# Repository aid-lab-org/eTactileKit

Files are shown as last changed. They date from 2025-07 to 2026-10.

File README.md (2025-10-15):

# eTactileKit: A Toolkit for Design Exploration and Rapid Prototyping of Electro-Tactile Interfaces

<p align="center">
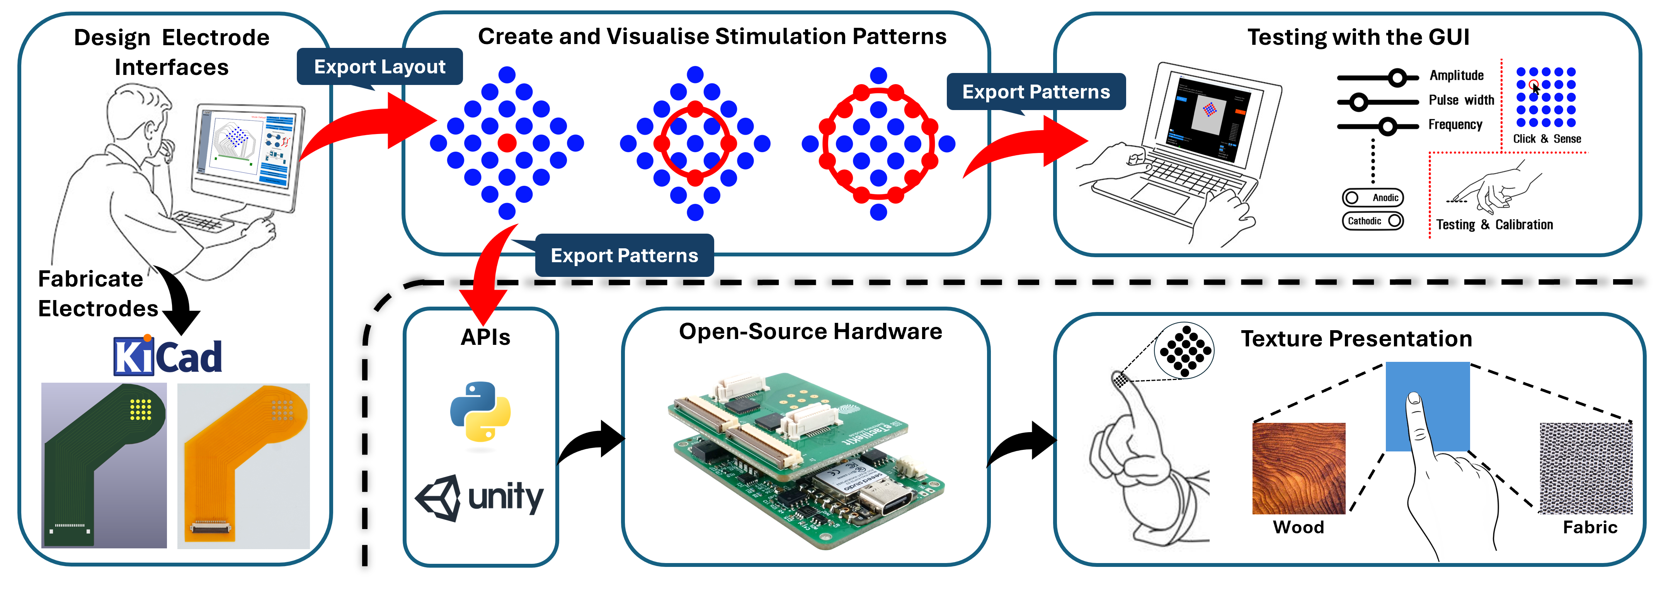
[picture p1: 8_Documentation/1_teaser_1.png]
Image Description
  
</p>

## Abstract

Electro-tactile interfaces are becoming increasingly popular due to their unique advantages, such as delivering fast and localised tactile response, thin and flexible form factors, and the potential to create novel tactile experiences. However, insights from a formative study with typical designers highlighted the lack of resources, limited access to information and complexity of software and hardware tools. This establishes a high barrier to entry and limits the ability to rapidly prototype and experiment with electro-tactile interfaces. To address these challenges, we propose eTactileKit, a scalable and accessible toolkit providing end-to-end support for designing and prototyping electro-tactile interfaces. eTactileKit comprises a hardware platform and a software framework for designing, simulating and exploring electro-tactile stimuli. We evaluated the impact and usability of eTactileKit through a three-week long take-home study, which demonstrated increased accessibility, ease of use, and the toolkit's positive impact on design workflow. Additionally, we implemented a set of use cases to demonstrate the toolkit's practicality and effectiveness across various applications.

More information about the toolkit can be found in our [paper](https://doi.org/10.1145/3746059.3747796). If you use this work, please cite our paper:

```
Praneeth Bimsara Perera, Ravindu Madhushan Pushpakumara, Hiroyuki Kajimoto, Arata Jingu, Jürgen Steimle,
and Anusha Withana. 2025. eTactileKit: A Toolkit for Design Exploration and Rapid Prototyping of
Electro-Tactile Interfaces. In The 38th Annual ACM Symposium on User Interface Software and Technology (UIST ’25),
September 28–October 01, 2025, Busan, Republic of Korea. ACM, New York, NY, USA, 17 pages.
https://doi.org/10.1145/3746059.3747796
```

## Contributors

**[Praneeth Perera](https://www.github.com/PraneethPerera99), [Ravindu Pushpakumara](https://www.github.com/RavinduMPK), [Hiroyuki Kajimoto](https://kaji-lab.jp/en/index.php?people/kaji), [Arata Jingu](https://hci.cs.uni-saarland.de/people/arata-jingu/), [Jürgen Steimle](https://hci.cs.uni-saarland.de/people/juergen-steimle/), [Anusha Withana](https://www.github.com/wdanusha)**

## Documentation

To use our toolkit, you can find the complete documentation [here](8_Documentation/DOCUMENTATION.md). This guide is here to help you navigate and make the most of eTactileKit.

## License

Shield: [][cc-by-sa]

This work is licensed under a
[Creative Commons Attribution-ShareAlike 4.0 International License][cc-by-sa].

[][cc-by-sa]

[cc-by-sa]: http://creativecommons.org/licenses/by-sa/4.0/
[cc-by-sa-image]: https://licensebuttons.net/l/by-sa/4.0/88x31.png
[cc-by-sa-shield]: https://img.shields.io/badge/License-CC%20BY--SA%204.0-lightgrey.svg

## Contact
If you have any issues with eTactileKit, please contact [Praneeth Perera](https://www.github.com/PraneethPerera99) or [Ravindu Pushpakumara](https://www.github.com/RavinduMPK)

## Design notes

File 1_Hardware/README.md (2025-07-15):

# Electro-tactile Toolkit Hardware Resources

This folder contains the:
1. PCB designs.
2. Fabrication outputs to manufacture PCBs.
3. Resource folder containing Schematics and images of the PCbs.

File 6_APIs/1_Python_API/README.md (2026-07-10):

# eTactileKit Python API

Reference Python client for the **eTactileKit** electro-tactile hardware (Seeed XIAO
ESP32-S3). It speaks a compact binary protocol over **Serial** or **WiFi (TCP)** and is
the source of truth the Unity API mirrors.

- `api/etactilekit.py` – high-level device driver (electrode mapping, stim parameters,
  patterns, voltage read-back).
- `api/communication.py` – transports: `CommunicationSerial` and `CommunicationWiFi`.
- `api/discovery.py` – UDP broadcast discovery to find kits by unique ID (WiFi/STA).
- `test_serial.py`, `test_wifi.py` – runnable examples (arrow keys change amplitude, `q` quits).

## Requirements

```bash
pip install pyserial          # required for serial
# pip install zeroconf        # optional: only for the mDNS browsing snippet below
```

Python 3.8+. WiFi discovery uses only the standard library (`socket`).

---

## Connection modes at a glance

| Mode | How you address the board | Use when | Needs |
|---|---|---|---|
| **Serial (USB)** | `COMx` + baud `921600` | one board, wired, lowest latency | USB cable |
| **WiFi · discovery (STA)** | unique 6-hex **ID** (auto) | **workshops / many kits on one router** | shared router |
| **WiFi · mDNS (STA)** | `etactilekit-<ID>.local` | single board, Python/macOS convenience | mDNS on the LAN |
| **WiFi · AP fallback** | fixed IP `192.168.4.1` | no router / 1 PC ↔ 1 kit | join the kit's SSID |
| **WiFi · DHCP reservation** | a fixed IP you reserve | permanent lab setup | router admin access |

Every board derives a **unique ID** from its MAC at boot (e.g. `A1B2C3`). Once the kits are
on the network, list them all — IDs and current IPs — with the discovery script:

```bash
python -m api.discovery
# Found 2 board(s):
#   id=A1B2C3  ip=192.168.1.42:8080  mode=STA  name=etactilekit-A1B2C3
#   id=7F0C11  ip=192.168.1.57:8080  mode=STA  name=etactilekit-7F0C11
```

Write each board's ID on its label so you can pick it later. **With a single kit you don't even
need the ID** — `connect_by_discovery()` (the default `device_id=None`) just connects to the only
board found.

---

## 1. Serial (USB)

```python
from api.etactilekit import ETactileKit

etk = ETactileKit()
etk.connect_etactilekit_to_serial("COM12", 921600, timeout=0.005)  # Linux/macOS: "/dev/ttyACM0"
```

Run the example:

```bash
python test_serial.py        # edit PORT_1_NAME / BAUDRATE at the top first
```

> The ESP32-S3 USB-Serial-JTAG RX FIFO drops bytes if flooded; `CommunicationSerial`
> already paces writes in small chunks, so any payload size is safe.

## 2. WiFi — discovery (recommended for STA / multiple kits)

All kits join **one router** you control, then you find them by ID over UDP broadcast —
no need to know the DHCP-assigned IP, and it works even where mDNS does not.

```python
from api.etactilekit import ETactileKit

etk = ETactileKit()
etk.connect_by_discovery(device_id="A1B2C3")   # None = the only board found
```

List every kit in the room first (also runnable as `python -m api.discovery`):

```python
from api.discovery import discover_devices

for d in discover_devices(timeout=1.0):
    print(d)   # {'id': 'A1B2C3', 'name': 'etactilekit-A1B2C3', 'ip': '192.168.1.42', 'port': 8080, 'mode': 'STA'}
```

`test_wifi.py` uses this path by default — set `TARGET_DEVICE_ID` to pick a specific kit.

> Requirements: the PC and the kits must be on the **same subnet**, and the router must
> allow UDP broadcast between clients (disable "client isolation"/"AP isolation").

## 3. WiFi — mDNS (secondary, Python only)

Each board also advertises `etactilekit-<ID>.local` and the `_etactilekit._tcp` service
(TXT `id=<ID>`). On Windows/macOS you can connect straight to the hostname:

```python
etk.connect_etactilekit_to_wifi("etactilekit-A1B2C3.local", 8080, timeout=0.10)
```

Or browse all of them with `zeroconf` (`pip install zeroconf`):

```python
from zeroconf import Zeroconf, ServiceBrowser

class Listener:
    def add_service(self, zc, type_, name):
        info = zc.get_service_info(type_, name)
        if info:
            ip = ".".join(map(str, info.addresses[0]))
            print(name, ip, info.properties.get(b"id"))

ServiceBrowser(Zeroconf(), "_etactilekit._tcp.local.", Listener())
```

> Note: **Unity/.NET cannot resolve `.local`** — that is why the UDP discovery above is
> the primary, cross-platform mechanism. Prefer it unless you are Python-only.

## 4. WiFi — AP fallback (no router)

If a board can't join the configured network it starts its own hotspot with a **unique
SSID** `eTactileKit_<ID>` (password `etactile@al`). Join that Wi-Fi, then:

```python
etk.connect_etactilekit_to_wifi("192.168.4.1", 8080, timeout=0.10)
```

One PC pairs with one kit this way (a PC can only join one AP at a time).

## 5. WiFi — DHCP reservation (deterministic, no discovery)

For a permanent setup, reserve a fixed IP per board on your router keyed by its MAC
(shown in the router's client list, or alongside the ID via `python -m api.discovery`). Then
just connect to that IP:

```python
etk.connect_etactilekit_to_wifi("192.168.1.50", 8080, timeout=0.10)
```

---

## After connecting (same for every mode)

```python
etk.set_electrode_mapping(list(range(32)))
etk.send_electrode_number(32)
etk.send_stimulation_mode(0)          # 0 monophasic, 1 biphasic
etk.send_stimulation_pulse_width(100) # µs
etk.send_stimulation_frequency(50)    # Hz
etk.send_channel_discharge_time(50)   # µs
print("sync:", etk.sync_check())      # echoes the configured electrode count
etk.send_stim_pattern([300] * 32)     # one 12-bit intensity (0–4095) per electrode
```

## Troubleshooting

| Symptom | Check |
|---|---|
| `discover_devices()` returns `[]` | PC and kits on the same router/subnet? Router blocking broadcast (client isolation)? Firewall blocking inbound UDP:8888? Did the board fall back to AP mode? (its `eTactileKit_<ID>` SSID would show in your Wi-Fi list). |
| "Multiple boards found" | Pass `device_id=` (or set `TARGET_DEVICE_ID`) with the kit's 6-hex code. |
| `.local` connects in Python but not Unity | Expected — use UDP discovery for Unity. |
| Can't connect in AP mode | Join the board's `eTactileKit_<ID>` Wi-Fi first; it's always `192.168.4.1`. |
| Serial: no device / garbled | Correct `COMx` and `921600` baud; not held by another app. |

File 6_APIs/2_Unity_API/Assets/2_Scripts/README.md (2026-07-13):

# eTactileKit Unity API

This package integrates the **eTactileKit** electro-tactile hardware into Unity. It speaks the same
byte protocol as the reference Python API and gives you a small, clean set of components to:

- connect to the device (Serial or WiFi),
- load a per-electrode **calibration profile** (intensity + hardware mapping),
- define **tactile patterns** in code, and
- trigger those patterns from **collider penetration** in your scene.

There is intentionally **no UI** and **no hand rig** - just the API plus an example controller you can
drop onto any colliders (a tracked finger, a tool tip, etc.).

> Deploying to a **Quest 3 standalone build** (running on the headset, WiFi-only)? See
> [APP_TRANSITION.md](APP_TRANSITION.md) for the full Android/IL2CPP transition guide. This README
> covers the PC / Quest Link setup that both targets share.

---

## 1. Project setup (do this first)

1. **Api Compatibility Level** → `.NET Framework`
   `Project Settings ▸ Player ▸ Other Settings ▸ Configuration ▸ Api Compatibility Level`.
   Required for `System.IO.Ports` (serial) and `System.Net.Sockets` (WiFi).
2. **Active Input Handling** → `Both`
   `Project Settings ▸ Player ▸ Other Settings ▸ Active Input Handling`.
3. **Install the Meta XR All-in-One SDK** (`com.meta.xr.sdk.all`) via the Package Manager (Unity
   Registry / Git URL), plus any other plugins your headset needs. This provides the VR hands /
   controllers you will attach the probe colliders to.

> Serial note: on Windows the device typically enumerates as `COMx` (e.g. `COM12`) at `921600` baud.
>
> WiFi note: Unity connects by **IP address** or by **UDP discovery** (see §5). Unity/.NET has
> **no mDNS resolver**, so the board's `etactilekit-<ID>.local` hostname will **not** resolve here -
> use discovery (recommended) or a raw IP. Each board self-labels with a unique 6-hex `ID` (from its
> MAC); list every kit's ID and IP with the Python discovery script (`python -m api.discovery`), or
> read them from the Unity Console when the manager connects. With a single kit you need no ID at all.

---

## 2. How it fits together

```text
HapticController            (your scene)
  ├─ reads probe colliders, finds the deepest penetration each frame
  ├─ resolves the touched object's HapticProfile via HapticProfileProvider
  └─ plays the profile's pattern (frame timing + Once/Loop/Bounce)
        │
        ▼
ETactileKitManager         (connection + calibration + global params)
  └─ SendFrame(states): on-electrodes → calibrated intensity, off → 0
        │
        ▼
ETactileKit                (0_eTactileKitAPI: byte protocol port)
  └─ remaps to hardware channels, packs uint16 LE, writes one packet
        │
        ▼
Serial / WiFi handler  →  ESP32 hardware
```

| Concept | Script | Role |
|---|---|---|
| Device driver | `0_eTactileKitAPI/ETactileKit.cs` | Low-level protocol (no Unity types). |
| Transport | `SerialHandler.cs` / `WiFiHandler.cs` | Serial (chunked) / TCP I/O. |
| Discovery | `0_eTactileKitAPI/ETactileKitDiscovery.cs` | Find kits on the LAN by unique ID (UDP broadcast). |
| Manager | `1_Haptics/ETactileKitManager.cs` | Connection, global params, calibration, `SendFrame`. |
| Calibration | `CalibrationProfile.cs` | Per-electrode intensity + hardware mapping. |
| Patterns | `PatternDB.cs` | Code-defined `HapticPattern`s (frames + playback mode). |
| Profile asset | `HapticProfile.cs` | Which pattern + trigger depth for an object. |
| Provider | `HapticProfileProvider.cs` | Attaches a profile to an object. |
| Controller | `HapticController.cs` | Penetration → pattern playback. |

---

## 3. Calibration

Calibration stores **only** two things per electrode: the hardware **mapping** and the **intensity**
applied when that electrode is on. Everything else (pulse width, frequency, stim mode, …) is a global
parameter on the manager.

- **Generate a profile** with the **eTactileKitExplorer** desktop application, which exports the
  calibration JSON used here (per-electrode `mapping` + `intensity`).
- **Where it lives:** put the profile in `Assets/StreamingAssets/`. A sample is provided at
  `Assets/StreamingAssets/template_32_electrode_calibration.json` so it travels with the cloned repo.
- On the `ETactileKitManager`, set **Default Calibration File Name** to the file name inside
  `StreamingAssets` (default: `template_32_electrode_calibration.json`). It loads automatically on
  `Start` when no profile has been set in the inspector.
- In the manager inspector, **Calibration Profile** lets you **Import JSON** / **Export JSON** (the
  same format eTactileKitExplorer produces) and tune each electrode's **Intensity** directly.

### Global amplitude (gain)

The manager's **Amplitude Gain** slider scales **every** electrode's calibrated intensity as it is
sent, so you can adjust overall strength in one place while keeping the per-electrode balance from
calibration:

- Range **0 – 1.5**, default **1** (1 = use the calibration values exactly as they are).
- The scaled value is **rounded to the nearest integer** (the hardware only takes integers) and
  **clamped to the 12-bit DAC range** (0 – 4095), so a high calibration value with a gain above 1 can
  never overflow.
- It applies **live** - drag the slider while playing and the next frame uses it; no reconnect or
  re-calibration needed. It does not modify the calibration profile itself.
- From code: `manager.AmplitudeGain = 0.8f;` (clamped to the same range).

The manager runs this one-time setup on connect (mirrors the Python reference order):

```text
set mapping → electrode number → stim mode → polarity → pulse width →
sense pulse height → sense pulse width → channel discharge time → frequency →
read HV513 count → sync check
```

---

## 4. Creating a tactile pattern

Patterns are defined in code in `1_Haptics/PatternDB.cs`. A pattern is a list of **frames**; each
frame **lists the electrode ids that are ON** (value 1) plus an **on-time** and **off-time**
(milliseconds). When a frame is sent, each listed electrode is driven at its calibrated intensity and
all others are off. Listing active ids keeps patterns **independent of the electrode count** - that
count comes from the loaded calibration profile and is never hard-coded.

A pattern also has a **playback mode**:

- `Once` – play the frames one time, then stay silent until the probe re-enters.
- `Loop` – repeat frames `0..N-1` continuously while penetrated.
- `Bounce` – play frames forward then backward (ping-pong) while penetrated.

The two example patterns (`HorizontalScan`, `VerticalScan`) are authored by hand for the default
"Fingerpad TactDeform 32" layout - a 6×6 grid with the four corners removed:

```text
        col0  col1  col2  col3  col4  col5
 row0:    ·     0     1     2     3     ·
 row1:    4     5     6     7     8     9
 row2:   10    11    12    13    14    15
 row3:   16    17    18    19    20    21
 row4:   22    23    24    25    26    27
 row5:    ·    28    29    30    31     ·
```

`HorizontalScan` lights one **column** per frame (a vertical bar moving left→right); `VerticalScan`
lights one **row** per frame.

Patterns can be authored two ways:

- **Manual** – list the active ids per frame (`HorizontalScan`, `VerticalScan`). Best for spatial
  shapes tied to your electrode layout.
- **Programmatic** – build frames with a loop from the electrode count (`Blink`, `Buzz`). These take
  the active count so they work for any layout, and the result is cached:
  - `Blink` – all electrodes on for 200 ms, off for 200 ms, looping.
  - `Buzz` – one electrode per frame, 40 ms on / 0 ms off, scanning through all of them.

To add your own pattern:

1. Add a value to the `PatternId` enum.
2. Build a `HapticPattern` – either list the active ids per frame, or generate them in a loop (see
   `Blink` / `Buzz`).
3. Return it from `PatternDB.Get(id, electrodeCount)`.

If your hardware numbers electrodes differently, adjust the ids per frame to match. Ids outside the
active electrode range are ignored with a warning.

---

## 5. Example scene, step by step

1. **Manager** – create an empty GameObject, add `ETactileKitManager`.
   - **Serial:** choose `Serial` and set `Port Name` / `Baud Rate`.
   - **WiFi (recommended, STA):** choose `WiFi` and leave `Use Discovery` on. For a **single kit**,
     leave `Target Device Id` blank - it connects to the only board found. For **several kits**, set
     `Target Device Id` to the intended board's 6-hex code (from its label, the Unity Console log, or
     `python -m api.discovery`). The manager broadcasts on connect and resolves the kit's current IP
     automatically, so many kits can share one router. `Discovery Timeout Ms` sets how long it waits.
   - **WiFi (manual / AP fallback):** turn `Use Discovery` off (or when discovery finds nothing it
     falls back automatically) and set `IP Address` - a fixed/reserved IP, or `192.168.4.1` after
     joining a board's own `eTactileKit_<ID>` hotspot. `Wifi Port` is `8080`.
   - Set **Default Calibration File Name** to your profile in `StreamingAssets` (the sample
     `template_32_electrode_calibration.json` works out of the box), or **Import JSON** your own.
   - Leave the global stim params at their defaults (Biphasic, 100 µs, 50 Hz) unless you have reason
     to change them.
2. **Profile asset** – `Assets ▸ Create ▸ eTactileKit ▸ Haptic Profile`.
   - Pick a `Pattern Id` (e.g. `HorizontalScan`) and a `Min Penetration Depth Meters` (e.g. `0.002`).
3. **Touchable object** – on the object you want to feel:
   - add a `Collider`,
   - add `HapticProfileProvider` and assign the profile,
   - put the object on a dedicated layer (e.g. create an `Interactable` layer).
4. **Probe(s)** – add a `SphereCollider` to each finger tip / tool tip that should trigger haptics,
   and put them on a dedicated **probe layer** (e.g. create a `Probe` layer). No Rigidbody is
   required - penetration is computed directly, and probes are found automatically by layer.
5. **Controller** – add `HapticController` (anywhere):
   - assign `Manager`,
   - set `Probe Layer` to your probe layer,
   - set `Interactable Layer` to the touchable object's layer.
6. **Kill switch** – add a `HapticKillSwitch` component (e.g. on the manager's GameObject); assign
   `Manager` and your left/right `OVRHand`s. Emergency-stop gesture: middle + ring + pinky pinch held
   ~1 s (see §6).
7. **Play** – push a probe into the object past the threshold depth; the pattern plays at the
   calibrated intensity and stops when the probe withdraws.

> **Layers are the #1 cause of "nothing is detected".** The probe collider (finger/tool tip) and the
> touchable object must be on **two different layers**, and each must be selected on the controller:
> the finger's layer → `Probe Layer`, the object's layer → `Interactable Layer`. A finger left on the
> `Default` layer while `Probe Layer` points at a `Haptic Probe` layer will never be found - the
> controller logs a warning when it finds no probes. Use a dedicated probe layer (not `Default`) so
> unrelated colliders are not scanned. No Rigidbody is needed and the probe may be `Is Trigger`.
>
> Playback is **tied to the contacted collider**. While the same collider stays penetrated past the
> threshold the pattern keeps advancing - it is *not* replayed from the start each frame. A different
> object (or leaving and re-entering) starts the pattern over. A momentary loss of contact (physics
> jitter, depth chatter at the threshold) within `Reacquire Grace Seconds` (default 0.2 s) **resumes**
> at the current frame instead of restarting; set it to 0 to restart on any loss. Enable
> `Log State Changes` on the controller to watch start/resume/suspend transitions in the Console.
>
> Tip: enable **Run Connection Test** on the manager to pulse all electrodes on/off after connecting,
> as a quick hardware check (it ignores controller input while running).

---

## 6. Safety

- **Emergency stop = hand gesture.** Add a `HapticKillSwitch` component and assign the manager plus
  your `OVRHand`s. Holding an uncommon pose - **middle + ring + pinky pinched to the thumb** (index
  left free) for ~1 s on either hand - immediately sends OFF and disconnects. The same gesture works
  on PC / Quest Link and on the standalone headset (no keyboard needed).
- OFF is also sent automatically on disconnect, on `OnDisable`, and on application quit.
- **Amplitude Gain** above `1` drives every electrode *harder than calibrated* — raise it slowly and
  only if the calibrated level is too weak. `0` silences the output without disconnecting.

---

## 7. Building for the Quest 3 headset (standalone)

The same project also runs **directly on the Quest 3** (no PC). The code already builds for both
targets — serial is auto-excluded on Android, the calibration loads from inside the APK, and the
`HapticKillSwitch` gesture is identical — so this is mostly build settings. Full detail, deployment
and troubleshooting are in [APP_TRANSITION.md](APP_TRANSITION.md); the essentials:

1. **Install Android Build Support** (Unity Hub), then `File ▸ Build Settings ▸ Android ▸ Switch
   Platform`.
2. **Run the Meta XR Project Setup Tool** (`Meta ▸ Tools ▸ Project Setup Tool`, Android tab → *Apply
   All*) — it sets IL2CPP, ARM64, Vulkan, API levels, etc.
3. **XR Plug-in Management ▸ Android** → enable **Oculus**; enable **Hand Tracking Support** on
   `OVRManager` (needed for the probes and the kill switch).
4. **Player ▸ Android:** Scripting Backend **IL2CPP**, Target Architecture **ARM64**, Api Compatibility
   **.NET Framework**, **Internet Access = Require** (adds the `INTERNET` permission), unique Package Name.
5. **Manager:** Connection Type **WiFi**, **Use Discovery off**, **IP Address** = the kit's IP (STA: a
   reserved/static IP; AP: `192.168.4.1`), port `8080`.
6. **Deploy:** enable Developer Mode on the Quest, connect USB-C, allow USB debugging, then **Build &
   Run** (`Ctrl+B`). View logs with `adb logcat -s Unity`.

On the headset the kit is reached over **WiFi only** (serial is desktop-only); everything else —
patterns, calibration, penetration → haptics — behaves exactly as over Quest Link.

To switch a headset-configured project **back to PC / Quest Link**, see
[APP_TRANSITION.md §11 (Android → Windows)](APP_TRANSITION.md) — it's a platform toggle with **no code
changes** (serial, file-based calibration and discovery re-enable themselves automatically).

---

## 8. Troubleshooting

| Symptom | Check |
|---|---|
| No collisions detected at all | Finger/tool collider's Layer must match the controller's `Probe Layer` (a `Default`-layer finger with a different `Probe Layer` is never found - watch for the "found no probe colliders" warning). Object's Layer must be in `Interactable Layer`, and the two must differ. |
| Detected but no stimulation | Penetration ≥ profile `Min Penetration Depth Meters`? Profile `Enable Haptics` on? Probe actually overlapping (not just touching) the object? Device connected and not in Run Connection Test? **Amplitude Gain** not 0? |
| Stimulation too weak / too strong | Adjust the manager's **Amplitude Gain** (0–1.5, default 1) — it scales all calibrated intensities live. If only *some* electrodes feel wrong, the per-electrode balance is off: re-calibrate in eTactileKitExplorer, or tune individual **Intensity** values in the manager's calibration list. |
| "Cannot connect without a valid calibration profile" | Assign / import a valid profile (mapping must be a permutation of `0..count-1`). |
| WiFi: "No kits discovered" | PC and kits on the same router/subnet? Router allowing UDP broadcast (disable client/AP isolation)? Windows Firewall allowing Unity inbound UDP:8888? Did the board fall back to AP mode? (its `eTactileKit_<ID>` SSID would show in your Wi-Fi list). Manager falls back to `IP Address` when nothing answers. |
| WiFi: connected to the wrong kit | Set `Target Device Id` to the intended board's 6-hex code (blank = first found). |
| WiFi: `*.local` never connects | Expected - Unity/.NET can't resolve mDNS; use `Use Discovery` or a raw IP. |
| Wrong / missing port | Correct `COMx` and `921600` baud; device plugged in; not held by another app. |
| "Electrode id N is out of range" warning | A pattern frame lists an id ≥ the calibration's electrode count; fix the ids in `PatternDB.cs`. |
| Garbled serial data | Confirm Api Compatibility Level is `.NET Framework`. |

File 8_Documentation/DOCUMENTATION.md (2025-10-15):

# <span style="color: red;">eTactileKit - An Electro-tactile Toolkit for Design Exploration and Rapid Prototyping - Documentation</span>

Welcome to the official documentation for the **Electro-Tactile Research Toolkit**. This toolkit provides comprehensive resources for hardware design, software development, and research in electro-tactile feedback.

---

## Table of Contents

- [1. Overview](#1-overview)
- [2. Features](#2-features)
- [3. Getting Started](#3-getting-started)
- [4. Hardware Design](#4-hardware-design)
  - [4.1. Ordering eTactileKit PCBs](#41-ordering-etactilekit-pcbs)
  - [4.2. Creating Your Own PCB](#42-creating-your-own-pcbs)
- [5. Firmware](#5-firmware)
  - [5.1. Overview of Pulse Parameters](#51-overview-of-pulse-parameters)
  - [5.2. Stimulation Configurations and Experiences](#52-stimulation-configurations-and-experiences)
- [6. Electrode Design Tool](#6-electrode-design-tool)
  - [6.1. Creating 2D Electrode Layouts for PDF Exports](#61-creating-2d-electrode-layouts-for-pdf-exports)
  - [6.2. Creating PCB Electrode Layouts](#62-creating-pcb-electrode-layouts)
  - [6.3. Creating Electrodes on 3D Surfaces](#63-creating-electrodes-on-3d-surfaces)
- [7. Tactile Pattern Creator](#7-tactile-pattern-creator)
  - [7.1. Setup the Pattern Creator](#71-setup-the-pattern-creator)
  - [7.2. Creating 2D Electrode Patterns Using Library](#72-creating-2d-electrode-patterns-using-library)
  - [7.3. Creating Customized 2D Electrode Patterns](#73-creating-customized-2d-electrode-patterns)
  - [7.4. Creating 3D Electrode Patterns Using Library](#74-creating-3d-electrode-patterns-using-library)
  - [7.5. Creating Customized 3D Electrode Patterns](#75-creating-customized-3d-electrode-patterns)

- [8. Real-Time Hardware Access GUI](#8-real-time-hardware-access-gui)
  - [8.1. 2D MODE (for 2D patterns)](#81-2d-mode-for-2d-patterns)
  - [8.2. 3D MODE (for 3D patterns)](#82-3d-mode-for-3d-patterns)
- [9. API Integration](#9-api-integration)
  - [9.1. Python API](#91-python-api)
  - [9.2. Unity API](#92-unity-api)
- [10. Examples & Demos](#10-examples--demos)
  - [10.1. Interactive Virtual Reality Button in Unity 3D](#101-interactive-virtual-reality-button-in-unity-3d)
- [11. FAQs](#11-faqs)
- [12. License](#12-license)

---

## 1. Overview

The **eTactileKit** is an end-to-end solution for researchers and developers working on electro-tactile applications. The toolkit aims to bridge the gap between hardware and software by offering tools to design, simulate, and implement electro-tactile patterns effectively.

<p align="center">
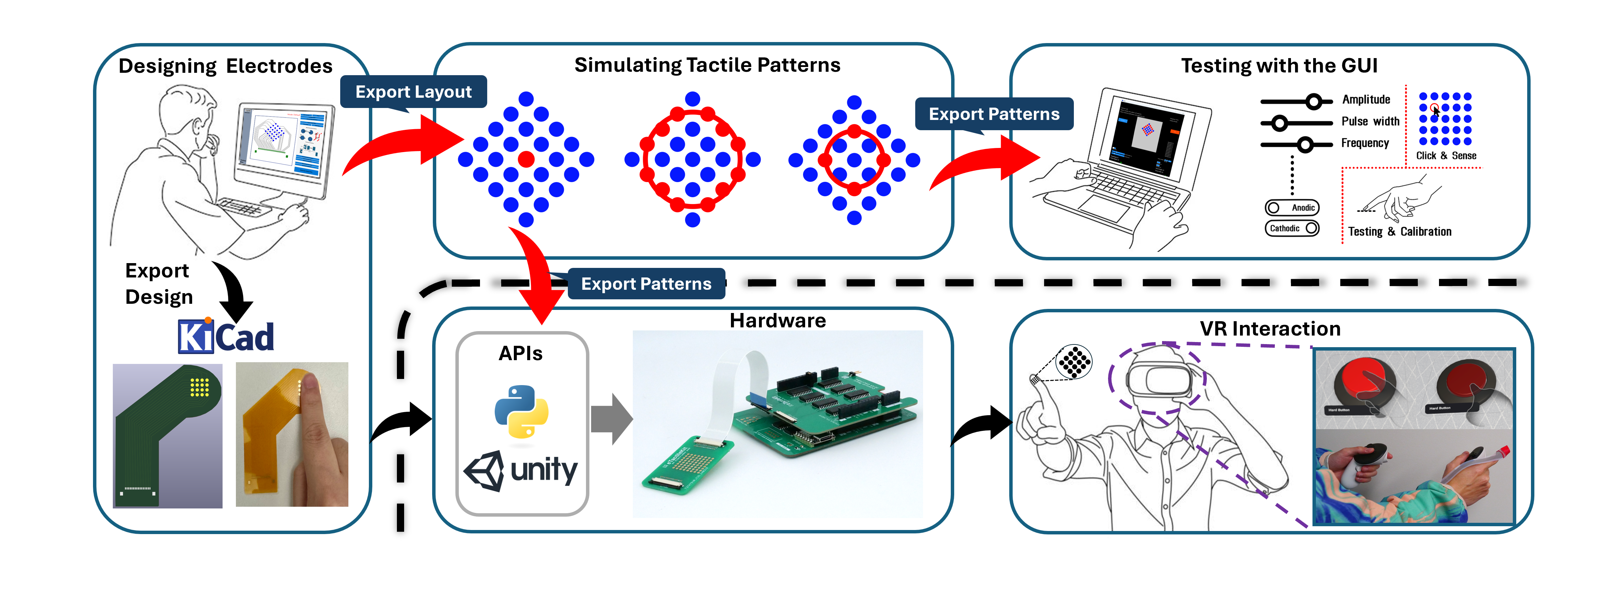
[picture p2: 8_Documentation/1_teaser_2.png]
  
  <p align="center"><i><b>Using eTactileKit to design electrode, simulate and visualize patterns. testing and calibrating stimuli and using the APIs to develop a VR application</b></i></p>
</p>

This documentation will guide you through the necessary steps and guidelines to follow to get started with eTactileKit.

---

## 2. Features

- Modular and extensible **hardware design** that can support customised electrode layouts.
- Easy-to-use **Software GUI** for electrode design for various 2D and 3D scenarios.
- **Pattern Creator** to create and visualise tactile patterns.
- **Real-time hardware access and control GUI** for debugging and testing outputs.
- **Comprehensive documentation** for quick onboarding and how-to-dos.
- **APIs** for Python and Unity for seamless integration with widely adopted platforms.

---

## 3. Getting Started

### Clone this GitHub repository or download and unzip the zip file.

### Need to try out a quick tactile pattern on your fingers? We got you covered!

Follow the steps below:

1. **Ensure that the Jumper `J3` as denoted [here](#4-hardware-design) is connected (Not needed for the compact hardware setup)**

2. **Connect the board to the computer via a UCB-C to USB-A cable**

3. **Let's follow all the steps as described in [Section 8](#81-2d-mode-for-2d-patterns)**
  
    Here when selecting the array select `electrodes_array_mainboard.json` from the `array` folder and the pattern `example_main_board_0.json`, from the `pattern` and follow the steps ahead.

4. **You can have the same array and try out the following different patterns returning from step 01 above.**
  `example_main_board_1.json`
  `example_main_board_2.json`
  `example_main_board_3.json`
  `example_main_board_4.json`

---

## 4. Hardware Design

The hardware comprises of 2 main components:

1. The main controller
2. The switching controller

The main controller is responsible for the high voltage generation, and a current controller, a microcontroller that handles commands and processes commands. The switching controllers can be stacked on the main controller. You can stack multiple switching controllers on top of each other for a higher number of electrode applications.

The main controller board itself can be used standalone with its onboard electrodes. This can be used for initial testing and validation of hardware.

## Compact Version

<p align="center">
  Image Description
  <p align="center"><i><b>PCB design of the main controller and the switching board and their stacked view</b></i></p>
</p>

In compact version, a single switching PCB supports upto 32 electrodes.

## Easily solderable (Large form factor) version

<p align="center">
  Image Description
  <p align="center"><i><b>PCB design of the main controller and the switching board and their stacked view</b></i></p>
</p>

**Important: Make sure that the jumper `J3` annotated above is in place when using the board standalone. If stacked this should be unplugged and `DIN` should be plugged.**

For stacking the boards, you can align the Male and Female headers on the two boards as shown below. The Headers are kept separately to easily identify the alignment. **!!Do not push the boards to hard since it might make it harder to remove!!**

<p align="center">
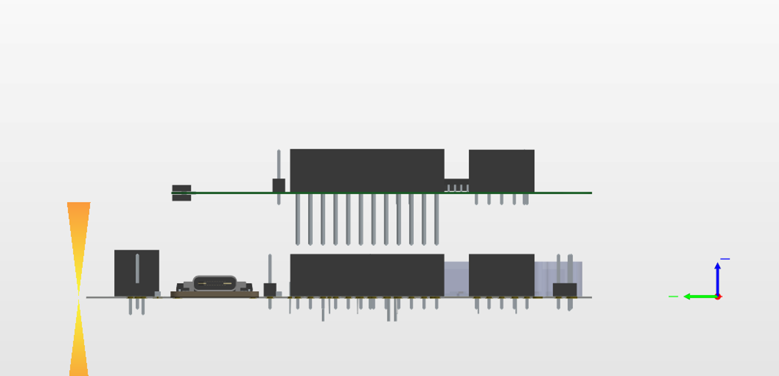
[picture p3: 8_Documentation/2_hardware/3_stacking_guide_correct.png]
  
  <p align="center"><i><b>PCB design of the main controller and the switching board and their stacked view</b></i></p>
</p>

For applications requiring more than 64 electrodes, multiple switching circuits can be stacked on top of each other. **!!Please follow the guidelines below!!**

1. Plug the jumper `DIN` as before on the first stack
2. Do not plug the jumper for stacks starting from the second stack
3. Connect the `DOUT` from the first stack to the `DIN` of the second stack using a female-to-female jumper wire.
4. Continue step 03 above for the other stacks.

**!!You should not plug the jumper starting from stack 2!!**

## Hardware architecture
The hardware architecture of how the hardware functions is shown below. A more detailed explanation can be found in our paper.

<p align="center">
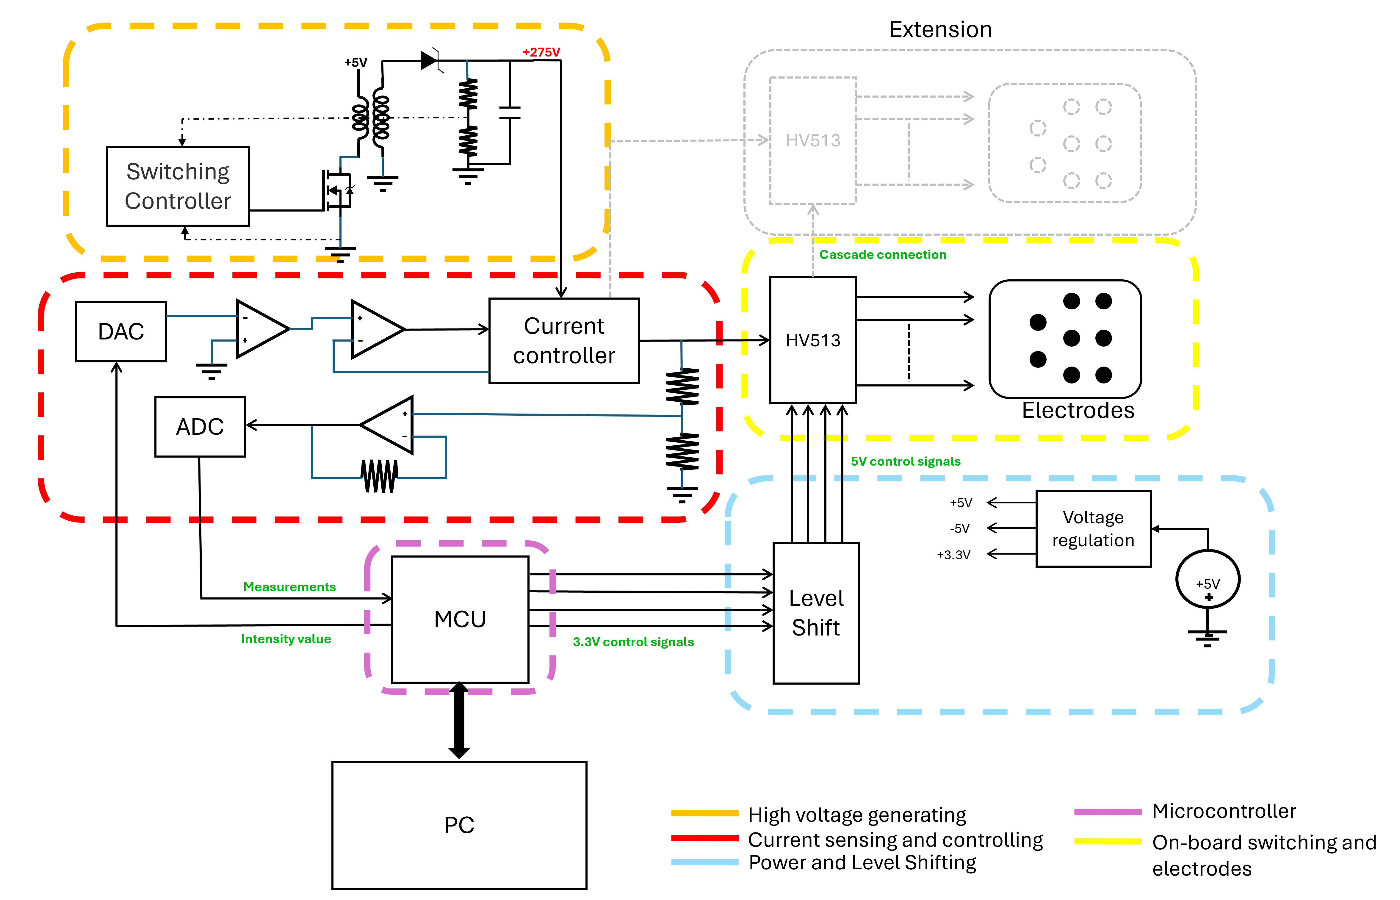
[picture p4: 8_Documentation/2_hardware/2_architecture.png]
  
  <p align="center"><i><b>Hardware architecture</b></i></p>
</p>

**Note: Current limiting**
The `J2` jumper is used to limit the current. So, if you need the maximum current output, you can short circuit the `J2` jumper. 
**If you need to limit the current, you can connect a current limiting diode to the `J2` jumper (`J2` is a female jumper.)**

<p align="center">
  Image Description
  <p align="center"><i><b> J2 jumper in compact Hardware setup </b></i></p>
</p>

### 4.1 Ordering eTactileKit PCBs

All the manufacturing files to order PCBs are set at the location below.

```bash
1_Hardware/03_Fabrication_Files
```

You can follow the resources mentioned in [Section 6.2](#62-creating-pcb-electrode-layouts) to send these files for manufacturing to get your own PCB designed. Both the `Controller Board` and the `Switching Board` are available. The `Bill of Material` sheet contains all the part details and the required components. You can use this to place the component orders.

### 4.2 Creating your own PCBs

The PCB design was done using [Altium](https://www.altium.com/). The complete PCB project can be found in the location below.

```bash
1_Hardware/02_PCB_Designs
```

You can edit this project or incorporate the above into your projects for further improvisation. You can find the Schematics and other resources at the location below.

```bash
1_Hardware/04_Resources
```

---

## 5. Firmware

eTactileKit hardware is controlled by a microcontroller [Seed Studio esp32s3](https://wiki.seeedstudio.com/xiao_esp32s3_getting_started/). It is responsible for sending commands to control hardware and handling communication between the PC and hardware.

Firmware can be uploaded using [Arduino IDE](https://www.arduino.cc/en/software) by adding the necessary ESP32 boards package as described [here](https://wiki.seeedstudio.com/xiao_esp32s3_getting_started/). Note that if you are using arduino the main.cpp file should be renamed as a `.ino`.

You can find the firmware at the following location and follow the steps to install it on the microcontroller.

```bash
2_Firmware\EtactileKit
```

The firmware supports similar hardware, and since our toolkit hardware is similar to Kajimoto Sensei's hardware, you can use the same firmware **by making sure you do the following change**

<p align="center">
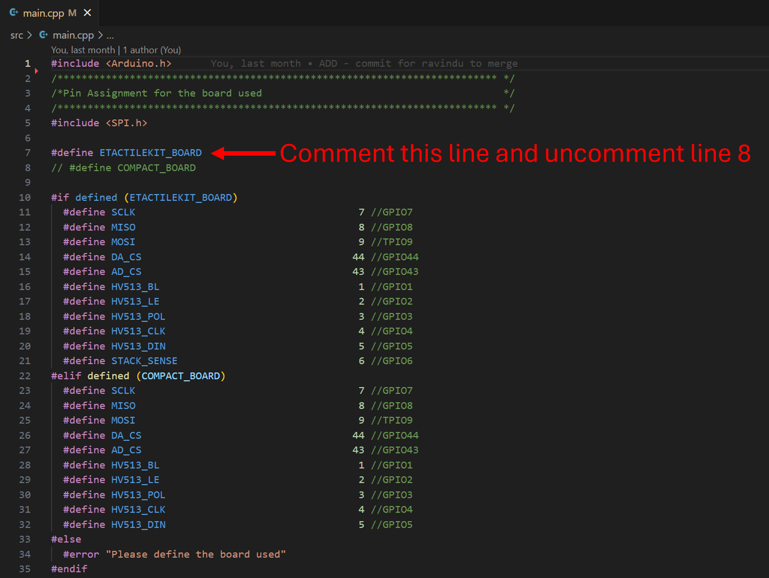
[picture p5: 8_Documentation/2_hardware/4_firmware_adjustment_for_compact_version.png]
  
  <p align="center"><i><b>Hardware architecture</b></i></p>
</p>

### 5.1 Overview of Pulse Parameters

It's important to understand the stimulation pulse parameters before we start to understand the firmware. Here is a list of abbreviations used to represent the parameters of the system.

| Parameter | Description |
| --- | ---  |
| `PW` | Pulse width of the stimulation pulse |
| `PH` | Pulse height of the stimulation pulse |
| `DT` | Channel Discharge time |
| `SF` | Stimulation Frequency |
| `SPW` | Pulse width of the impedance measure pulse |
| `SPH` | Pulse height of the impedance measure pulse |
| `LST` | Loop stabilization time |
  
<p align="center">
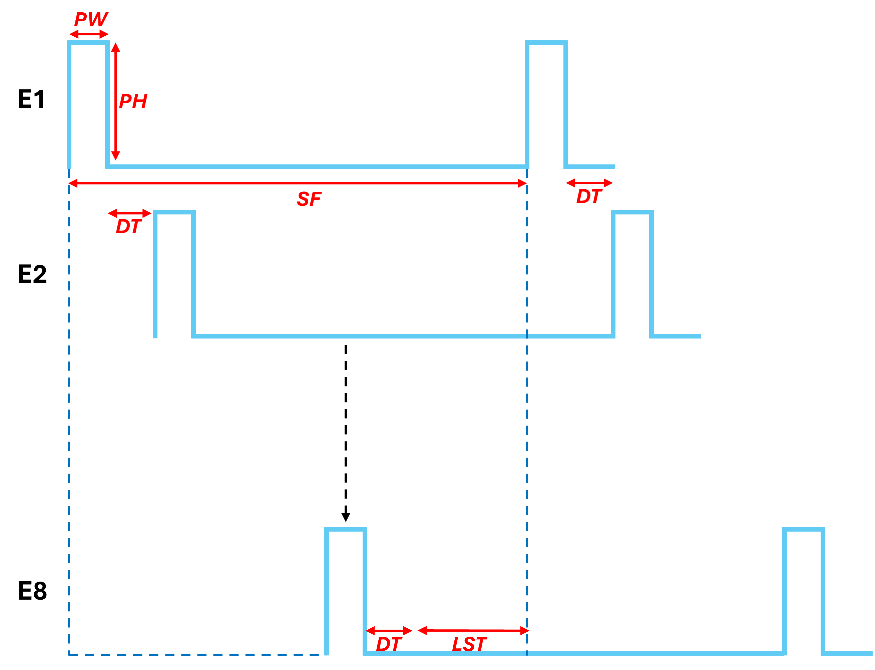
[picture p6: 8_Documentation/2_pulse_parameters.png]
  
  <p align="center"><i><b>Timing diagram of eTactilekit with 8 electrodes</b></i></p>
</p>

Each electrode is scanned by **time division multiplexing.** However, when an electrode is scanned, activation is decided based on the stimulation pattern command sent from the **host device (PC).** Each time an electrode is activated, all the others will be deactivated. To make it more technical, when one electrode is sourcing current, all the others are sinking current (This is particularly called **Anodic stimulation**). On the other hand, in **Cathodic Stimulation**, when one electrode is sinking current, all the other electrodes will be sourcing current.

The **pulse height (PH)** and **pulse width (PW)** parameters are responsible for the amount of intensity. Once an electrode is activated a delay of time **DT (discharge time).** In other words, this is the **inter-channel idle period.** After all the electrodes(8 in the above case) have been scanned the time to satisfy the **stimulation frequency (SF)** will be delayed, called the **loop stabilization time (LST).**

Furthermore, the hardware can sense the amount of current drawn through each electrode, which allows eTactileKit to do sensing. This can be understood better in the hardware section. In order to sense, a **lower amplitude (SPH)** and a certain **pulse width (SPW)**(unnoticeable pulse) can be set to measure the amount of actual current drawn, and thereby calculate the impedance across the electrodes.

### 5.2 Stimulation Configurations and Experiences

In general, the sensation rendered by electro-tactile is cutaneous vibrations. However, electro-tactile has been shown to render novel tactile experiences including [thermal presentation](https://ieeexplore.ieee.org/abstract/document/9517195), [compliance](https://dl.acm.org/doi/10.1145/3613904.3641907) and many more interesting sensations. These sensations are achieved by triggering various types of mechanoreceptors within our skin using various methods. Thus, having a basic understanding of how pulse parameters and configurations affect the sensation is important.

etactileKit provides the ability to do Anodic and Cathodic stimulation. Anodic is where a single electrode is sourcing current, and all the other electrodes act as cathodes, and Cathodic is vice versa. The interesting fact is they render different sensations. Anodic, the most widely used rendered vibration sensations, while Cathodic tends to present a pressure/sticky sensation.

In reference to the pulse parameters mentioned in [section 5.1](#51-overview-of-pulse-parameters):
`PH` - is the amount of current delivered, obviously controlling the strength of the stimulation.
`PW` - Lower pulse width enables deeper travel and activation of various mechanoreceptors. Lowering the pulse width gives more of a cutaneous/pain sensation and increasing it reduces this but increases the intensity felt.
`SF` - A higher frequency tends to give a smoother sensation. However, larger frequencies are not perceivable by the skin and might not render effective tactile information. However, lowering the frequency will enable feeling individual pulse activation, giving a sensation of exploding bubbles, if tried on the fingertips.

However, the aforementioned does not limit the possibilities of electro-tactile sensations, and the toolkit provides full access to tuning these pulse parameters using its GUI for the users to explore novel experiences.

---

## 6. Electrode Design Tool

The electrode design tool is a GUI-based tool to assist in creating custom electrode layouts.
The tool supports creating:

1. Electrode layouts that can be exported in **PDF format** to support inkjet printing and laser cutting
2. Electrode layouts for **PCB fabrication**
3. Electrode layouts for **3D surfaces**

<p align="center">
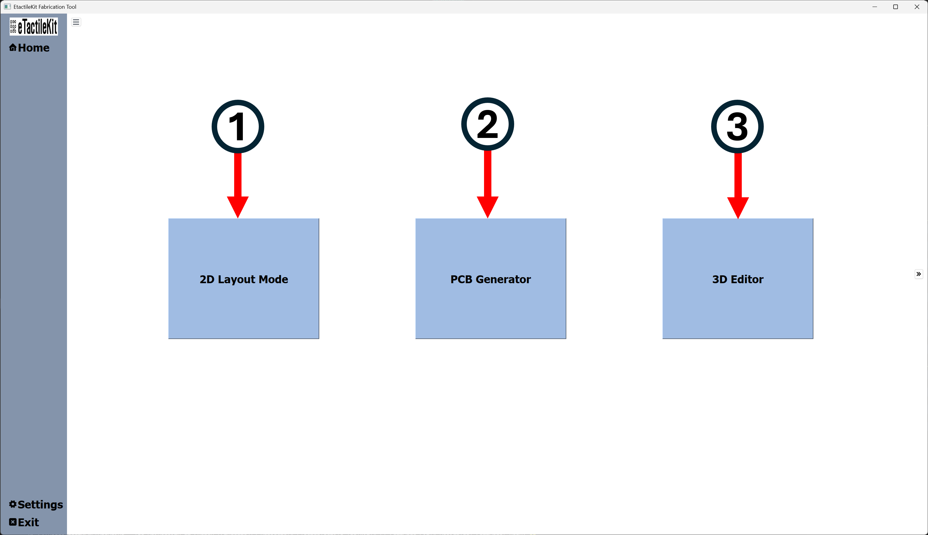
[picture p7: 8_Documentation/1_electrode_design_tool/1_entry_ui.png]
  
  <p align="center"><i><b>Entry layout to the electrode design</b></i></p>
</p>

The tool is developed using [Python](https://www.python.org/downloads/). Installing the required libraries is important to the functionality of the tool. 

If you are using an older version of Visual Studio, make sure to have Visual Studio 2022 C++ build tools installed. You can install them by running the following command in your CMD or shell. If you already have the C++ build tools installed, you can proceed to the next steps.

```bash
winget install Microsoft.VisualStudio.2022.BuildTools --force --override "--wait --passive --add Microsoft.VisualStudio.Component.VC.Tools.x86.x64 --add Microsoft.VisualStudio.Component.Windows11SDK.22621"
```

Follow the steps below to initiate the tool:

1. **Locate the project folder at the below location and open the Command Line Interface(CLI) and navigate to the below location**

    ```bash
    3_Electrode_Design_Tool
    ```

2. **Create a virtual environment in your project directory(Recommended)**

    ```bash
    >> pip install virtualenv
    ```

    Now let's create a virtual environment named `electoolenv`. You can use your preferred name.

    ```bash
    >> virtualenv electoolenv
    ```

    Navigate to the Scripts folder

    ```bash
    >> cd electoolenv/Scripts
    ```

    Activate the environment.

    ```bash
    >> activate
    ```

    Now navigate to the `3_Electrode_Design_Tool` folder using `cd ..` twice.

3. **Use the requirements file to install the required libraries**

    ```bash
    >> pip install -r requirements.txt
    ```
  
4. **Open VScode project in the `3_FabricationTool_App` Folder**

    Locate the main.py file in the following location and run it

    ```bash
    3_FabricationTool_App\src\main.py
    ```

Now you are ready to go. Happy electrode designing!

### 6.1 Creating 2D Electrode Layouts for PDF Exports

Below is the view of a simple and finalised 3*3 electrode layout ready to be exported. The annotations will help you guide through the steps described below to design your own customised electrode layouts that can be exported as PDF files.

<p align="center">
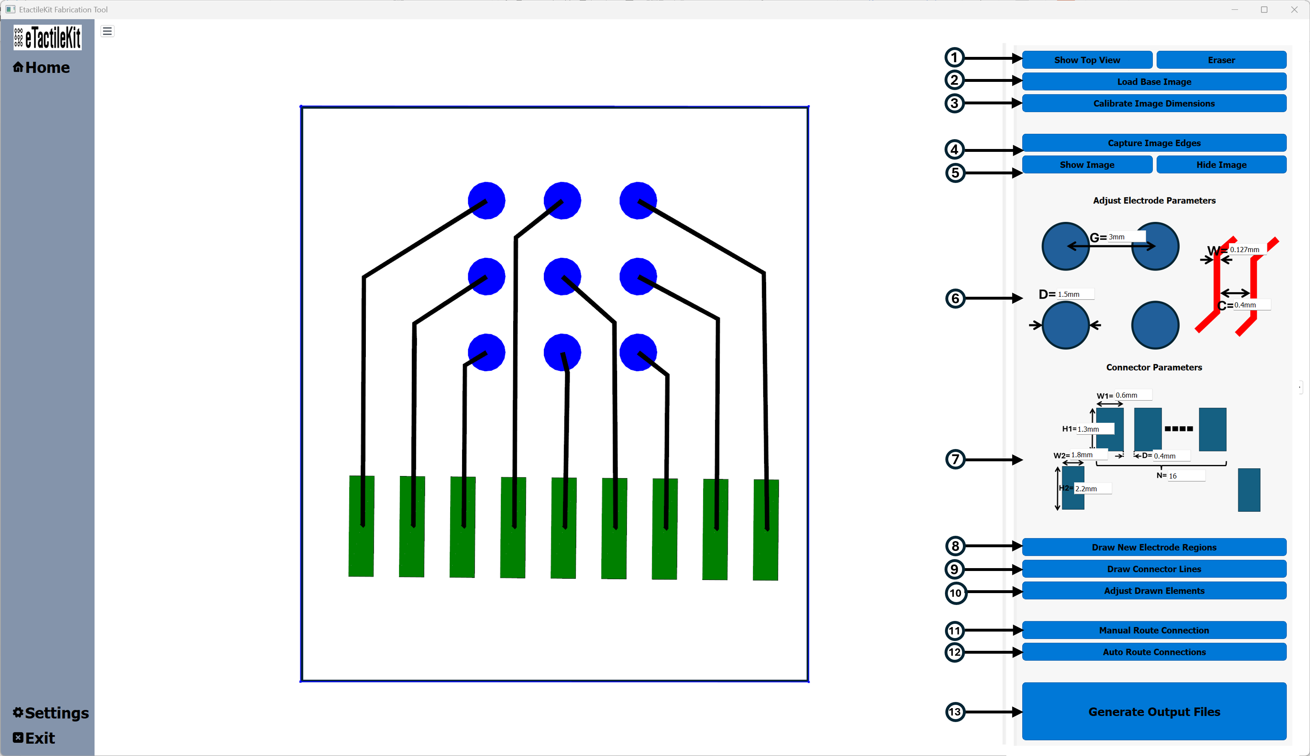
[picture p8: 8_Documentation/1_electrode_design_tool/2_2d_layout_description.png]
Image Description
  
  <p align="center"><i><b>Annotated 2D electrode design layout view</b></i></p>
</p>

1. **Step 1: Importing the desired layout image to the canvas(2)**

    For best results, we recommend the users import the layout images with sharp edges as in the following example scenario. This particular design was done on PowerPoint and exported as an image. You can add the created image to the `image` folder in you project directory.

    <p align="center">
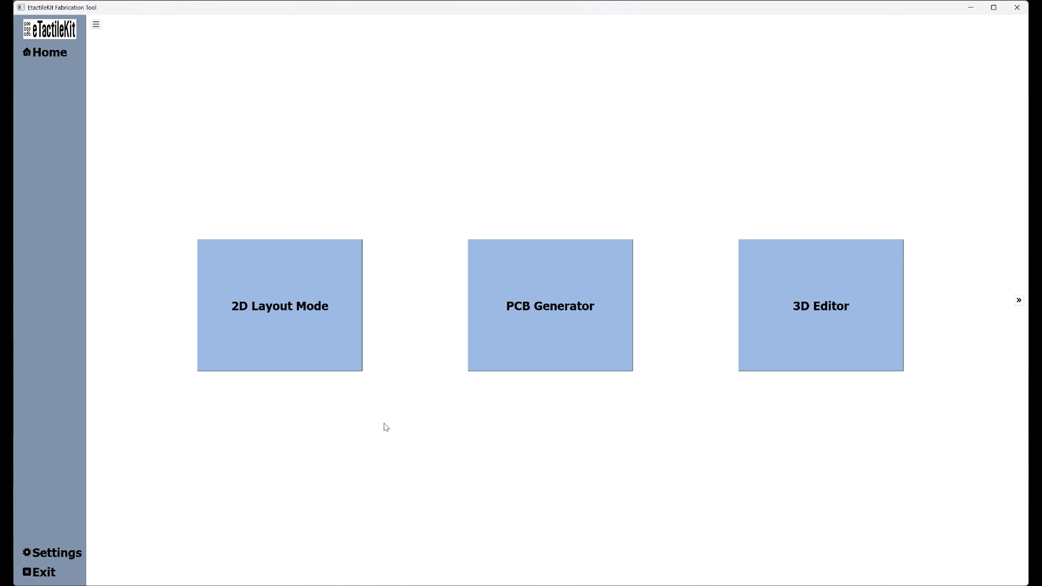
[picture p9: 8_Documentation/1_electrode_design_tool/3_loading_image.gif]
Image Description
      
      <p align="center"><i><b>Importing an image with the target shape to the canvas</b></i></p>
    </p>

2. **Step 2: Calibrating the dimensions to the real world dimensions(3)**

    The image, when imported, is not in its real world dimensions but scaled out uniformly. Here, the user can set **one preferred dimension** to adjust the layout to the real-world dimensions.

    <p align="center">
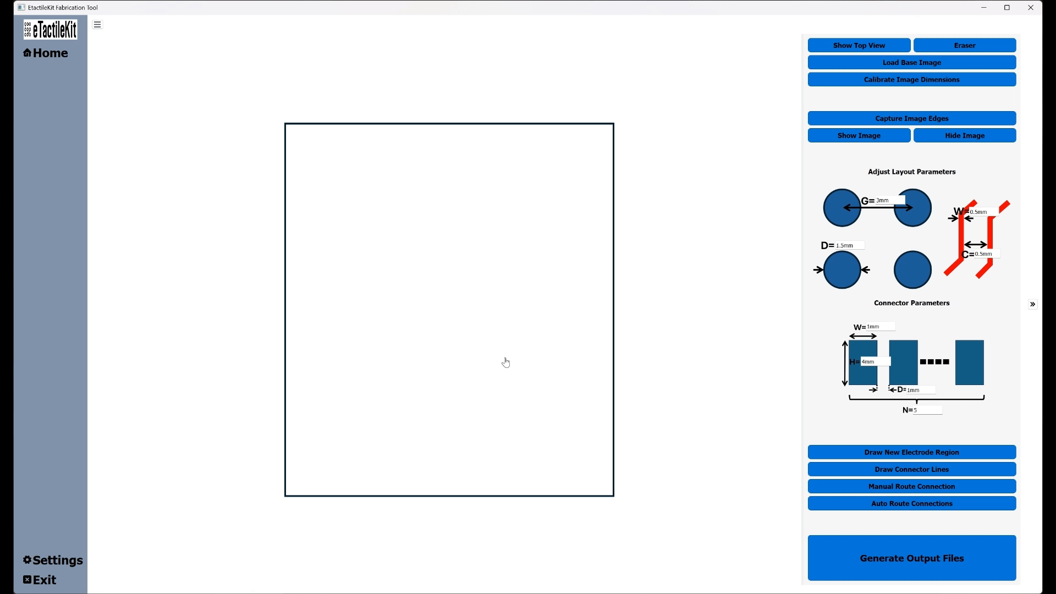
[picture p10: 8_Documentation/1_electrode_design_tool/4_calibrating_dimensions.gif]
      
      <p align="center"><i><b>Calibrating the dimensions of the image</b></i></p>
    </p>

3. **Step 3: Capture the edges of the calibrated image(4, 5)**

    Now you can capture the edges. You can also hide or show the preview of the original image according to your preference.

    <p align="center">
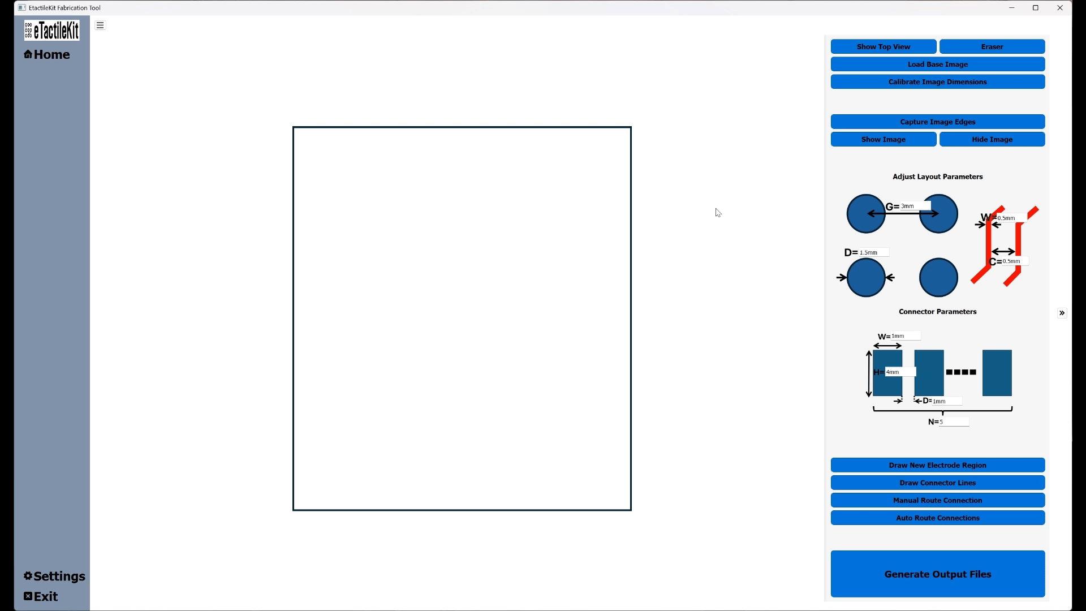
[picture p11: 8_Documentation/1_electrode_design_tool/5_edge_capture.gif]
      
      <p align="center"><i><b>Capturing the edges and hiding/showing the original image preview</b></i></p>
    </p>

4. **Step 4: Adjust the electrode, connector and routing parameters(6, 7)**

    Next, we set the layout and routing parameters before we populate electrodes, place connectors and do the routing. Here you can specify the parameters according to the layout that your final outputs needs to appear. If you are not quite sure at this step, you can adjust these parameters later on as well.

    <p align="center">
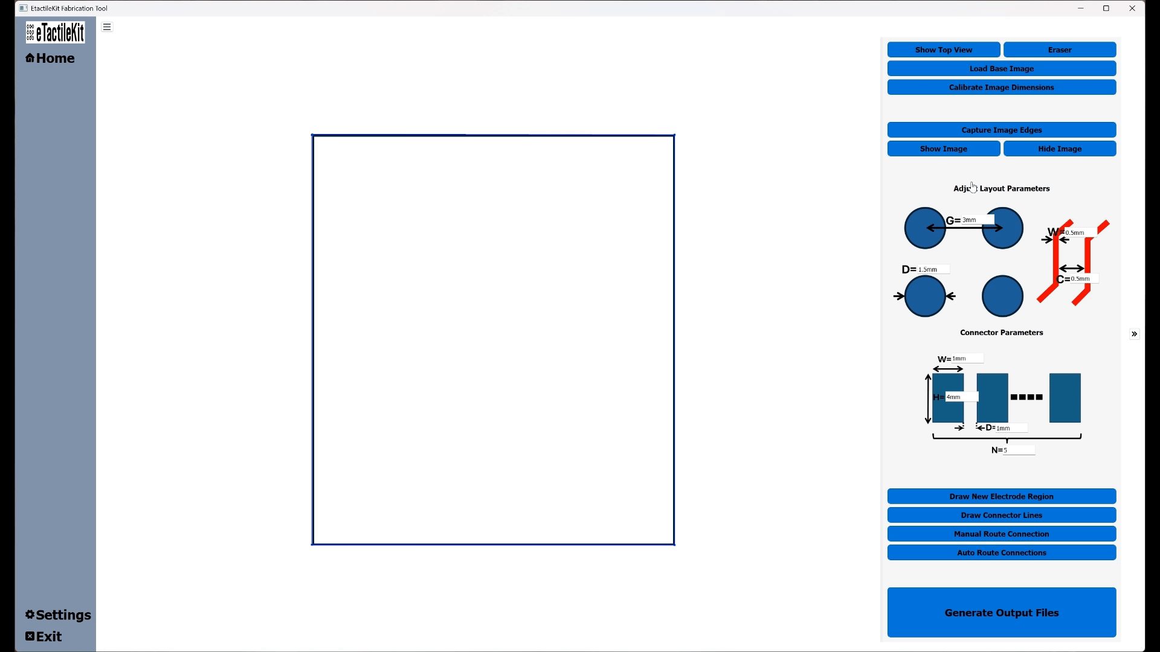
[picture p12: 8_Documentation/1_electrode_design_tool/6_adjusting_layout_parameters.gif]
      
      <p align="center"><i><b>Adjusting electrode, connector and routing parameters</b></i></p>
    </p>

5. **Step 5: Populating electrodes(8, 1)**

    Here we use the tools' free-form region selection to populate electrodes. You can use the eraser to delete any unwanted electrodes, connectors or traces. You can reset the view with the buttons shown on layer 1.
    **Important: make sure to click on the eraser again to turn off the eraser mode**

    <p align="center">
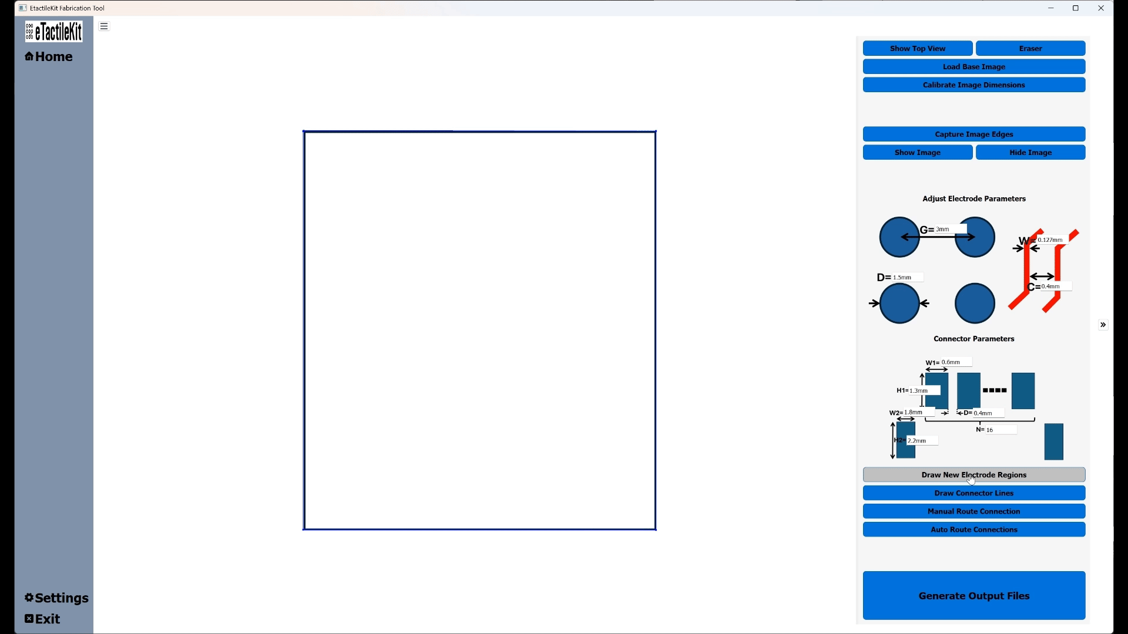
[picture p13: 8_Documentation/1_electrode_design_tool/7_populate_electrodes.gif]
      
      <p align="center"><i><b>Drawing regions to populate electrodes</b></i></p>
    </p>

6. **Step 6: Adding Connectors(9)**

    Here we use lines to place connectors. Connectors will be created based on the location and the orientation of the lines created.
    **Note: You can use the eraser to clear any unwanted connectors.**

    <p align="center">
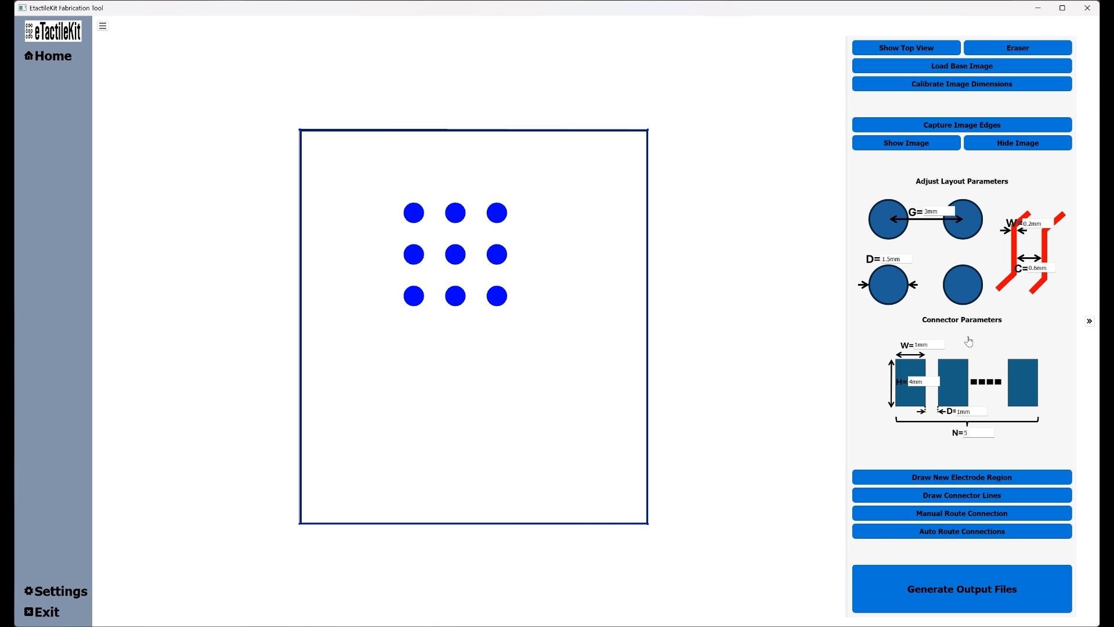
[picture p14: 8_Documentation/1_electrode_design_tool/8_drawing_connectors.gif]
      
      <p align="center"><i><b>Adding connectors</b></i></p>
    </p>

7. **Step 7: Adjusting Electrode Orientations and Positions(10)**
    Here, we adjust the electrodes to our desired locations as needed. You can move and rotate a selected set of electrodes as shown below. You can select the required electrodes by using the `Select Elements to Move` button. You can specify rotation angles, the movement step size and most importantly, you can reset back to the original location if needed.

    <p align="center">
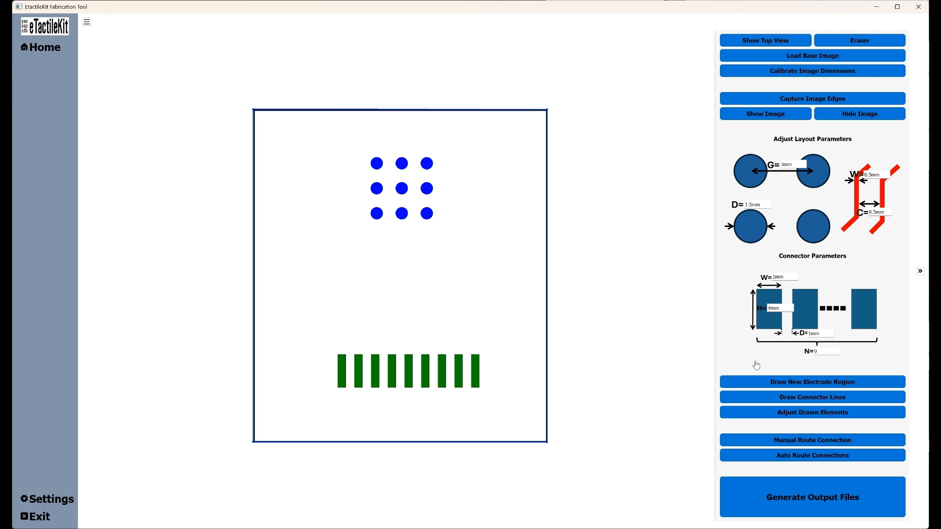
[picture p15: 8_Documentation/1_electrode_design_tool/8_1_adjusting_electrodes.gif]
      
      <p align="center"><i><b>Changing location and orientation of electrodes</b></i></p>
    </p>

8. **Step 7: Routing connections between electrodes and connectors(11,12).**

    In this step, you can route connections between electrodes and connectors. Here, you can use both manual and automatic routing options.
    **Note 1: The automatic routing might not be able to route all the connections. So you might need to route manual connections as well.**
    **Note 2: You can use the eraser to clear unwanted traces.**

    <p align="center">
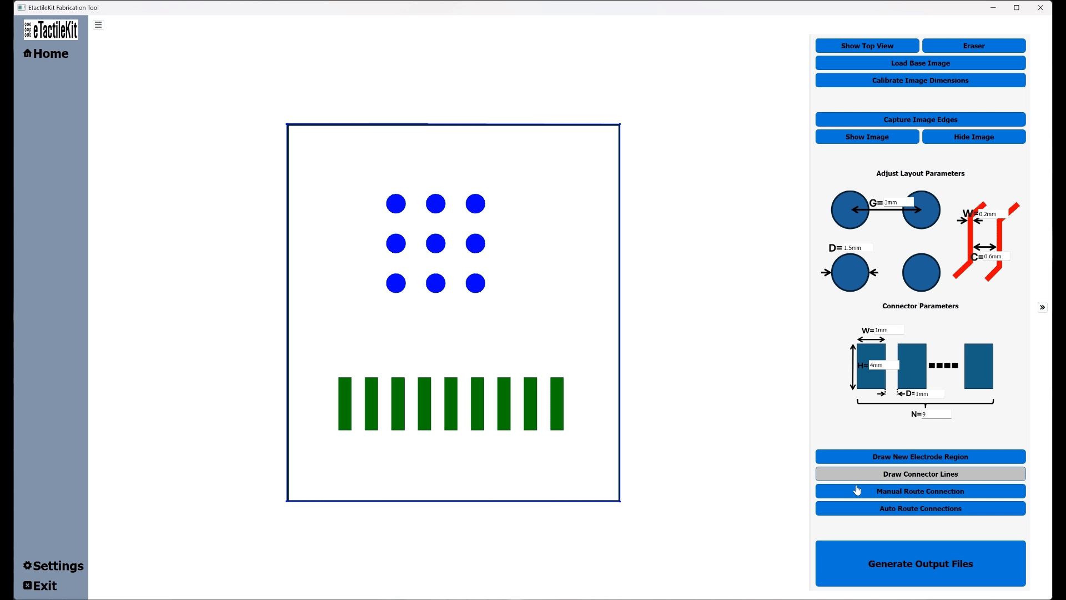
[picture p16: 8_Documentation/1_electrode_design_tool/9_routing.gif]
      
      <p align="center"><i><b>Routing using automatic and manual routing modes</b></i></p>
    </p>

9. **Step 8: Generating output files(13)**

    In the last step, you generate the output files. Here, the tool will generate a PDF layout of the electrodes and connectors, a mask for the electrodes and a JSON file that can be used in the pattern creator tool in further steps of the design tool.

    <p align="center">
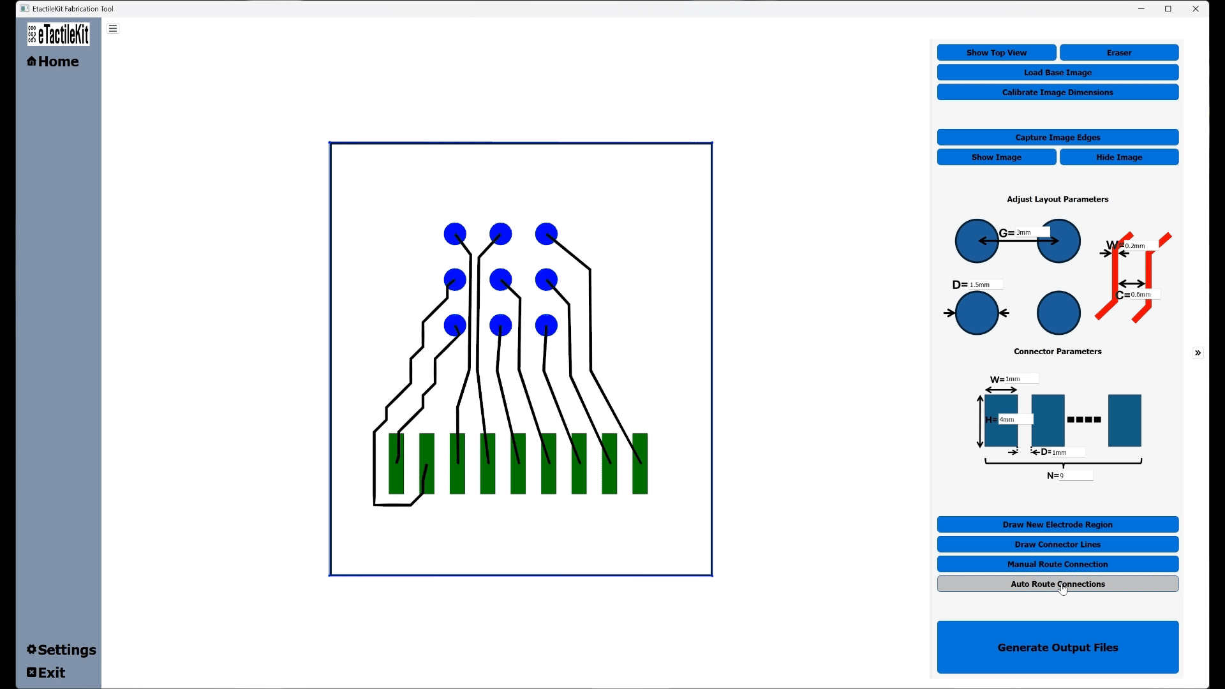
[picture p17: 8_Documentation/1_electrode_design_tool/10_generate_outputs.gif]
      
      <p align="center"><i><b>Generating the output files</b></i></p>
    </p>

    The respective export files will be as shown in the figure below.

    <p align="center">
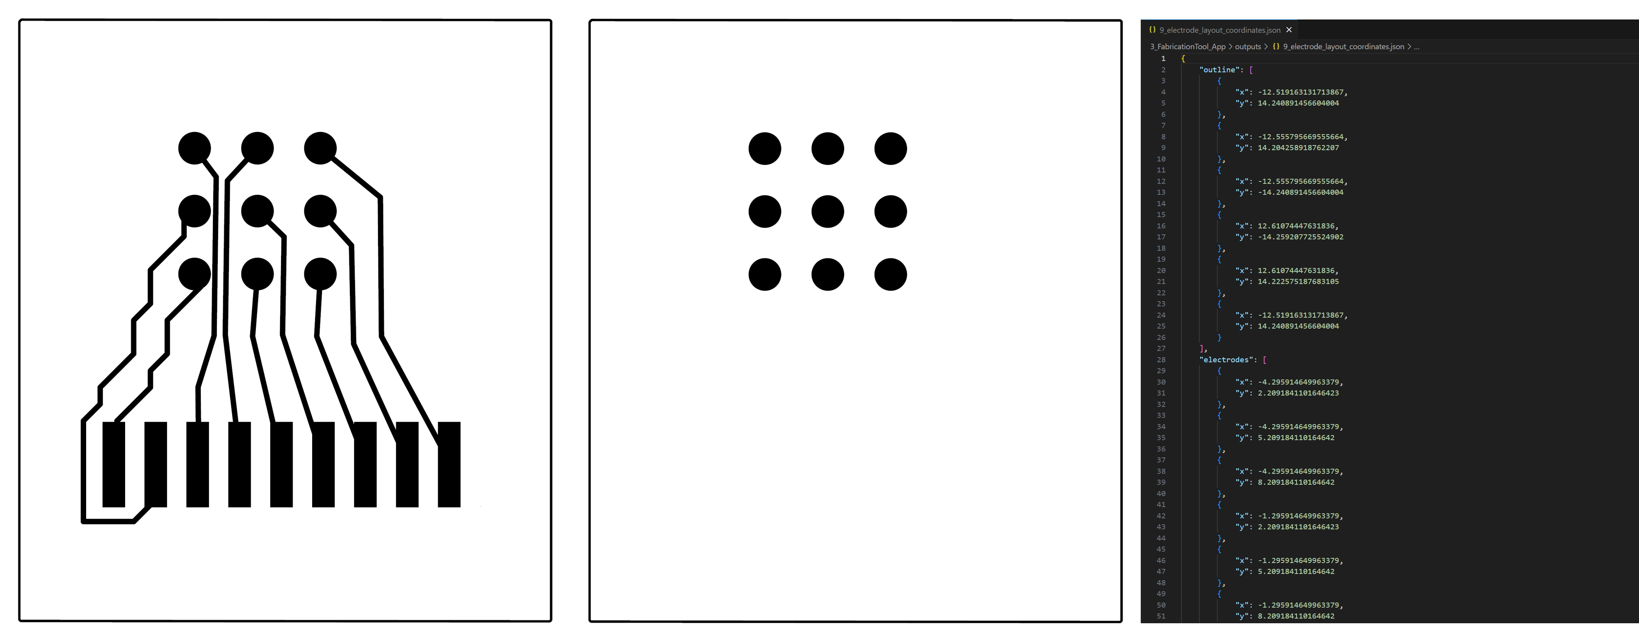
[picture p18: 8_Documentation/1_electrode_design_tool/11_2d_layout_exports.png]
      
      <p align="center"><i><b>The exported PDF layout, mask and a part of the JSON export</b></i></p>
    </p>

10. **Step 9: Adjusting the electrode mapping function**

    In your output files, there will be a JSON file named,
     `[YOUR SAVE FILENAME]_contour_and_electrodes.json`. In that JSON file, there is a section called `"Mapping_func":`.

    <p align="center">
      Image Description
      <p align="center"><i><b>Mapping function</b></i></p>
    </p>

    Here, you can see an array from `0` to `number_of_electrodes - 1` (ex: 0 - 7 if you have 8 electrodes).

    This mapping function says the electrode mapping between the connector and the array. So, here it is `0th` connector to `0th` electrode, `1st` connector to `1st` electrode, likewise.
    **You should change these mappings according to your array settings.**

### 6.2 Creating PCB Electrode Layouts

We use a KiCad plugin that can read the JSON file and automatically layout the PCB in [KiCad](https://www.kicad.org/). The current version of KiCad used is [KiCad 8.0.2](https://downloads.kicad.org/kicad/windows/explore/stable)

You need to set up the Python plugin for KiCad in order to proceed with the further steps. Locate the Python plugin at the below location.

```bash
4_Electrode_Design_Tool\1_KiCad_Plugin\et_plugin.py
```

Next if you are a **Windows** user, you can copy this file to the following directory (**This is path under default installation of KiCAD**).

```bash
C:\Users\user\Documents\KiCad\8.0\scripting\plugins
```

If you are a **MAC** user the default path would be:

```bash
/Applications/kicad/Kicad/Contents/SharedSupport/scripting/plugins
```

**Great!. Now you are all set to use the pcb design tool of eTactileKit.**

The initial phase of the PCB layout generation includes the same steps that were followed in the previous mode in [Section 6.1](#61-creating-2d-electrode-layouts-for-pdf-exports) above. The exported files will have two JSON files one having information for PCB desing and the other for the pattern creator tool with layout coordinates. The default [footprint](https://au.mouser.com/ProductDetail/Hirose-Connector/FH12-16S-1SH55?qs=Ux3WWAnHpjBc3pYMMfcXYg%3D%3D) matches the family and the pitch of the same connector used in eTactileKits hardware.

**Important: make sure you choose the number of connector pads according to your footprint**
Now let's go through the steps to generate PCB Files using KiCAD.

1. **Step 1: Importing the generated JSON file via the KiCAD plugin**

    Now let's import the JSON file generated from the tool via the plugin to layout the PCB.
    <p align="center">
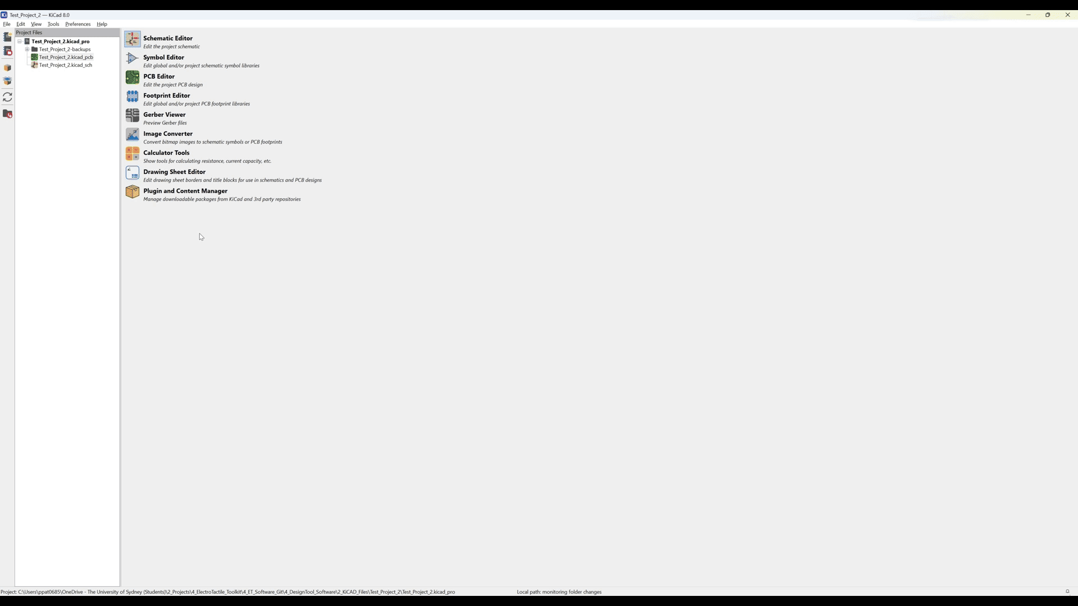
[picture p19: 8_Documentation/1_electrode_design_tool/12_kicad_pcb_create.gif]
      
      <p align="center"><i><b>Importing JSON file via kiCAD plugin to generate PCB</b></i></p>
    </p>

2. **Step 2: Exporting manufacture-ready fabrication outputs to order PCBs**

    In this step, we export fabrication files that are ready to be sent for manufacturing PCBs. You can [refer to the tutorial video](https://www.youtube.com/watch?v=pGRm7nT1zaw) that guides you through the export procedure and ordering from [JLC PCB.](https://jlcpcb.com/)

### 6.3 Creating Electrodes on 3D Surfaces

The 3D electrode design tool is capable of importing a given mesh object (STL or OBJ) and then populating connectors and electrodes and do automatic routing. The mesh and the routing objects can be seperately exported as OBJ files that can be 3D printed. Conductive materials can be used to print the routes.
<p align="center">
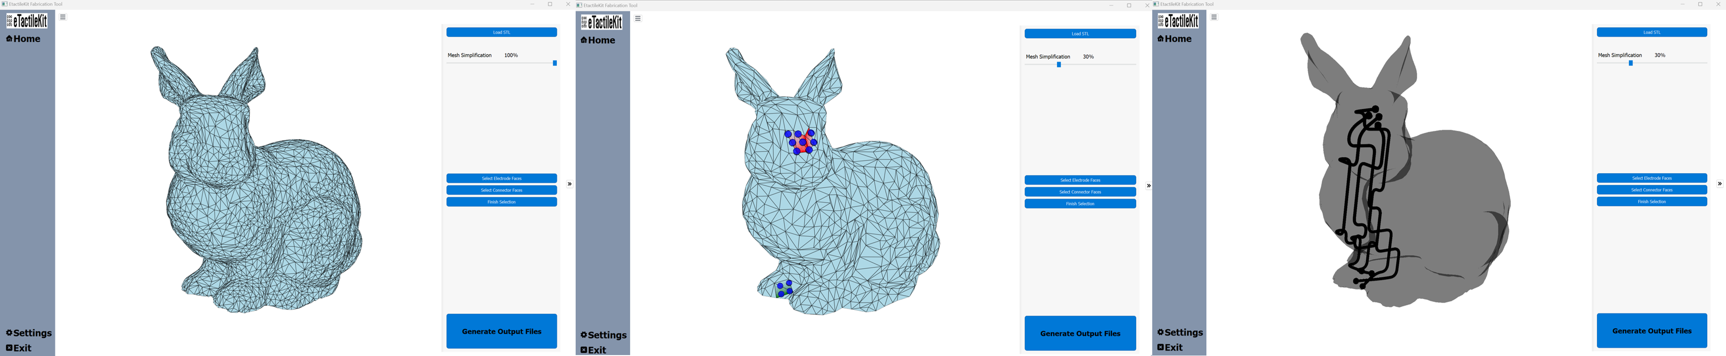
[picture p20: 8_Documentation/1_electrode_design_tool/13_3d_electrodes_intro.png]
  
  <p align="center"><i><b>Overview of a bunny populated with electrodes and the routed view from the tool</b></i></p>
</p>

You can follow the steps below to create your own custom 3D electrodes.

1. **Step 1: Importing a mesh file to the canvas**

    You can import a mesh file in STL or OBJ format to the canvas to start proceeding.
    **Note: You can use the mouse wheel to zoom in and zoom out, the left button to rotate, and press the mouse wheel to pan the canvas**
    <p align="center">
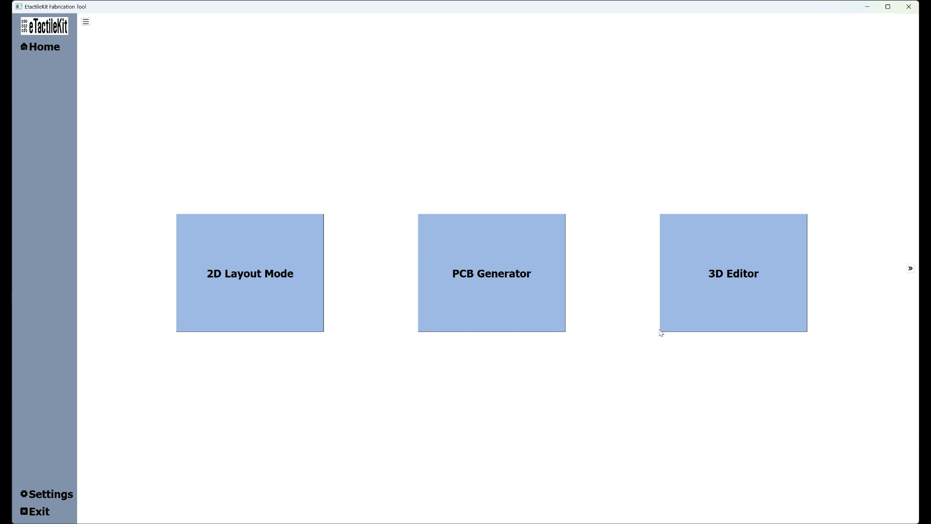
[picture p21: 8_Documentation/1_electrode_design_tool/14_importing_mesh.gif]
      
      <p align="center"><i><b>Importing a STL mesh into the tool canvas</b></i></p>
    </p>

2. **Step 2: Reducing the mesh to ease further operations**

    Here we will scale down the mesh to make it easier for us in the further steps. This will save time and reduce complexity in mesh operations.
    <p align="center">
      Image Description
      <p align="center"><i><b>Reducing the mesh and adjusting the view</b></i></p>
    </p>

3. **Step 3: Populating electrodes and connectors**

    Now we can set the electrode, connectors and routing parameters before we place and start routing electrodes and connectors. Then we can select the faces to populate electrodes and connectors seperately.
    **Important: Use SHIFT+LEFT mouse button to select individual faces**

    <p align="center">
      Image Description
      <p align="center"><i><b>Adjusting parameters and populating electrodes and connectors</b></i></p>
    </p>

4. **Step 4: Generate routing traces connecting the connectors and electrodes**

    Next we can generate the routing traces to create connections between electrodes and connectors

    <p align="center">
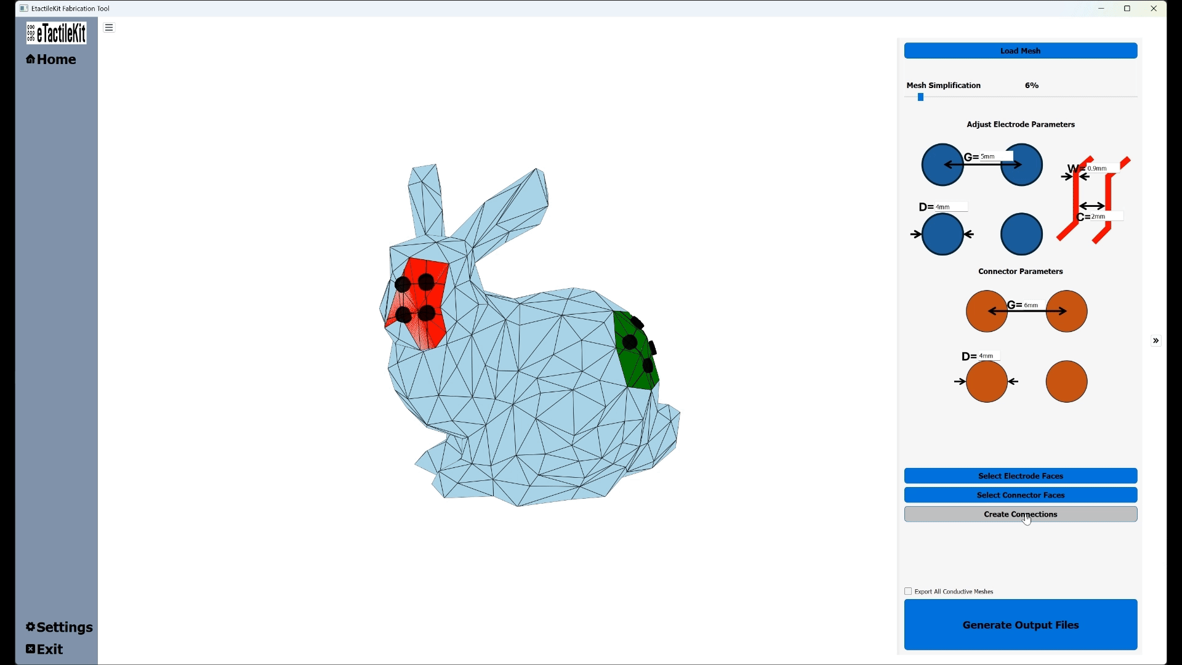
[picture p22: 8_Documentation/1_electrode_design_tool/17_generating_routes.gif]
      
      <p align="center"><i><b>Automatically generating routing paths</b></i></p>
    </p>

5. **Step 5: Generating output files**

    Finally, we generate the output mesh files that include the routing traces and the mesh object. The output file format is OBJ ,and it is to maintain compatibility with other components of the toolkit.

    <p align="center">
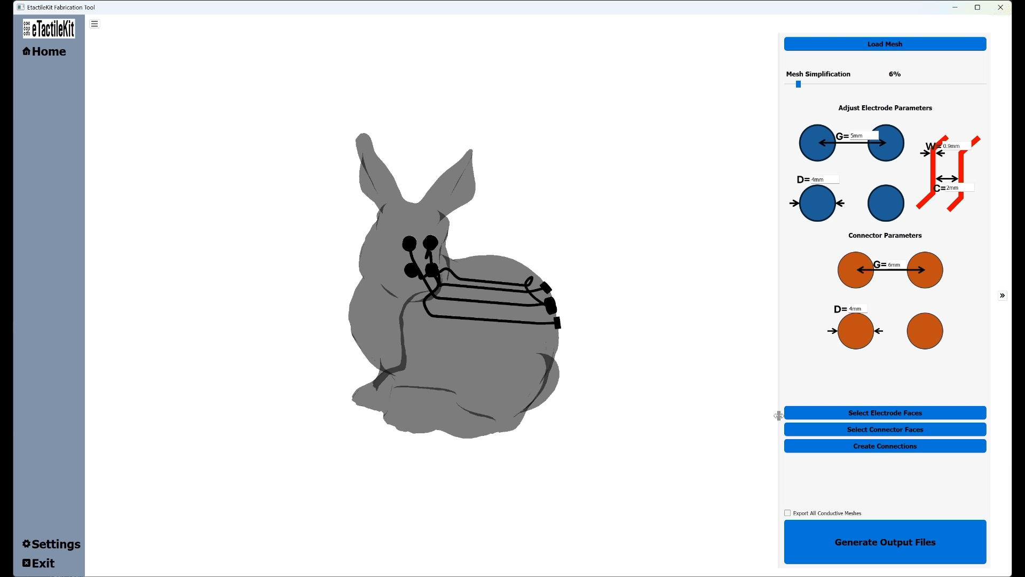
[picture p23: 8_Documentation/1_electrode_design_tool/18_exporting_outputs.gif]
      
      <p align="center"><i><b>Exporting files</b></i></p>
    </p>

6. **Step 6: Adjusting the electrode mapping function**

    In your output files, there will be a JSON file named,
     `[YOUR SAVE FILENAME]_contour_and_electrodes.json`. In that JSON file, there is a section called `"Mapping_func":`

    <p align="center">
      Image Description
      <p align="center"><i><b>Mapping function</b></i></p>
    </p>

    Here, you can see an array from `0` to `number_of_electrodes - 1` (ex: 0 - 7 if you have 8 electrodes).
    This mapping function says the electrode mapping between connctor to the array. So, here it is `0th` connector to `0th` electrode, `1st` connector to `1st` electrode like wise.
    **You should change these mappings according to your array settings.**

**Happy 3D printing!**

You can use preferred methods for managing the connections to the connectors. One of the methods is using a soldering iron to melt the exposed connector region to bind wires as shown below.
<p align="center">
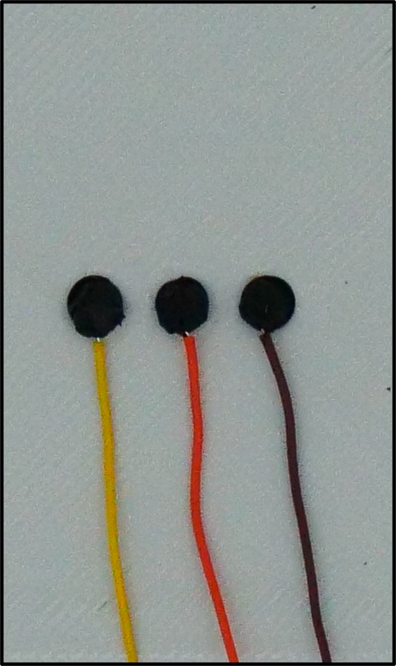
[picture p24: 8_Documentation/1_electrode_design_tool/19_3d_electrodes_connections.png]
  
  <p align="center"><i><b>Wires fused to connectors by melting using a soldering iron</b></i></p>
</p>

---

## 7. Tactile Pattern Creator

### Prerequisites  

Before proceeding, ensure you have **Processing 4** installed on your system. You can download it from the official website: [Processing Download](https://processing.org/download)

Once Processing is installed, you need to add the required libraries. Follow these steps for installation:  

1. Open Processing.  
2. Navigate to **Sketch** → **Import Library...** → **Manage Libraries...**  
3. In the **Libraries** tab (default), search for **PeasyCam** and then install it.
4. In the **Libraries** tab (default), search for **ControlP5** and then install it.
5. If you are a **MAC** User go to **Tools** → **Install Processign-java**.

For a step-by-step guide, refer to the following video:  

<p align="center">
  Image Description
  <p align="center"><i><b>Install the PeasyCam library</b></i></p>
</p>

### 7.1 Setup the pattern creator

The **Tactile Pattern Creator** is a scripting-based tool designed to generate tactile patterns for 2D or 3D electrode arrays. It offers both built-in patterns and the flexibility to create custom patterns, enabling users to tailor designs to their specific requirements. 

#### Step 1: Navigate to the `4_Pattern_Creator` folder

In this folder there are two folders as `Processing_program` and `Library`. 

- `Processing_program\`: This folder contains all the source code of the processing program. If you need to do any improvement, you can use this program.
- `Library\`: This folder contains the `eTactile` processing library which you need to install to your processing and play!

#### Step 2: Install the `eTactile` library

Install this library to your processing is not hard at all. What you have to do is,

1. Download the `eTactile` folder (the folder inside the `4_Pattern_Creator`).
2. Locate the Processing's libraries folder in your PC.

   - **Windows:** `Documents\Processing\libraries\`
   - **Mac:** `Documents/Processing/libraries/`

3. Place the `eTactile` folder inside the `libraries` folder.
4. Restart processing.

#### Features in `eTactile` library

- **Built-in Patterns**: Access a library of pre-defined patterns for quick implementation.
- **Custom Pattern Design**: Create unique patterns using a scripting interface for full control over electrode activation.
- **2D and 3D Support**: Compatible with both 2D and 3D electrode arrays.
- **Scripting Flexibility**: No GUI constraints, users can write scripts to automate and customize pattern generation.

Now you are **ready to go !!!**

### 7.2 Creating 2D Electrode patterns using library

#### Step 1: 2D pattern template

We have given a template for 2D pattern creation in our llibrary. To access that template,

  1. Open a processing sketch.
  2. Navigate File → Examples...  ; this will pop-up the **Java Examples** window.
  3. In **Java Examples** window, expand the **Contributed Libraries** folder.
  4. In that folder you can see our **eTactile** library.
  5. Expand the **eTactile** library. It will show another two folders as **2D** and **3D**.
  6. Now, expand the **2D** folder. In that folder you will see a file as **template2D**.
  7. Double click on that. It will open the 2D pattern template.

You can copy this template to your processing sketch or run it directly.

<p align="center">
  Image Description
  <p align="center"><i><b>Locate and open the 2D pattern template</b></i></p>
</p>

#### Step 2: Visualize the 2D Electrode Board

**Note:** If you run the **`template2D`** sketch that is directly from the examples, you will see the electrode array that is in the Main board of our toolkit (See the following video).
We have save these necessery JSON files in the `Data` folder that is inside each example.

<p align="center">
  Image Description
  <p align="center"><i><b>Directly run the template2D example </b></i></p>
</p>

**Note:** If you run the this template directly just copy and paste, it will show the electrode board that you have given as `electrode_board_file` (See the following video).
For this video, I use `electrodes_64.json` file. Since I have place it inside the sketch folder, I directly put the file name. But if you want, you can give **any specific location** as the file name.

<p align="center">
  Image Description
  <p align="center"><i><b>Copy the template and run it in my own sketch with different electrode board </b></i></p>
</p>

**Note:** 
  
- You can give any location to your **`output_file`**. If you just give  a name (ex: `output.json`) the output file will save on your sketch folder itself. 

- In built-in examples, the output file will save inside `Data/created_patterns` folder.
The library `examples` folder located in `"Documents\Processing\libraries\eTactile\examples"`

#### Step 3: Create a 2D Pattern using pattern library

Our 2D pattern library consists of a number of examples that you can load and try out. In our examples, we initially load the main board electrode array, but you can replace it with your own electrode array by providing the path to it, and save the output to any convenient location.

You can easily understand and edit the pattern parameters to adjust the pattern to your preference. 

<p align="center">
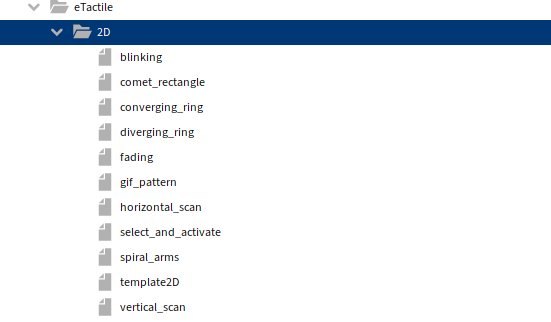
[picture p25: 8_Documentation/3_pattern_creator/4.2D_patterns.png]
  
  <p align="center"><i><b>2D pattern examples </b></i></p>
</p>

**Note:** We highly encourage you to copy the pattern sketch from the example into your own sketch before making any changes. Otherwise, the original examples may be altered.

<p align="center">
  Image Description
  <p align="center"><i><b>Use of diverging ring pattern example </b></i></p>
</p>

### 7.3 Creating Customized 2D Electrode Patterns

As previously mentioned, our library provides users with the flexibility to design unique electrode activation patterns using a dedicated scripting interface. This allows for precise control over electrode stimulation, enabling customized tactile experiences.

To assist users in this process, we provide a standard template as a reference. If you wish to create a custom pattern, simply follow these guidelines:

#### Step 1: Copy the `template2D` from the examples

For the ease of user, we have already provided a template for pattern creation. So, you can easily copy it from our library examples as follows.

<p align="center">
  Image Description
  <p align="center"><i><b>Copy the template2D from the examples.</b></i></p>
</p>

And also, have a basic sketch on the pattern that you are going to create here. It will help you when you scripting.
For an example, here we have a face of a bunny and there are electrodes in the bunny's ears. We are going to activate those electrodes in the ears as diverging rings as you can see in following figure.

<p align="center">
  Image Description
  <p align="center"><i><b>Custom pattern we are going to create.</b></i></p>
</p>

#### Step 2: Load the electrode board and define the output

In this example, I created 2 subfolders inside my sketch folder as `JSON_Files` and `Created_patterns`. My electrode board JSON file is in `JSON_Files` folder and I'm going to save my output in `Created_patterns` folder.

<p align="center">
  Image Description
  <p align="center"><i><b>File structure (not necessery)</b></i></p>
</p>

Therefoe I define the `electrode_board_file` and `output_file` as;

```java
String electrode_board_file = "JSON_Files/bunny_face.json";
String output_file          = "Created_patterns/new_pattern";
```

After giving the `electrode_board_file` path, just run the sketch and get an idea about the electrode distribution. 
Here, the two diverging rings should start from the middle electrode of each ear. So, I need those two coordinates.

<p align="center">
  Image Description
  <p align="center"><i><b>Display the electrode board</b></i></p>
</p>

<p align="center">
  Image Description
  <p align="center"><i><b>Display the electrode board</b></i></p>
</p>

So, I can see here, the position of the center electrodes are:
`electrode 2: (382.6, 129.7)`
`electrode 8: (627.3, 122.2)`

#### Step 3: Define 2D pattern variables

In your sketch, after giving file names and location, you can define your function variables. To this pattern, I need two rings, that means two centers. And also, I initiate the radius to zero. 
The stroke of the ring is very important since it is the object that is overlap with electrodes. So, I initiate the stroke width as 8. And the delay between two frames as 100ms.

```java
// Definr your pattern variables here
float centerX1 = 382.6;
float centerY1 = 129.7;

float centerX2 = 627.3;
float centerY2 = 122.2;

int radius = 0;
int stroke_width = 8;
int frame_delay = 100;
```

**Note:** In **`void setup()`** you have nothing to do!

#### Step 4: Define the 2D pattern

Now you can define your pattern under **`void draw()`**.
We have given full flexibility to the user to define any kind of graphic here (by using general processing commands). 
But when you are going to define the pattern properties (like stimulation frequency, stimulation mode) you should use `eTactile` functions.

So I'm defining my pattern as follows.

**Note:** Don't set a background colour. `eTactile` library automatically set it to black for you.

```java
void draw() {
  stroke(0, 255, 0);
  strokeWeight(stroke_width);
  noFill();
  
  ellipse(centerX1, centerY1, radius * 2, radius * 2);
  ellipse(centerX2, centerY2, radius * 2, radius * 2);
  radius += 2;
  
  eTactile.eTfreq(75);
  eTactile.eTmode("Anodic");
  
  eTactile.eTframedelay(frame_delay);
  
  if (radius >= 50){
    radius = 0;
    eTactile.terminate();
  }
}
```

**Explanation:** Here I have drawn two rings and set the radius to increase by 2 in each iteration.

- **`eTactile.eTfreq(75):`** Set the stimulation frequency to 75Hz.
- **`eTactile.eTmode("Anodic"):`** Set stimulation mode to Anodic.
- **`eTactile.eTframedelay(frame_delay):`** Set the time delay between two frames.
- **`eTactile.terminate():`** This will save the pattern to the JSON file.

**Note:** If you don't set the frequency and the stimulation mode, it will automatically set to the default values as frequency = 75Hz and stimulation mode as "Anodic".

At the end, I have setted the `radius = 0` for loop the pattern. You can dynamically change the stimulation frequency and the stimulation mode as well.

<p align="center">
  Image Description
  <p align="center"><i><b>The created custom pattern</b></i></p>
</p>

### 7.4 Creating 3D Electrode Patterns Using Library

#### Step 1: 3D pattern template

We have given a template for 3D pattern creation in our llibrary. To access that template,

  1. Open a processing sketch.
  2. Navigate File → Examples...  ; this will pop-up the **Java Examples** window.
  3. In **Java Examples** window, expand the **Contributed Libraries** folder.
  4. In that folder you can see our **eTactile** library.
  5. Expand the **eTactile** library. It will show another two folders as **2D** and **3D**.
  6. Now, expand the **3D** folder. In that folder you will see a file as **template3D**.
  7. Double click on that. It will open the 3D pattern template.

You can copy this template to your processing sketch or run it directly.

<p align="center">
  Image Description
  <p align="center"><i><b>Locate and open the 3D pattern template</b></i></p>
</p>

#### Step 2: Visualize the 3D Electrode Board

**Note:** If you run the **`template3D`** sketch that is directly from the examples, you will see the electrode array that is in the Main board of our toolkit (See the following video).
We have save these necessery JSON files in the `Data` folder that is inside each example.

<p align="center">
  Image Description
  <p align="center"><i><b>Directly run the template3D example </b></i></p>
</p>

**Note:** If you run the this template directly just copy and paste, it will show the electrodes that you have given as `electrode_locs` and the 3D objec that you have given as `object3D`. (See the following video).
For this video, I use `bunny_nose.json` file and `StanfordBunny.obj`. Since I have place it inside the sketch folder, I directly put the file name. But if you want, you can give **any specific location** as the file name.

**Note:** Your 3D object **must be** in `.obj` format.

<p align="center">
  Image Description
  <p align="center"><i><b>Copy the template and run it in my own sketch </b></i></p>
</p>

**Note:** 
  
- You can give any location to your **`output_file`**. If you just give  a name (ex: `output.json`) the output file will save on your sketch folder itself. 

- In built-in examples, the output file will save inside `Data/created_patterns` folder.
The library `examples` folder located in `"Documents\Processing\libraries\eTactile\examples"`

#### Step 3: Create a 3D Pattern using pattern library

Our 3D pattern library consists of a number of examples that you can load and try out. In our examples, we initially load the stanford bunny and the nose electrodes, but you can replace it with your own 3D object and electrodes by providing the path to it, and save the output to any convenient location.

You can easily understand and edit the pattern parameters to adjust the pattern to your preference. 

<p align="center">
  Image Description
  <p align="center"><i><b>3D pattern examples </b></i></p>
</p>

**Note:** We highly encourage you to copy the pattern sketch from the example into your own sketch before making any changes. Otherwise, the original examples may be altered.

<p align="center">
  Image Description
  <p align="center"><i><b>Use of moving plane pattern example </b></i></p>
</p>

### 7.5 Creating Customized 3D Electrode Patterns

As previously mentioned, our library provides users with the flexibility to design unique electrode activation patterns using a dedicated scripting interface. This allows for precise control over electrode stimulation, enabling customised tactile experiences.

To assist users in this process, we provide a standard template as a reference. If you wish to create a custom pattern, simply follow these guidelines:

#### Step 1: Copy the `template3D` from the examples

For the ease of the user, we have already provided a template for pattern creation. So, you can easily copy it from our library examples as follows.

<p align="center">
  Image Description
  <p align="center"><i><b>Copy the template3D from the examples.</b></i></p>
</p>

#### Step 2: Load the 3D object, electrodes and define the output

In this example, I created 3 subfolders inside my sketch folder as `JSON_Files`, `3D_Objects` and `Created_patterns`. My electrode location JSON file is in `JSON_Files` folder, 3D object is in `3D_Objects` folder and I'm going to save my output in `Created_patterns` folder.

<p align="center">
  Image Description
  <p align="center"><i><b>File structure (not necessery)</b></i></p>
</p>

Therefoe I define the `electrode_locs`, `object3D` and `output_file` as;

```java
String electrodes_locs   = "JSON_Files/bunny_nose.json";
String object3D          = "3D_Objects/StanfordBunny.obj";

String output_name       = "Created_patterns/new_3D_pattern"; 
```

After giving the `electrode_locs` file and `object3D` paths, just run the sketch and get an idea about the electrode distribution. 

Here, we can't annotate electrode numbers as 0,1,2,3... in 3D space. Therefore, you should have a rough idea about the electrode distribution from the electrode design tool.

For convenience, let's see how we can create the moving plane (moving along the z-axis) in here.

#### Step 3: Define 3D pattern variables

In your sketch, after giving file names and location, you can define your function variables. 

First, let's define the starting point. Since this is 3D, it has three points as `startX`, `startY`, `startZ`. Since this is a plane, it has a `height`, `width` and `length`. 
When it moving, I'm going to move it from 1 unit for each frame (`increment = 1`). I take delay between two frames as 200ms (`delay_time = 200ms`).

```java
// Definr your pattern variables here
float startX = -72;    // X-coordinate of the plane's starting position
float startY = -60;    // Y-coordinate of the plane's starting position
float startZ = 20;     // Z-coordinate of the plane's starting position

int plane_width = 100;      // Width of the plane
int plane_length = 100;     // Length of the plane
int plane_height = 1;       // Thickness of the plane

int increment = 1;
int delay_time = 200;

float currentZ = startZ;
```

Here, I used a variable called `currentZ` to keep track of where we are now in the 3D space, since this is a plane that is moving along the z-axis.

**Note:** In **`void setup()`** you have nothing to do!

#### Step 4: Define the 3D pattern

Now you can define your pattern under **`void draw()`**.

Since this is a plane, I use `box()` function with very low height to generate the plane.

**Note:** Don't set a background colour. `eTactile` library automatically set it to black for you.

```java
void draw() {
  fill(0, 255, 0, 100); // Use semi-transparent green for the plane

  // Draw the moving plane
  pushMatrix();
  translate(startX + plane_width / 2, startY + plane_length / 2, currentZ + plane_height / 2);
  box(plane_width, plane_length, plane_height); // Draw the plane as a thin box
  popMatrix();
  
  eTactile.eTframedelay(delay_time);

  eTactile.eTfreq(75);
  eTactile.eTmode("Anodic");
  
  currentZ += increment;
  
  if (currentZ >= 55){
    eTactile.terminate();
    currentZ = startZ;
  } 
}
```

**Explanation:** Here I have drawn a plane and set the z coordinate of the frame to increase by 1 unit per frame. When it reaches to `z=55` a one pattern cycle is done and save it to the JSON file.

- **`eTactile.eTfreq(75):`** Set the stimulation frequency to 75Hz.
- **`eTactile.eTmode("Anodic"):`** Set stimulation mode to Anodic.
- **`eTactile.eTframedelay(frame_delay):`** Set the time delay between two frames.
- **`eTactile.terminate():`** This will save the pattern to the JSON file.

**Note:** If you don't set the frequency and the stimulation mode, it will automatically set to the default values as frequency = 75Hz and stimulation mode as "Anodic".

At the end, I have reset the `currentZ` for the loop of the pattern. You can dynamically change the stimulation frequency and the stimulation mode as well.

#### Step 5: Define the inclusion criteria

Unlike the 2D case, when it comes to a 3D canvas, we can't just read the pixel colour and say this electrode should be activated since the canvas pixels are 2D. Therefore, if you're trying to create a 3D pattern, you should define an inclusion criterion inside the following `boolean isInsideShape()` function.

```java
boolean isInsideShape(float x, float y, float z)
```

- Takes in the 3D coordinates `(x, y, z)` (the electrode coordinate) as the input
- Return `true` if the point is inside the volume of the 3D object.

Here, when it comes to moving a plane

```java
boolean isInsideShape(float x, float y, float z) {
  
  boolean withinX = x >= startX && x <= (startX + plane_width);
  boolean withinY = y >= startY && y <= (startY + plane_length);
  boolean withinZ = z >= currentZ && z <= (currentZ + plane_height);

  return withinX && withinY && withinZ;
}
```

Each of these checks whether the given point lies within the bounds of the moving plane along each axis:
**`withinX:`** Is the **`x`** coordinate inside the width of the plane?
**`withinY:`** Is the **`y`** coordinate inside the length of the plane?
**`withinZ:`** Is the **`z`** coordinate inside the current height/thickness of the plane?

Returns `true` **only if the point lies within all 3 boundaries** — i.e., the point is inside the 3D rectangular slice (the plane) at that frame.

<p align="center">
  Image Description
  <p align="center"><i><b>The created custom pattern</b></i></p>
</p>

---

## 8. Real-Time Hardware Access GUI

The eTactileKit provides a real-time hardware access GUI designed to enhance user experience and functionality. You can locate the Scripts to run the GUI below;

```bash
5_Interaction_Tool\eTactileKit_GUI
```

Built on the Processing platform, this GUI offers the following key features:

1. **Real-Time Visual Feedback**
  Monitor and visualize hardware activity in real time for better control and understanding.

2. **Calibration for Safety & Comfort**
  A dedicated calibration setup ensures optimal performance, prioritizing user safety and comfort before usage.

3. **Click & Sense Feature**
  Test and experiment with your electrode board effortlessly. Simply click on an electrode in the GUI to sense the electrotactile response.

  Each of these features is explained in detail below.

### Prerequisites for GUI

 The GUI needs the same set of libraries to be installed that were mentioned in [Section 7](#7-tactile-pattern-creator). If you haven't installed them already follow the guidelines to install the libraries before proceeding.

### Setting up the GUI

The Processing GUI project is located in `5_Interaction_Tool\eTactileKit_GUI\` folder.
Locate this folder and open the `eTactileKit_GUI.pde` file in processing and **run** it.

The interface should appear as shown in the following figure.
<p align="center">
  Image Description
  <p align="center"><i><b>eTactileKit GUI </b></i></p>
</p>

Here, you have 2 options as,

1. **2D MODE**
2. **3D MODE**

Select `2D MODE` if your electrodes are 2D (or if you created the pattern using `2D pattern creator`)
Select `2D MODE` if your electrodes are 3D (or if you created the pattern using `3D pattern creator`)

**IMPORTANT!** For `MAC` users if none of the 2D or 3D modes are opened, first make sure you installed processing java as instrcuted in [section 7](#7-tactile-pattern-creator) above. If the error still persists, you can find the path to the `processing-java` by running the following command.

```bash
which processing-java
```

by default this should return `/usr/local/bin`. If this is not the case **copy the path** and do the following change in the `launchSketch` function in your current script(`eTactileKit_GUI.pde`).

<p align="center">
  Image Description
  <p align="center"><i><b>Locating and adding the processign-java path</b></i></p>
</p>

### **8.1 2D MODE (for 2D patterns)**

After you click on the `2D MODE` button, the GUI for 2D pattern will appear. (**Note:** it will may take about 3 seconds)

<p align="center">
  Image Description
  <p align="center"><i><b>Open the 2D execution program</b></i></p>
</p>

**Explanation of elements in the GUI**

<p align="center">
  Image Description
  <p align="center"><i><b>2D execution program interface</b></i></p>
</p>

1. **SELECT COM PORT**
  Here, all avilable COM ports will appear and you have to select the COM port that is belongs to your **eTactileKit** hardware setup.

2. **REFRESH**
  By click on this button, you can update the list of connected COM PORTs.

3. **IMPORT ARRAY JSON**
  Here, you have to include the JSON file that incldes the information about your electrode array.

4. **CALIBRATION**
  By clicking on this button, you will directed to the **eTactile Calibration Setup**.

5. **INITIALIZE**
  By clicking on this button, you will directed to the execution program that gives real time visual feedback.

6. **CLICK & SENSE**
  By clicking on this button, you will directed to the **click and sense** program.

### Execute a 2D pattern using GUI

#### Step 1: Select COM Port and appropriate JSON files

1. Select the `COM port` that belongs to your hardware.
2. Select the JSON file that belongs to your electrode array. (**Make sure to navigate to the array directory**)

**Note:** If you are using the onboard electrodes for any of your work, please use the JSON file `electrode_array_main_board.json` provided by us for the onboard electrodes. Do not use this JSON file for other customized 8-electrode boards.

<p align="center">
  Image Description
  <p align="center"><i><b>2D execution program file selection</b></i></p>
</p>

After selecting above `COM port` and necessary JSON files, you can directly go to the `INITIALIZE` and execute the pattern.
But, you **don't have** a control of stimulation intensity level. **Therefore, we advice you to Calibrate before Initialize**.

**Step 2: Calibration**
After import necessery JSON files, click on the `CALIBRATION` button. This will open up the calibration interface.

<p align="center">
  Image Description
  <p align="center"><i><b>2D Tactile calibration setup</b></i></p>
</p>

In this callibration setup, initially the `Amplitude` has setted to 100, and the `Pulse width` has setted to 100. When you increase the amplitude, you can feel a blinking pattern from the electrodes and in the GUI, the electrode color strted to change according to the amplitude level (Green to Red).

1. Increase the amplitude using `up arrow` key until you feel a slight tactile sensation. Then click on `SET AS LOWER THRESHOLD` button. This will update your lower thershold values in the GUI.

2. After setted the lower thershold, increase the amplitude furtur until you feel uncomfortable tactile sensation. Use this point as your upper thershold by click on `SET AS UPPER THRESHOLD` button. This will update your upper thershold values in GUI.

**NOTE:** If you want, you can increase the `Pulse width` along with the amplitude as well. Anyway, both `Amplitude` and `Pulse width` values will be recorded when set the thersholds.

After calibration, you can initialize the execution program by clicking on `INITIALIZE` button.
Here, when you click on the `INITIALIZE` button, a pop up window will appear and show you a calibration summery.

<p align="center">
  Image Description
  <p align="center"><i><b>2D Tactile calibration setup</b></i></p>
</p>

<p align="center">
  Image Description
  <p align="center"><i><b>2D Tactile calibration setup</b></i></p>
</p>

After showing the calibration summery window if you feel like you didn't calibrate correctly, you can click on `GO BACK` button and do the calibration again.

If all looks good, you can click on `CONTINUE` button and go to execution stage.

**Step 3: Execute the 2D pattern**
After you come to the execution stage, you can see an interface like follows.

<p align="center">
  Image Description
  <p align="center"><i><b>2D Execution interface </b></i></p>
</p>

Here, in top left side, it shows your selected `COM port` and there is a button named `IMPORT PATTERN JSON`. 

**`IMPORT PATTERN JSON` button:**
  Here, you have to include the JSON file that contains details about your stimulation pattern.

And the top right side, it shows the stimulation `frequency` value and the `polarity`.

**NOTE: Visual eloboration of the following parameter descriptions can be seen in [Section 5.1](#51-overview-of-pulse-parameters).**

**Bottom left side:**

1. **`POLARITY` switch:** By using this switch, you can toggle the polarity to `anodic` or `cathodic`. Default it is `anodic`.
2. **`STIMULATION FREQUENCY` slider:** By using this slider, you can adjust the stimulation frequency. Default it has setted to 75Hz.
3. **`DISCHARGE TIME` slider:** Gap between two consecutive pulses in two electrodes.

4. **`Amplitude` and `Pulse Width`:** Here, it display the stimulation pulse Amplitude and the stimulation pulse width.

5. **`OVERRIDE` button:** Since pattern creator export all frequency and stimulation mode details, we don't need to give a fixed frequecncy or a fixed stimulation mode to the pattern. Therefore, initinally the `POLARITY` switch and `STIMULATION FREQUENCY` slider has deactivated. If you really need to control frequency and stimulation mode manually, you can click on `OVERRIDE` button and activate frequency slider and polarity switch and manually control those parameters.

**Bottom right side:**

1. **`PULSE HEIGHT` textbox:** Here, you can update the `sense pulse height`.
2. **`PULSE WIDTH` textbox:** Here, you can update the `sense pulse width`.
3. **`Sense Height` and `Sense Width`:** Here, it display the sense pulse Amplitude and the sense pulse width.

**Middle right side:**

Here, it displays the real time readings from sensing (touched electrodes).

**`START/STOP` button:** by clicking on this you can start or stop the program.

**`BACK TO HOME` button:** by clicking on this, you can go back to 2D pattern home page.

By clicking on `START` button, you can execute the program and the real time execution pattern will appear in the screen.

<p align="center">
  Image Description
  <p align="center"><i><b>2D pattern execution</b></i></p>
</p>

**Note:** You can quickly set the `amplitude` and `pulse width` to 100 by pressing the `space bar`.

**Electrode feedback readings**

In the execution GUI, in the bottom right corner, there are two text boxes as `start`, `end` and a button called `DISP` as shown in below.

<p align="center">
  Image Description
  <p align="center"><i><b>Feedback readings inputs</b></i></p>
</p>

Here you have to input the range of electrodes that you want to observe the feedback readings and click on the `DISP` button. Then the readings will be display on the right corner of the GUI.

**Note: press `ENTER` after you insert values for each boxes, `START` and `END`.**

Then, it will display the readings and touched electrodes as shown in below.

**Note: Irrespective of the inputted range, this will display feedback for all touched electrodes if there is contact.**

<p align="center">
  Image Description
  <p align="center"><i><b>Feedback readings in GUI</b></i></p>
</p>

### **8.2 3D MODE (for 3D patterns)**

After you click on the `3D MODE` button, the GUI for 3D pattern will appear. (**Note:** it will may take about 5 seconds)

<p align="center">
  Image Description
  <p align="center"><i><b>Open the 3D execution program</b></i></p>
</p>

#### **Explanation of elements in the GUI**

<p align="center">
  Image Description
  <p align="center"><i><b>3D execution program interface</b></i></p>
</p>

Every button and the drop down menu in here is same as the 2D mode configuration mentioned in [Section 8.1](#81-2d-mode-for-2d-patterns) except the `IMPORT 3D OBJECT` button.

1. **IMPORT 3D OBJECT**
  By clicking on this button, you can select your 3D object file (this should be in .obj format).

### Execute a 3D pattern using GUI

#### Step 1: Select COM Port, 3D object and appropriate JSON files

1. Select the `COM port` that belongs to your hardware.
2. Select the object file (.obj) that belongs to your 3D object.
    **NOTE:** When you try to browse the first file, the browsing window maybe appear inder your GUI. Therefore, if you can't see a browsing window, plese check under the GUI as follows.

    <p align="center">
      Image Description
      <p align="center"><i><b>3D execution program interface</b></i></p>
    </p>

3. Select the JSON file that belongs to your electrode array.

All these steps are same as the 2D pattern exection.

After selecting above `COM port` and necessary JSON files, you can directly go to the `INITIALIZE` and execute the pattern.
But, you **don't have** a control of stimulation intensity level. **Therefore, we advice you to Calibrate before Initialize**.

#### Step 2: Calibration

After import necessery JSON files, click on the `CALIBRATION` button. This will open up the calibration interface.

<p align="center">
  Image Description
  <p align="center"><i><b>3D Tactile calibration setup</b></i></p>
</p>

Here, if you have touched an electrode, it appears as a light-green color ring around touched electrodes as you can see here.

The process is same as the calibratio process for 2D pattern.
Therefore, please refer the **Step 2: Calibration** under the [Section 8.1](#81-2d-mode-for-2d-patterns).

#### Step 3: Execute the 3D pattern

After you come to the execution stage, you can see an interface like follows.

<p align="center">
  Image Description
  <p align="center"><i><b>3D Execution interface </b></i></p>
</p>

All the elements in here are same as the elements in the 2D interface.
Therefore, please refer the **Step 2: Execute the 2D pattern** under the [Section 8.1](#81-2d-mode-for-2d-patterns).

<p align="center">
  Image Description
  <p align="center"><i><b>3D pattern execution</b></i></p>
</p>

##### **NOTE: 3D Movements Controls**

In 3D execution interface, you can freely do any movement to your 3D object like rotation, translation or zoom in/out.

- Use **mouse wheel** to zoom in or zoom out the object.
- To translate the object **click and hold** the **RIGHT MOUSE BUTTON** and move your object.
- To rotate your object use your **LEFT MOUSE BUTTON**.

### **8.3 Warning messages**

There are two types of warning messeages you can see when you use the toolkit.

1. **You are going to initialize before calibration**
    This warning message will appear when you are trying to initialize the execution program **without doing calibration**.

    <p align="center">
      Image Description
      <p align="center"><i><b>Initialize before calibration</b></i></p>
    </p>

    In this warning message,
      1. If you click on `CONTINUE`, you can go to the execution program and do electrotactile stimulation. But, **please be careful** because you don't have any indication of your sensation thersholds.
      2. If you click on `GO BACK`, you can stay where you are in now.

2. **Warning! Exceeded Calibration Limits!**
    This warning message will appear when you are increasing the `Amplitude` or `Pulse Width` more than the **upper thershold values** of your calibration stage.

    <p align="center">
      Image Description
      <p align="center"><i><b>Exceeded Calibration Limits!</b></i></p>
    </p>

    - If you click on `CONTINUE`, you can increase the `Amplitude` and the `Pulse Width` as you want, But, **please be careful** because you don't have any indication of your sensation thersholds thereafter.

    - If you click on `GO BACK`, you can safely stay below your thershold.

---

## 9. API Integration

The API supports accessing/setting all the parameters that are done using the GUI. To be more specific the API is capable of setting all the Stimulation Parameters described in [Section 5](#5-firmware) above. Below are the relevant descriptions of the functions **(ignore cases and naming conventions)**

| Functions | Description |
| --- | ---  |
| `send_electrode_number` | Set the number of electrodes used |
| `send_stimulation_polarity` | Set the polarity of stimulation (Anodic/Cathodic Stimulation) |
| `send_stimulation_pulse_height` | Set pulse height of the stimulation pulse |
| `send_stimulation_pulse_width` | Set the pulse width of stimulation pulse |
| `send_sense_pulse_height` | Set the sense pulse height |
| `send_sense_pulse_width` | Set the sense pulse width |
| `send_channel_discharge_time` | Set the channel discharge time |
| `send_stimulation_frequency` | Set the stimulation frequency |
| `send_stim_pattern` | Send the stimulation patter |
| `get_voltage_readings` | Get the voltage accross (0-255 mapped - 8bit) sense resistor |
| `update_and_get_hv513_count` | Get the number of HV513(Switching ICs) detected by the board |
| `set_electrode_mapping` | Set the electrode mapping(Inclass Function) |

### 9.1. Python API

You need to have the `Pyserial` Library to handle the serial communication with the hardware.
To install the Library you can run the following snippet in your COmmand Line Interface (activate virtual environment if you are using one).

```bash
pip install pyserial
```

The code for the python API can be founc here:

```bash
6_APIs\1_Python_API
```

You can directly add this files to your project directory and follow the `main.py` to include the API in your project. Documentation for each function of the API is provided in the `docs_html` in the above folder location.

### 9.2. Unity API

The code for the Unity API can be found here:

```bash
6_APIs\2_Unity_API
```

**IMPORTANT!:** Inorder to manage the serial communication between hardware and the Host device **.NET Framework** should be selected by going to `Edit->Project Settings->Player-> Api Compatibility Level`. This will enable the packages used for serial communication.

You can add these scripts to your `Assets`(`Assets/Scripts` folder if you have one) folder. You can create assign the `EtactileKit.cs` script to an empty gameobject. Here you can specify the `COM port` in the inspector.

You can refer to the application developed in [Section 10](#10-examples--demos) to have a better understanding of using the API effectively.

---

## 10. Examples & Demos

### 10.1 Interactive Virtual Reality Button in Unity 3D

The Unity project can be found in the following location.

```bash
7_Application\2_Unity_VR_Button
```
  
This is a simple example of adding electro-tactile feedback when a 3D button is pressed. This can be further improved to simulate different haptic profiles for the buttons.

<p align="center">
  Image Description
  <p align="center"><i><b>Application of a haptic feedback button in VR</b></i></p>
</p>

---

## 11. FAQs

1. **How can you use the hardware for higher number of electrodes (Greater than 64)?**
  Please refer to the steps as mentioned in [Section 4](#4-hardware-design) and carefully follow instructions.

---

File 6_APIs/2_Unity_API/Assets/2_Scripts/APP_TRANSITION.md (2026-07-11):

# Deploying to Meta Quest 3 (Standalone Android Build)

This guide takes the eTactileKit Unity project from a **PC / Quest Link** setup to an **app that runs
directly on the Quest 3 headset** (Android standalone). On the headset the hardware is reached over
**WiFi with a fixed IP address** — serial (USB `COM`) is PC-only, and UDP auto-discovery is left
**off** so no extra Android permission or native code is needed.

> **Guiding principle:** the scene, haptics logic, patterns, calibration format and `HapticController`
> are **identical** on both targets. The **code already builds for both** — serial is auto-excluded on
> Android, the calibration loads correctly from inside the APK, and the kill switch is the same hand
> gesture everywhere. You only change **build settings** and point the manager at the kit's **IP**.
>
> The migration is **bidirectional**: this guide goes Windows → Android; switching back
> (Android → Windows / Quest Link) is covered in **§11** and also needs no code changes.

---

## 1. What changes at a glance

| Aspect | PC / Quest Link (today) | Quest 3 standalone (this guide) |
|---|---|---|
| Build target | Windows, Mono/IL2CPP | **Android, IL2CPP, ARM64** |
| Transport | Serial **or** WiFi | **WiFi only** (serial auto-excluded in code) |
| WiFi connection | Discovery **or** manual IP | **Manual IP** (discovery off - no extra permission) |
| Calibration load | from StreamingAssets | same file, read via `UnityWebRequest` on Android (built in) |
| Kill switch | **Hand gesture** (three-finger pinch) | **Same hand gesture** — one component, both modes |
| XR | Meta XR via Link | Meta XR **on-device** (Oculus/Meta plugin, ARM64) + hand tracking |
| Networking | any | **INTERNET permission** (added by *Internet Access = Require*) |
| Logs | Unity Console | `adb logcat` / Meta Quest Developer Hub |

Everything else — profiles, `PatternDB`, `HapticProfileProvider`, penetration detection, playback —
is untouched.

---

## 2. Prerequisites

- **Android Build Support** module installed in Unity Hub (✅ you have this) — includes the Android
  SDK, NDK and OpenJDK.
- **Meta XR All-in-One SDK** (`com.meta.xr.sdk.all`) already in the project (provides `OVRHand`, used
  by the kill switch, and the on-device runtime).
- A **Quest 3** in **Developer Mode** (enable in the *Meta Horizon* mobile app → *Devices* → your
  headset → *Developer Mode*; requires a verified developer org at developer.oculus.com).
- A USB-C cable, and optionally **Meta Quest Developer Hub (MQDH)** for install/log/streaming.
- The eTactileKit board reachable over WiFi at a **known IP** (same router in STA, or `192.168.4.1` in
  AP mode). Note the IP from the eTactileKitExplorer desktop app or your router's client list.

---

## 3. Part A — What the codebase already handles (no code edits)

These were built into the scripts so one codebase runs on both targets. Nothing to edit here:

- **Serial excluded on Android.** `SerialHandler.cs` and `ETactileKit.ConnectSerial` are wrapped in
  `#if UNITY_STANDALONE_WIN || UNITY_EDITOR`, and `ETactileKitManager.ConnectDevice` forces WiFi on
  non-desktop targets. The Android build never touches `System.IO.Ports`.
- **Calibration loads from inside the APK.** `ETactileKitManager` loads the StreamingAssets profile in
  a startup coroutine using `UnityWebRequest` on Android (and direct file I/O on desktop), so the same
  `template_32_electrode_calibration.json` works on device.
- **Unified kill switch.** `HapticKillSwitch.cs` (an `OVRHand` gesture) is the single emergency stop
  used on **both** PC/Link and the headset — there is no keyboard dependency anywhere.

The only scene step specific to the kill switch is wiring it up (also do this for the PC scene so both
behave identically):

1. Add a `HapticKillSwitch` component to a scene object (e.g. the manager's GameObject).
2. Assign **Manager**, and the **left/right `OVRHand`** components from your camera rig's hand anchors.
3. The gesture is **middle + ring + pinky pinched to the thumb** (index free), held ~1 s, on either
   hand — deliberate and effectively impossible to trigger by accident. `holdSeconds` is adjustable.

`OnDisable`/`OnApplicationQuit` also send OFF automatically as the safety net.

---

## 4. Part B — Unity project & build settings

### B1. Switch platform
`File ▸ Build Settings ▸ Android ▸ Switch Platform`. Add the open scene to *Scenes In Build*.

### B2. Run the Meta XR Project Setup Tool (does most of the work)
`Meta ▸ Tools ▸ Project Setup Tool` (a.k.a. *Oculus ▸ Tools*). Select the **Android** tab and **Apply
All** for *Required* and *Recommended* fixes. This sets Vulkan, Linear color space, IL2CPP/ARM64,
multithreaded rendering, correct min/target API, and more — saving you from setting them by hand.

### B3. XR Plug-in Management + hand tracking
`Project Settings ▸ XR Plug-in Management ▸ Android tab` → enable **Oculus** (Meta). Confirm your
scene has a working camera rig (the same `OVRCameraRig`/XR Origin you use over Link works on-device).
Because both the probes and the kill switch use hands, enable **Hand Tracking Support** on `OVRManager`
(*Quest Features* → Hand Tracking Support = *Controllers and Hands* or *Hands Only*). This also adds the
`com.oculus.permission.HAND_TRACKING` manifest entry automatically.

### B4. Player settings to verify (Project Settings ▸ Player ▸ Android)
- **Scripting Backend:** IL2CPP · **Target Architectures:** ARM64 only.
- **Api Compatibility Level:** `.NET Framework` (keep — required for `System.Net.Sockets`).
- **Minimum API Level:** Android 10 (API 29) or higher · **Target API Level:** as set by the Setup Tool.
- **Internet Access:** **Require** — this is what adds the `INTERNET` permission for TCP/UDP.
- **Package Name:** set a unique id, e.g. `com.yourorg.etactilekit`.
- **Active Input Handling:** `Both` (already set) works on device.

### B5. Configure the manager for WiFi-by-IP
Select the `ETactileKitManager` and set:
- **Connection Type = WiFi**
- **Use Discovery = OFF**
- **IP Address =** the board's address (STA: its fixed/known IP; AP: `192.168.4.1`)
- **Wifi Port = 8080**

That's the whole WiFi setup on device — no permission or native code beyond `INTERNET`. The code also
forces WiFi on Android as a safeguard if the field is left on Serial.

---

## 5. Part C — Android manifest / permissions

With **Internet Access = Require** (B4) Unity injects the only permission the app needs:
```xml
<uses-permission android:name="android.permission.INTERNET" />
```
Hand tracking (B3) adds `com.oculus.permission.HAND_TRACKING` for you. Because discovery is off, **no
multicast permission and no native code are required**. You normally don't need to hand-write a
manifest at all.

---

## 6. Part D — Deploy to the headset

1. **Enable Developer Mode** (Part 2) and connect the Quest via USB-C. In the headset, **Allow USB
   debugging** when prompted (check *Always allow from this computer*).
2. Verify the device is seen: `adb devices` should list it (adb ships with the Android module, under
   the Unity Hub Android SDK `platform-tools`). MQDH also shows it.
3. **Build & Run** (`Ctrl+B`) to build the APK, install and launch in one step. Or **Build** an APK
   and install with `adb install -r yourapp.apk` / drag into MQDH / SideQuest.
4. **View logs:** `adb logcat -s Unity` (all our messages are prefixed `[eTactileKit]`), or use MQDH's
   log viewer. Tick **Development Build** in Build Settings for full logs and easier debugging.

---

## 7. Part E — Connecting to the kit from the headset

Both modes use a **fixed IP** on the manager (Use Discovery off):

- **STA (same router):** put the Quest and the kit on the **same WiFi / subnet**. Give the board a
  stable address (a DHCP reservation on the router, or a static IP in its firmware) and enter it as
  **IP Address**. Ensure the router doesn't isolate clients, and that the Quest (often 5 GHz) and the
  board (often 2.4 GHz) can reach each other.
- **AP mode:** in the Quest's *Settings ▸ WiFi*, join the board's `eTactileKit_<ID>` hotspot, then set
  **IP Address = 192.168.4.1**. The headset has no internet while on the AP, but the installed app runs
  fine.

The one-time setup sequence, calibration and patterns behave exactly as on PC once the TCP link is up.
(Auto-discovery still exists for the PC/Link build if you want it there; it is simply left off for the
headset build.)

---

## 8. Build & test checklist

1. Project compiles for Android with **no `System.IO.Ports` errors** (serial is auto-excluded).
2. Meta Project Setup Tool: all Required fixes applied; IL2CPP + ARM64; Internet Access = Require.
3. Oculus/Meta enabled under XR Plug-in Management (Android); **Hand Tracking Support** on.
4. Manager: **WiFi**, **Use Discovery off**, correct **IP Address**, port 8080.
5. `HapticKillSwitch` in the scene with Manager + both `OVRHand`s assigned.
6. `template_32_electrode_calibration.json` present in `Assets/StreamingAssets/`.
7. Developer Mode on; `adb devices` lists the Quest.
8. Build & Run installs and launches; `adb logcat -s Unity` shows `[eTactileKit] Setup complete …`.
9. Touch a haptic object with a probe → stimulation fires (same as over Link); the three-finger pinch
   stops it.

---

## 9. Troubleshooting

| Symptom | Check |
|---|---|
| Build error mentioning `System.IO.Ports` / `SerialPort` | Ensure the platform guards are intact — `SerialHandler.cs` is wrapped in `#if UNITY_STANDALONE_WIN \|\| UNITY_EDITOR` and `ConnectSerial` is guarded. Don't call serial from your own code on Android. |
| App runs but "Could not read default calibration" | Confirm `template_32_electrode_calibration.json` is in `Assets/StreamingAssets/` and the manager's **Default Calibration File Name** matches. |
| Connects to nothing on device | Verify **IP Address** is the board's current IP and the Quest is on the same subnet (or joined the AP). `Internet Access = Require` must be set. The WiFi connect times out in 5 s rather than hanging. |
| No haptics but link is up | Same layer/depth checks as the main README (probe on `Probe Layer`, object on `Interactable Layer`, depth ≥ threshold). Serial vs WiFi doesn't change this. |
| Kill gesture never fires | Hand Tracking Support enabled (B3)? `OVRHand`s assigned on `HapticKillSwitch`? Hands actually tracked (in view)? Try lowering `holdSeconds` while testing. |
| Black screen / not entering VR | XR Plug-in Management → Oculus not enabled for Android, or no camera rig in the scene. Re-run the Project Setup Tool. |
| `adb` device unauthorized | Re-plug and accept **Allow USB debugging** in the headset. |

---

## 10. Keeping both targets working

- The serial guards keep the desktop path (`UNITY_STANDALONE_WIN`/`EDITOR`) and the Android path
  separate from one codebase — never call serial unconditionally from your own scripts.
- Test in the **Editor over Quest Link** for fast iteration (serial *and* WiFi available there), then
  do a standalone **Build & Run** for on-device validation (WiFi-by-IP only).
- The calibration profile, `PatternDB`, providers, controller and the `HapticKillSwitch` gesture are
  shared verbatim — author, calibrate and wire once, run on both.

---

## 11. Reverse transition — Android → Windows (Quest Link / PC)

Taking a project that is currently set up for the headset **back** to a PC / Quest Link build needs
**no code changes** — the same `#if` guards re-enable the desktop paths automatically. It is just a
platform toggle plus the PC-side XR settings.

### What re-enables itself automatically (no edits)
- **Serial** compiles back in (`SerialHandler`, `ETactileKit.ConnectSerial`) — a `COM` port works again.
- **Calibration** is read with direct file I/O (the `#else` branch) instead of `UnityWebRequest`.
- The **WiFi-force guard** in `ConnectDevice` no longer applies, so `Connection Type` is honored as set
  (Serial *or* WiFi), and **UDP discovery** is available again.

### Steps
1. **Switch platform back:** `File ▸ Build Settings ▸ Windows, Mac, Linux` → Target Platform
   **Windows** → *Switch Platform*. (Unity re-imports assets; this can take a while.) For quick work
   you can also just press **Play** in the Editor over Quest Link without building.
2. **XR Plug-in Management ▸ Windows/Standalone tab** (separate from the Android tab): enable
   **Oculus** (or OpenXR + Meta) so Quest Link runs on the PC runtime. The Android tab settings don't
   affect the PC build.
3. **Player ▸ Windows settings:** keep **Api Compatibility Level = .NET Framework** (needed for serial
   *and* sockets). **Scripting Backend** can be **Mono** (fastest iteration) or IL2CPP — either is fine
   on PC.
4. **Manager transport:** choose **Serial** (set `Port Name` / `Baud Rate`) or **WiFi** (discovery or a
   manual IP). Everything else — patterns, calibration, and the `HapticKillSwitch` gesture — is
   unchanged.
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

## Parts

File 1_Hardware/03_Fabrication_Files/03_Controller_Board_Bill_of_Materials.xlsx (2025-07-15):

Comment | Description | Designator | Quantity | Manufacturer_Part_Number
AD7276BUJZ-REEL7 | Integrated Circuit | AD1 | 1 | AD7276BUJZ-REEL7
KGM21NR71E104KT | Capacitor | C1, C8, C11, C15, C25 | 5 | KGM21NR71E104KT
08053A102FAT2A | Capacitor | C3 | 1 | 08053A102FAT2A
C0805C209D3HACTU | Capacitor | C4 | 1 | C0805C209D3HACTU
GRM21BR61A476ME15L | Capacitor | C10, C12, C16, C20, C21, C22, C23 | 7 | GRM21BR61A476ME15L
GR331CD7LP683KW01K | Capacitor | C13, C14, C18, C19 | 4 | GR331CD7LP683KW01K
08053C101JAT2A | Capacitor | C26 | 1 | 08053C101JAT2A
C0805C103J3GACAUTO | Capacitor | C27 | 1 | C0805C103J3GACAUTO
VJ0805Y223KXXAC | Capacitor | C28 | 1 | VJ0805Y223KXXAC
08053A221KAT2A | Capacitor | C29 | 1 | 08053A221KAT2A
SD0805S020S0R5 | Diode | D1 | 1 | SD0805S020S0R5
GSD2004S-HE3-08 | Diode | D2, D3 | 2 | GSD2004S-HE3-08
AD5452YRMZ-REEL7 | Integrated Circuit | DA1 | 1 | AD5452YRMZ-REEL7
MOUDLE-SEEEDUINO-XIAO-ESP32S3-SMD | ESP32S3 | ESP32-S3 | 1 | 113991114
LT3757IMSE#PBF | Integrated Circuit | IC1 | 1 | LT3757IMSE#PBF
HV513WG-G | Integrated Circuit | IC3 | 1 | HV513WG-G
67996-100HLF | BergStik<sup>&reg;</sup>, Board to Board connector, Unshrouded vertical header, Through Hole, Double Row, 0 Positions, 2.54 mm (0.100in) Pitch | J1, J2, J3, J6 | 4 | 67996-100HLF
SSQ-112-01-S-S | 12 Position, .100&quot; Tiger Buy&trade; Socket Strip, Square Tail, Single Row | J4, J5 | 2 | SSQ-112-01-S-S
SSQ-102-02-S-S-RA | Connector | J8 | 1 | SSQ-102-02-S-S-RA
SSQ-105-01-S-S | 5 Position, .100&quot; Tiger Buy&trade; Socket Strip, Square Tail, Single Row | J10, J11 | 2 | SSQ-105-01-S-S
ATB322515-0110 | Transformer | L1 | 1 | ATB322515-0110
PRT-08506 | Connector | Onboard electrode OUT | 1 | PRT-08506
TL072ACP | Integrated Circuit | OP1, OP2 | 2 | TL072ACP
ERJ-P06F3302V | Resistor | R1, R20 | 2 | ERJ-P06F3302V
HV732ARTTD105J | Resistor | R2 | 1 | HV732ARTTD105J
RK73H2ATTD9101F | Resistor | R3 | 1 | RK73H2ATTD9101F
RK73B2ATTD123J | Resistor | R4 | 1 | RK73B2ATTD123J
ERJ-P06F2201V | Resistor | R5 | 1 | ERJ-P06F2201V
ERJ-P06F2702V | Resistor | R6 | 1 | ERJ-P06F2702V
ERJ-P06J102V | Resistor | R7 | 1 | ERJ-P06J102V
RCC0805100KFKEA | Resistor | R9 | 1 | RCC0805100KFKEA
WSL0805R0200FEA18 | Resistor | R10 | 1 | WSL0805R0200FEA18
RCC080547K0FKEA | Resistor | R11 | 1 | RCC080547K0FKEA
RK73B2ATTD134J | Resistor | R12 | 1 | RK73B2ATTD134J
ERJ-T06J220V | Resistor | R13, R19 | 2 | ERJ-T06J220V
RK73B2ATTDD682J | Resistor | R14 | 1 | RK73B2ATTDD682J
ERJ-P06F1004V | Resistor | R15, R16, R17 | 3 | ERJ-P06F1004V
RK73H2ATTD1782F | Resistor | R18 | 1 | RK73H2ATTD1782F
ERJ-PB6B2402V | Resistor | R21 | 1 | ERJ-PB6B2402V
RK73H2ATTD1002F | Resistor | R26 | 1 | RK73H2ATTD1002F
CRS0805-FX-1000ELF | Resistor | R29 | 1 | CRS0805-FX-1000ELF
CRCW080540K0FKEA | Resistor | R30 | 2 | CRCW080540K0FKEA
RCA080560K4FKEA | Resistor | R31 | 2 | RCA080560K4FKEA
ZTX958 | Transistor BJT PNP | T1, T2, T3 | 3 | ZTX958
ZVN0545A | MOSFET (N-Channel) | T4 | 1 | ZVN0545A
IPD25N06S4L30ATMA2 | MOSFET (N-Channel) | U5 | 1 | IPD25N06S4L30ATMA2
SN74LVC8T245DWRG4 | Integrated Circuit | U8 | 1 | SN74LVC8T245DWRG4
MAX1044CPA+ | Power Supply | VREG | 1 | MAX1044CPA+

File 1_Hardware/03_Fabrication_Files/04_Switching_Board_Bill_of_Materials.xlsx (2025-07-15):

Comment | Description | Designator | Quantity | Manufacturer_Part_Number
67996-100HLF | 2 Pin, header | DIN | 1 | 67996-100HLF
22-28-8024 | Connector | EXTEND | 1 | 22-28-8024
HV513WG-G | Integrated Circuit | IC1, IC2, IC3, IC4, IC5, IC6, IC7, IC8 | 8 | HV513WG-G
PRT-14322 | SparkFun Accessories Photon Stackable Header- 12 Pin | J1, J2 | 2 | PRT-14322
SSQ-105-01-S-S | 5 Position, .100&quot; Tiger Buy&trade; Socket Strip, Square Tail, Single Row | J3, J4 | 2 | SSQ-105-01-S-S
FH12-16S-1SH_55_ | Connector | OUT[1-16], OUT[17-32], OUT[33-48], OUT[49-64] | 4 | FH12-16S-1SH(55)
ERJ-P06F5103V | Resistor | R1 | 1 | ERJ-P06F5103V

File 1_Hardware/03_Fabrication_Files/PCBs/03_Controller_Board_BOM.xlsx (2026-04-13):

Line # | Name | Description | Designator | Revision ID | Revision State | Revision Status | Quantity | Manufacturer 1
 | AD7276AUJZ-REEL7 | Integrated Circuit | AD1 |  | Not managed |  | 1
 | CL05B104KO5NNNC | Chip Capacitor, 100 nF, +/- 10%, 16 V, -55 to 125 degC, 0402 (1005 Metric), RoHS, Tape and Reel | C1, C2 |  | Unknown server |  | 2 | Samsung
 | GRM1552C1H102JA01D | Capacitor | C3 |  | Not managed |  | 1
 | 0402CG2R0C500NT | Multi-Layer Ceramic Capacitor 2pF C0G ±0.1pF 0402 Paper T/R | C4 |  | Unknown server |  | 1 | Murata
 | CL05B104KO5NNNC | Capacitor | C8, C11, C25 |  | Not managed |  | 3
 | GRM21BR61A476ME15L | Capacitor | C10, C12, C16, C20, C21, C22, C23 |  | Not managed |  | 7
 | C3225X7R2J683KT0L0U | Capacitor | C13, C14, C18, C19 |  | Not managed |  | 4
 | CL05B104KO5NNNC | Capacitor | C15 |  | Not managed |  | 1
 | 0402CG101J500NT | Capacitor | C26 |  | Not managed |  | 1
 | GRM155R71H103KA88D | Capacitor | C27 |  | Not managed |  | 1
 | CL21B223KBANNNC | Capacitor | C28 |  | Not managed |  | 1
 | GRM1555C1H221JA01D | Capacitor | C29 |  | Not managed |  | 1
 | MMBD3004S-7-F | Diode | D2 |  | Not managed |  | 1
 | AD5452YRMZ-REEL7 | Integrated Circuit | DA1 |  | Not managed |  | 1
 | SEED XIAO ESP32-SE |  | ESP32-S3 |  | Not managed |  | 1
 | LT3757EMSE#TRPBF | Integrated Circuit | IC1 |  | Not managed |  | 1
 | Saolder_bridge |  | J0 |  | Not managed |  | 1
 | 52885-0274 | Connector | J1, J2 |  | Not managed |  | 2
 | 532610271 | C177225 | J3 |  | Not managed |  | 1
 | 2307727-2 | Connector | J4 |  | Not managed |  | 1
 | ATB322515 |  | L1 |  | Not managed |  | 1
 | TL072IDR | Dual Low-Noise JFET-Input General-Purpose Operational Amplifier, 7 to 36 V, -40 to 85 degC, 8-pin SOIC (D8), Green (RoHS & no Sb/Br) | OP2, OP3 |  | Unknown server |  | 2 | Texas Instruments
 | SQD25N06-22LT4GE | 60V 25A 30mΩ@10V 2.5V 1PCSNChannel TO252-2L MOSFETs ROHS | Q5 |  | Not managed |  | 1
 | 0805W8F3302T5E | Resistor | R1, R20 |  | Not managed |  | 2
 | RC0603FR-071ML | Chip Resistor, 1 MOhm, +/- 1%, 100 mW, -55 to 155 degC, 0603 (1608 Metric), RoHS, Tape and Reel | R2 |  | Unknown server |  | 1 | Yageo
 | CRCW08059K10FKEA | RES Thick Film, 9.1kΩ, 1%, 0.125W, 100ppm/°C, 0805 | R3 |  | Unknown server |  | 1 | Vishay
 | RC0402FR-0712KL | RES SMD 12K OHM 1% 1/16W 0402 | R4 |  | Unknown server |  | 1 | Yageo
 | CRCW08052K20FKEA | RES Thick Film, 2.2kΩ, 1%, 0.125W, 100ppm/°C, 0805 | R5 |  | Unknown server |  | 1 | Vishay
 | RMC1/16SK273FTH-M | RES Thick Film, 27kΩ, 1%, 0.063W, 100ppm/°C, 0402 | R6 |  | Unknown server |  | 1 | Vishay
 | 0603WAF1001T5E | Resistor | R7 |  | Not managed |  | 1
 | RK73H1ETTP1003F | Resistor | R9 |  | Not managed |  | 1
 | RTT03R020FTP | METAL CURRENT SENSOR 0402 1% 150 | R10 |  | Unknown server |  | 1 | Yageo
 | RK73H1ETTP4702F | Resistor | R11 |  | Not managed |  | 1
 | RK73H1ETTP1303F | Resistor | R12 |  | Not managed |  | 1
 | RC0402FR-0722RL |  | R13, R19 |  | Unknown server |  | 2 | Yageo
 | RK73H1ETTP6801F | Resistor | R14 |  | Not managed |  | 1
 | ERJU02F1004X | Resistor | R15, R16, R17 |  | Not managed |  | 3
 | CRCW040216K0FKED | RES Thick Film, 16kΩ, 1%, 0.063W, 100ppm/°C, 0402 | R18 |  | Unknown server |  | 1 | Yageo
 | HPCR0402F24K0K9 | RES SMD 12K OHM 1% 1/16W 0402 | R21 |  | Unknown server |  | 1 | Yageo
 | MCS04020C1002FE000 | Resistor | R26 |  | Not managed |  | 1
 | RK73H1ETTP1000F | Resistor | R29 |  | Not managed |  | 1
 | RT0603BRD0740KL | Resistor | R30 |  | Not managed |  | 1
 | 0603WAF6042T5E | Resistor | R31 |  | Not managed |  | 1
 | PBHV9040TVL | Transistor BJT PNP | T1, T2, T3 |  | Not managed |  | 3
 | DMN60H080DS-13 | MOSFET (N-Channel) | T4 |  | Not managed |  | 1
 | SN74LVC8T245PWR | IC TRNSLTR BIDIRECTIONAL 24TSSOP | U8 |  | Unknown server |  | 1 | Texas Instruments
 | LTC1144IS8#PBF | Integrated Circuit | VREG |  | Not managed |  | 1

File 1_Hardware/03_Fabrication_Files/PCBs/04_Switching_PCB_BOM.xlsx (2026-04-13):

Line # | Name | Description | Designator | Quantity
 | FH12-16S-1SH_55_ | Connector | J1, J2 | 2
 | 52885-0274 | Connector | J3, J4 | 2
 | 53647-0274 | Connector | J5, J6 | 2
 | MCT06030C6042FP500 | Resistor | R1 | 1
 | HV513-QFN |  | U1, U2, U3, U4 | 4

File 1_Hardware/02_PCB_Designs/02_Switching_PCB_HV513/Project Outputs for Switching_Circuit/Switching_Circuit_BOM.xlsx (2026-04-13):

Line # | Name | Description | Designator | Quantity | Manufacturer 1 | Manufacturer Part Number 1 | Manufacturer Lifecycle 1 | Supplier 1 | Supplier Part Number 1 | Supplier Unit Price 1 | Supplier Subtotal 1
 | FH12-16S-1SH_55_ | Connector | J1, J2 | 2
 | 52885-0274 | Connector | J3, J4 | 2
 | 53647-0274 | Connector | J5, J6 | 2
 | MCT06030C6042FP500 | Resistor | R1 | 1
 | HV513-QFN |  | U1, U2, U3, U4 | 4

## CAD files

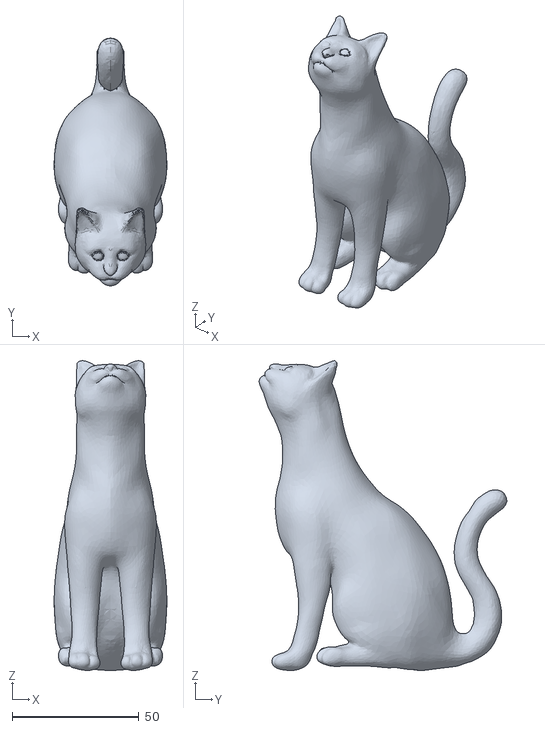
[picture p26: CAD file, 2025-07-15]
3_Electrode_Design_Tool/3_FabricationTool_App/outputs/3D_electrodes/Sitting_Cat_3.stl_main_mesh.stl
44.5 x 97.7 x 122.3

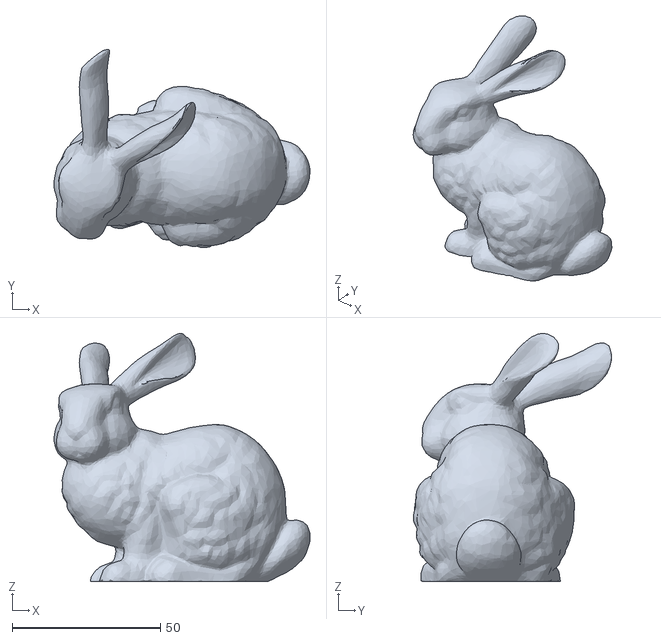
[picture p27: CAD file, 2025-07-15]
3_Electrode_Design_Tool/3_FabricationTool_App/outputs/3D_electrodes/Bunny_Test_main_mesh.stl
86.3 x 66.9 x 83.8

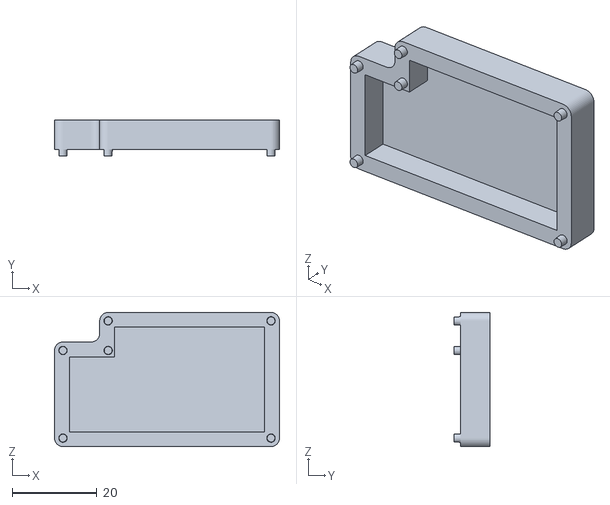
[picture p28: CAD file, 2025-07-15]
1_Hardware/04_Resources/PCB Housing - New.STL
53.1 x 8.60 x 31.7

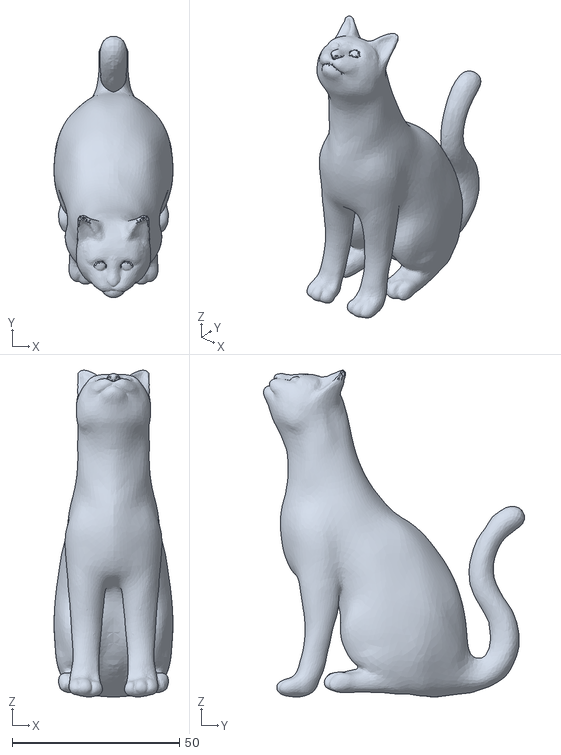
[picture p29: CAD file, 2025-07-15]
3_Electrode_Design_Tool/3_FabricationTool_App/meshes/Sitting_Cat.stl
35.6 x 78.2 x 97.8

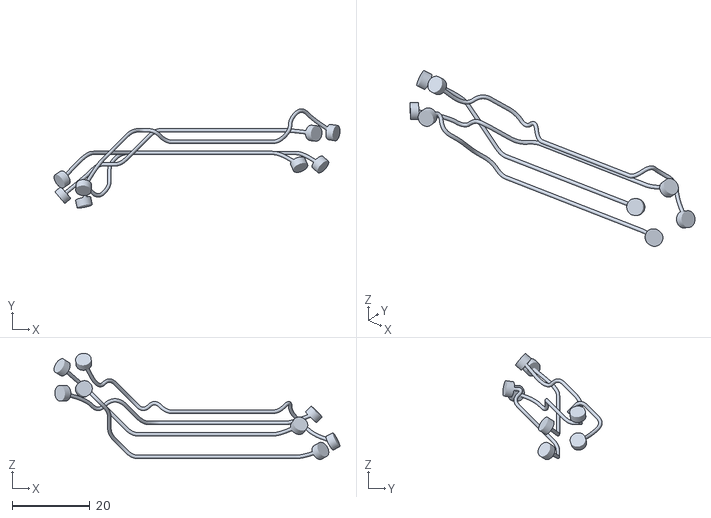
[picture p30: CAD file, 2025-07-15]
3_Electrode_Design_Tool/3_FabricationTool_App/outputs/3D_electrodes/Bunny_Test_routing_traces.stl
73.4 x 25.5 x 27.3

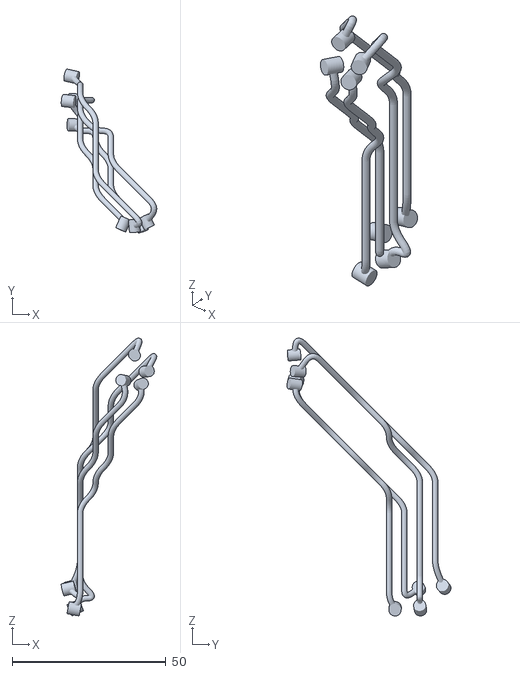
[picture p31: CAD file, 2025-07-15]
3_Electrode_Design_Tool/3_FabricationTool_App/outputs/3D_electrodes/Sitting_Cat_4.stl_routing_traces.stl
31.1 x 53.3 x 90.3

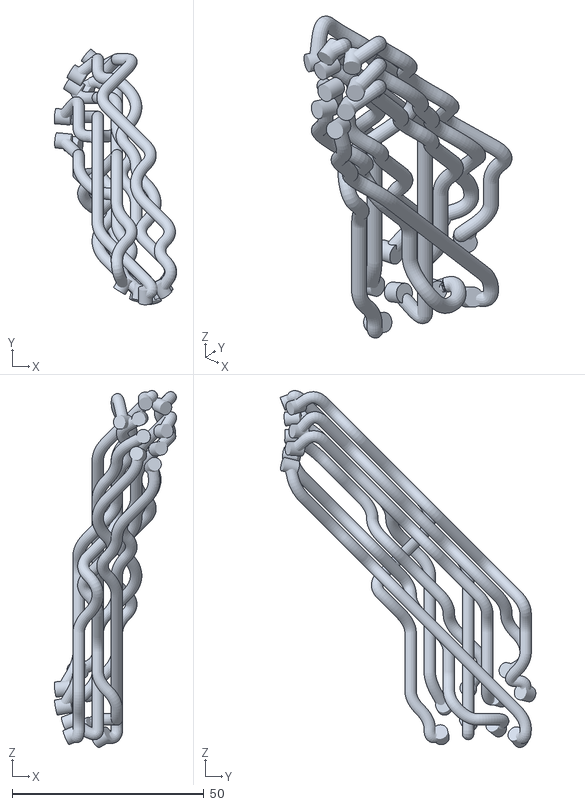
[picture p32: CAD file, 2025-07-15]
3_Electrode_Design_Tool/3_FabricationTool_App/outputs/3D_electrodes/Sitting_Cat_2.stl_routing_traces.stl
31.9 x 66.7 x 93.1

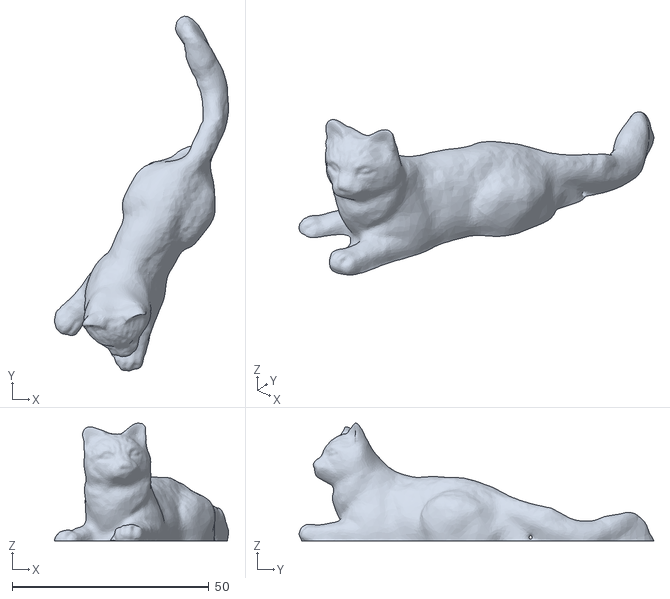
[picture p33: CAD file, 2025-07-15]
3_Electrode_Design_Tool/3_FabricationTool_App/meshes/yellowcat.stl
44.2 x 90.2 x 29.9

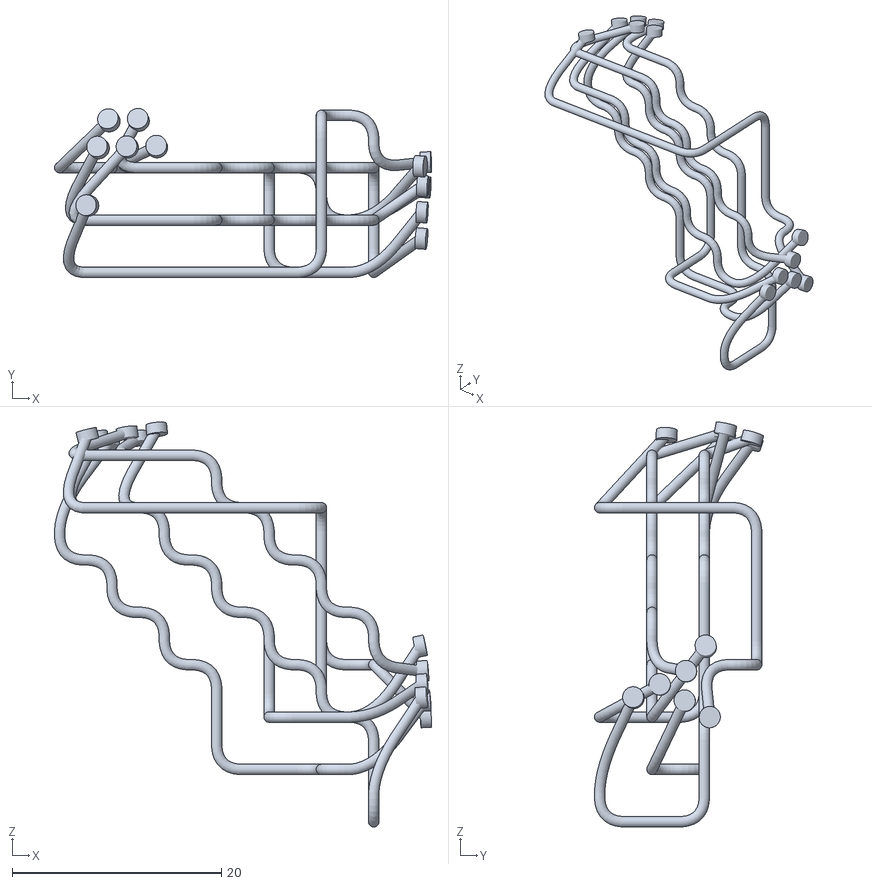
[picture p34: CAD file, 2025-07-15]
3_Electrode_Design_Tool/3_FabricationTool_App/outputs/3D_electrodes/Bunny_Back.stl_routing_traces.stl
36.0 x 16.2 x 38.7

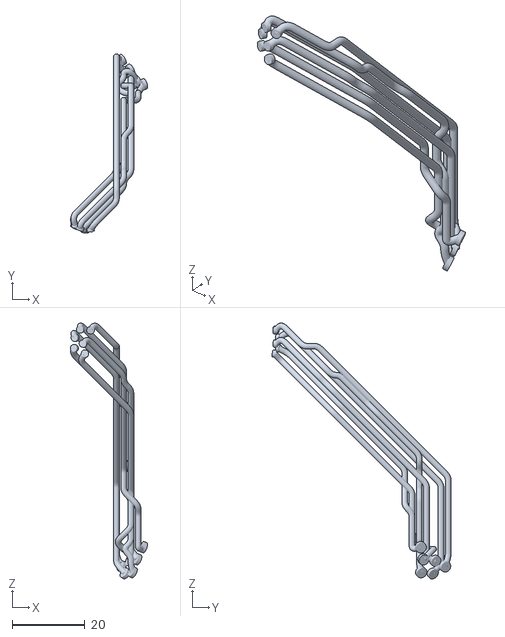
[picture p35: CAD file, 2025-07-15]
3_Electrode_Design_Tool/3_FabricationTool_App/outputs/3D_electrodes/Sitting_Cat.stl_routing_traces.stl
21.3 x 49.4 x 70.6

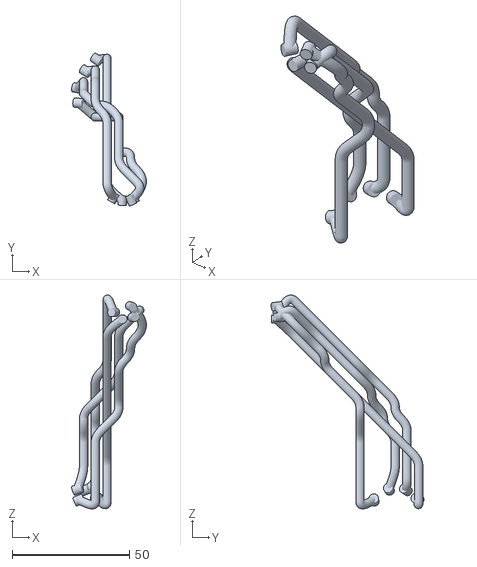
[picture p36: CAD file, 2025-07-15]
3_Electrode_Design_Tool/3_FabricationTool_App/outputs/3D_electrodes/Sitting_Cat_3.stl_routing_traces.stl
31.9 x 65.2 x 91.2

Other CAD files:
4_Pattern_Creator/Processing_program/Main/Objects/StanfordBunny.obj
3_Electrode_Design_Tool/3_FabricationTool_App/meshes/Sitting_Cat_Scaled.stl
3_Electrode_Design_Tool/3_FabricationTool_App/meshes/StanfordBunny.obj

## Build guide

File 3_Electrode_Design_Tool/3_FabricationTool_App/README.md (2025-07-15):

MyFabricationApp/
├── src/
│ ├── main.py
│ ├── app.py
│ ├── ui/
│ │ ├── mainwindow.ui
│ │ ├── adjustimagedialog.ui
│ ├── views/
│ │ ├── mainwindow.py
│ │ ├── twodviewer.py
│ │ ├── pcbviewer.py
│ │ ├── threedviewer.py
│ │ ├── adjustimagedialog.py
│ ├── controllers/
│ │ ├── twodcontroller.py
│ │ ├── pcbcontroller.py
│ │ ├── threedcontroller.py
│ │ ├── imageadjustcontroller.py
│ ├── models/
│ │ ├── basemodel.py
│ │ ├── imagemodel.py
│ ├── utils/
│ │ ├── fileutils.py
│ ├── resources/
│ │ ├── icons/
│ │ ├── stylesheets/
├── tests/
│ ├── test_2d.py
│ ├── test_pcb.py
│ ├── test_3d.py
├── requirements.txt
├── README.md

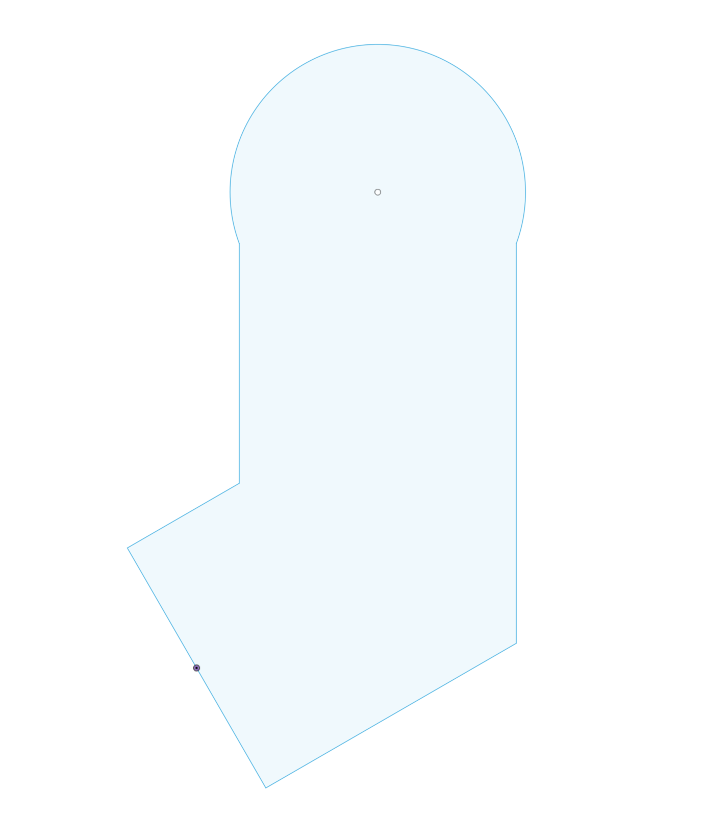
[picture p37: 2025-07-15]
3_Electrode_Design_Tool/3_FabricationTool_App/images/Finger_Wrap_2.png

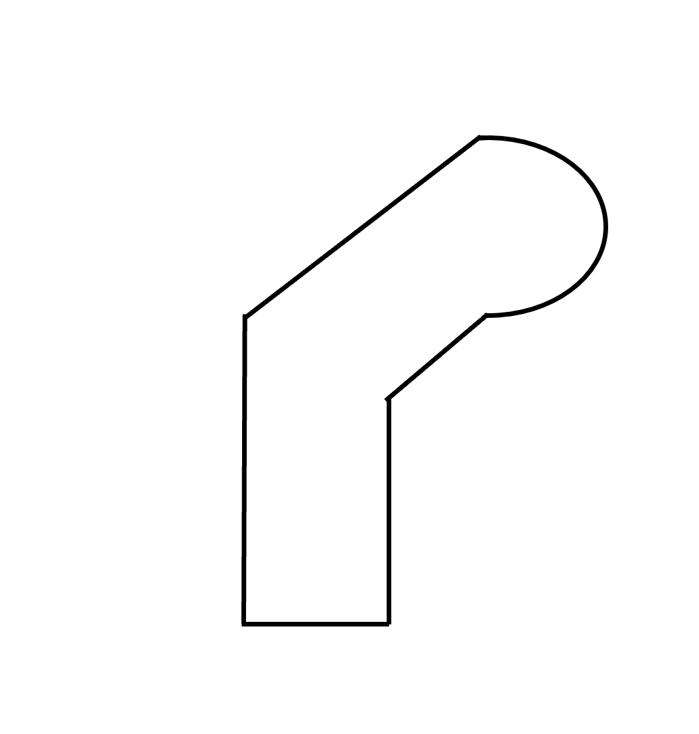
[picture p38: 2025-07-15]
3_Electrode_Design_Tool/3_FabricationTool_App/images/Finger_Wrap_4.png

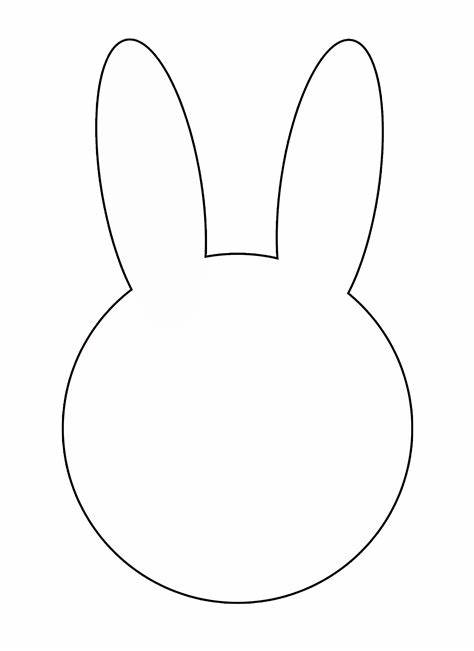
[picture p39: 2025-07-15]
3_Electrode_Design_Tool/3_FabricationTool_App/images/bunny.png

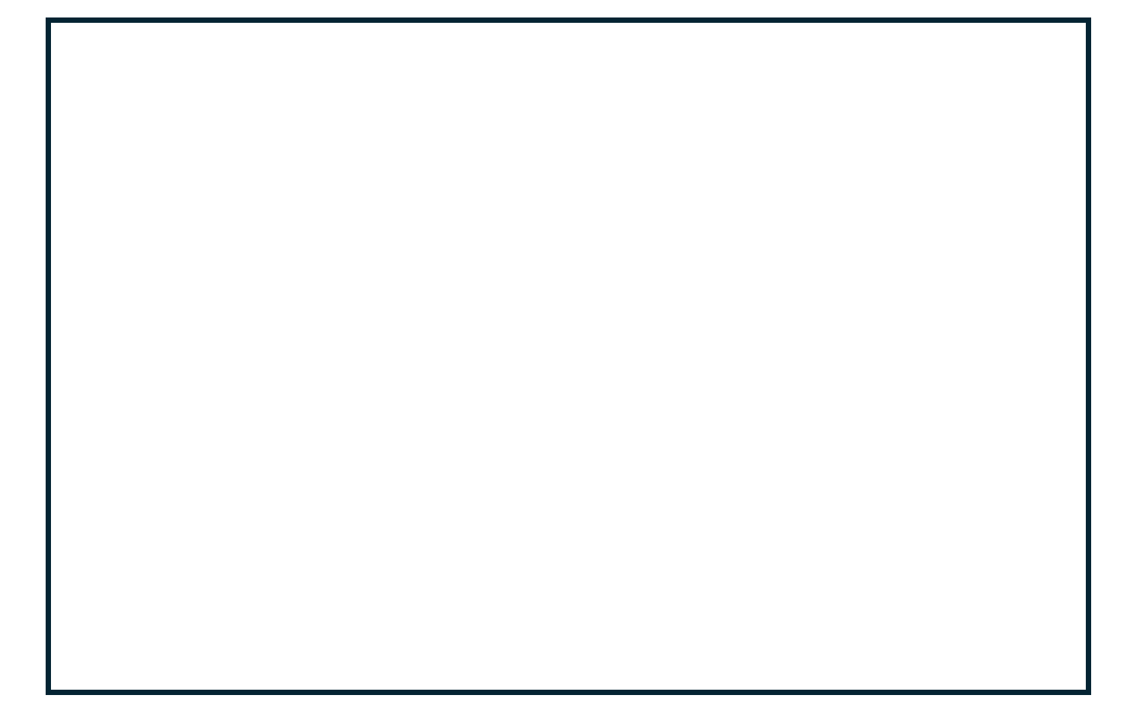
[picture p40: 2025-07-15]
3_Electrode_Design_Tool/3_FabricationTool_App/images/Rectangular_Pad.png

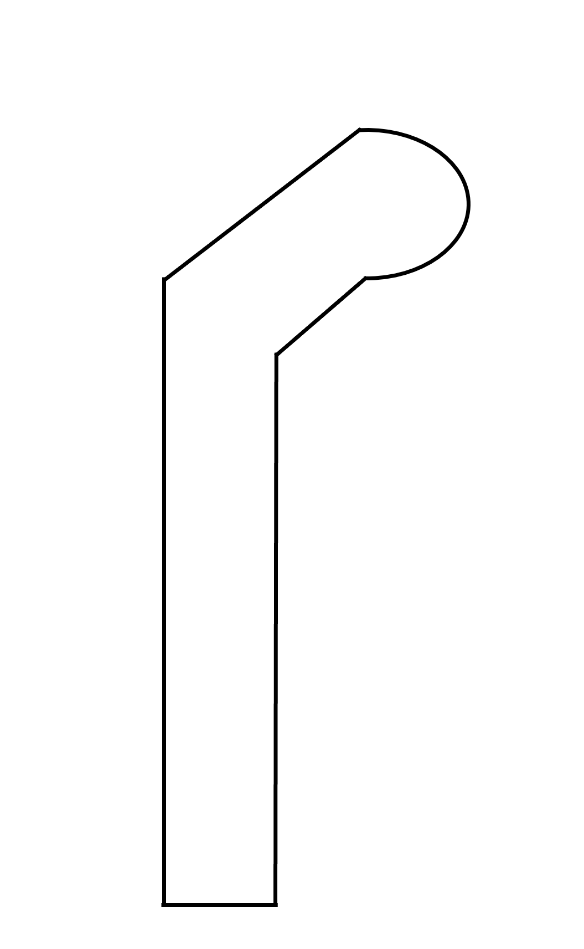
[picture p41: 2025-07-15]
3_Electrode_Design_Tool/3_FabricationTool_App/images/Finger_Wrap_3.png

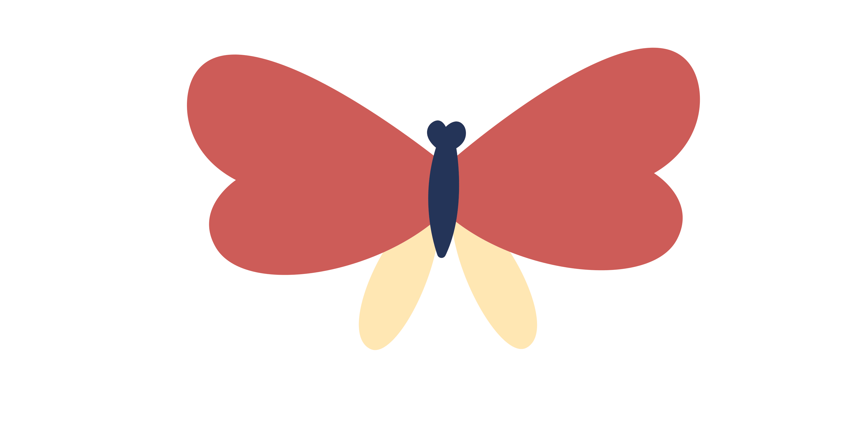
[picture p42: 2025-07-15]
3_Electrode_Design_Tool/3_FabricationTool_App/images/butterfly-1.png

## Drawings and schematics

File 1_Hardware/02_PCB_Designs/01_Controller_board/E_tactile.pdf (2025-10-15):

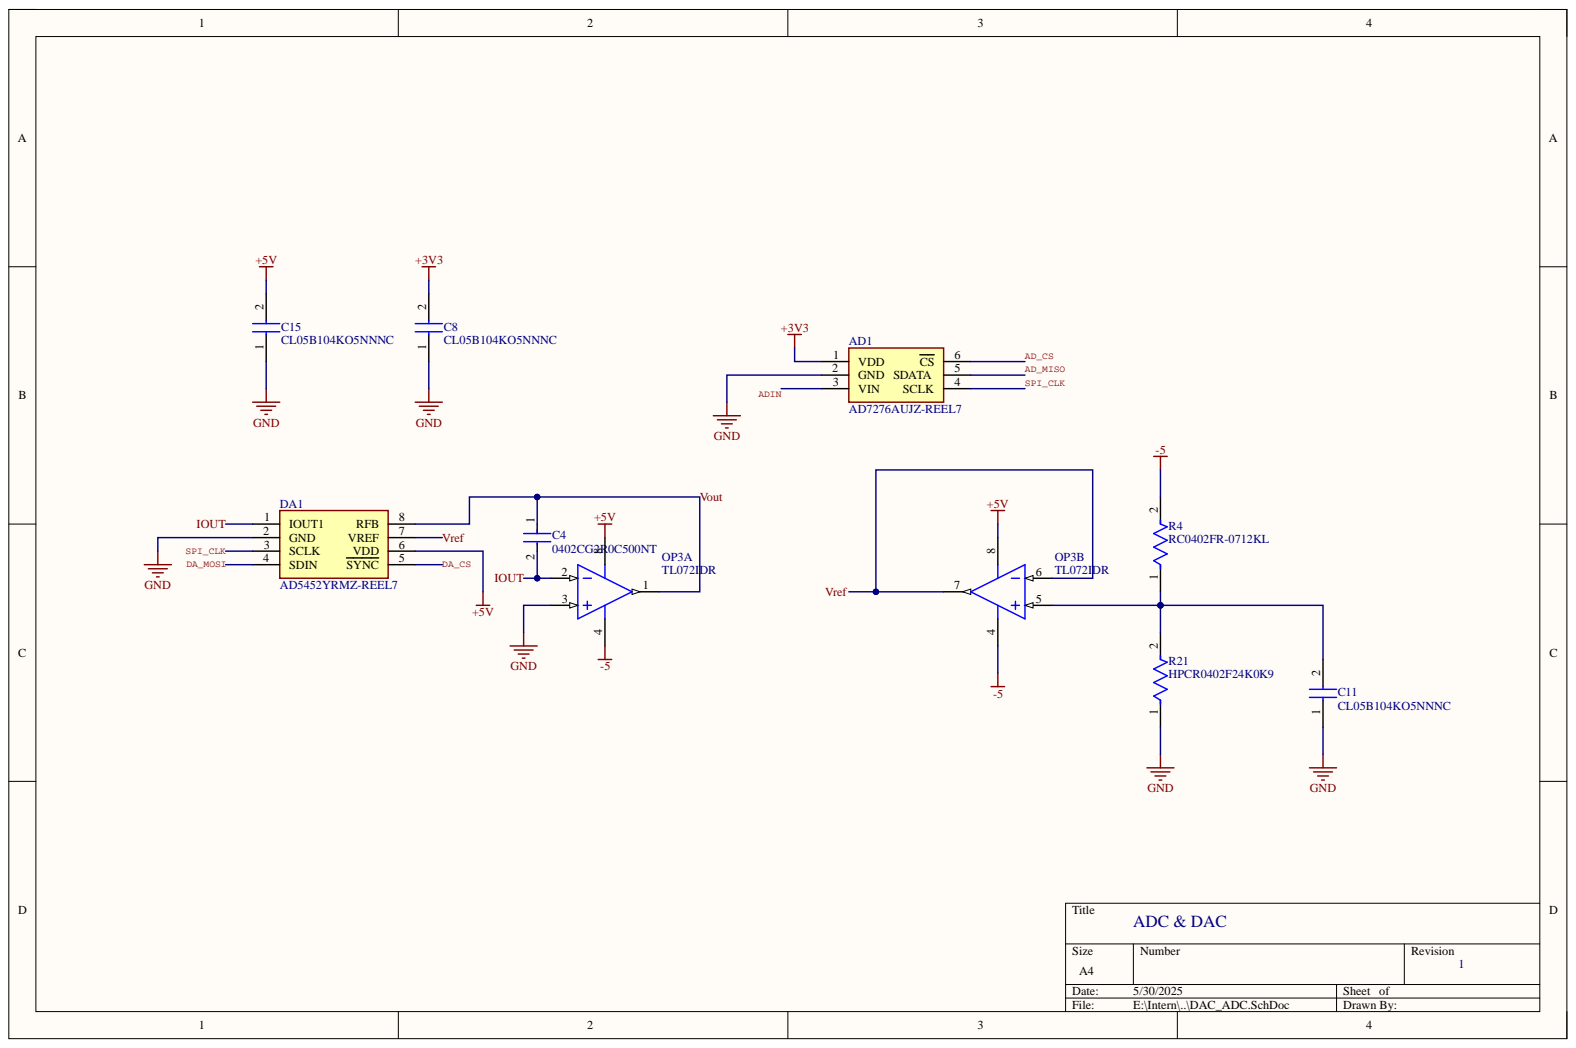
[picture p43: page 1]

Size A 4 | Numbe r | Revision 1

Date: 5/30/2025 | Sheet of
File: E:\Intern\..\DAC_ADC.SchDoc | Drawn By:

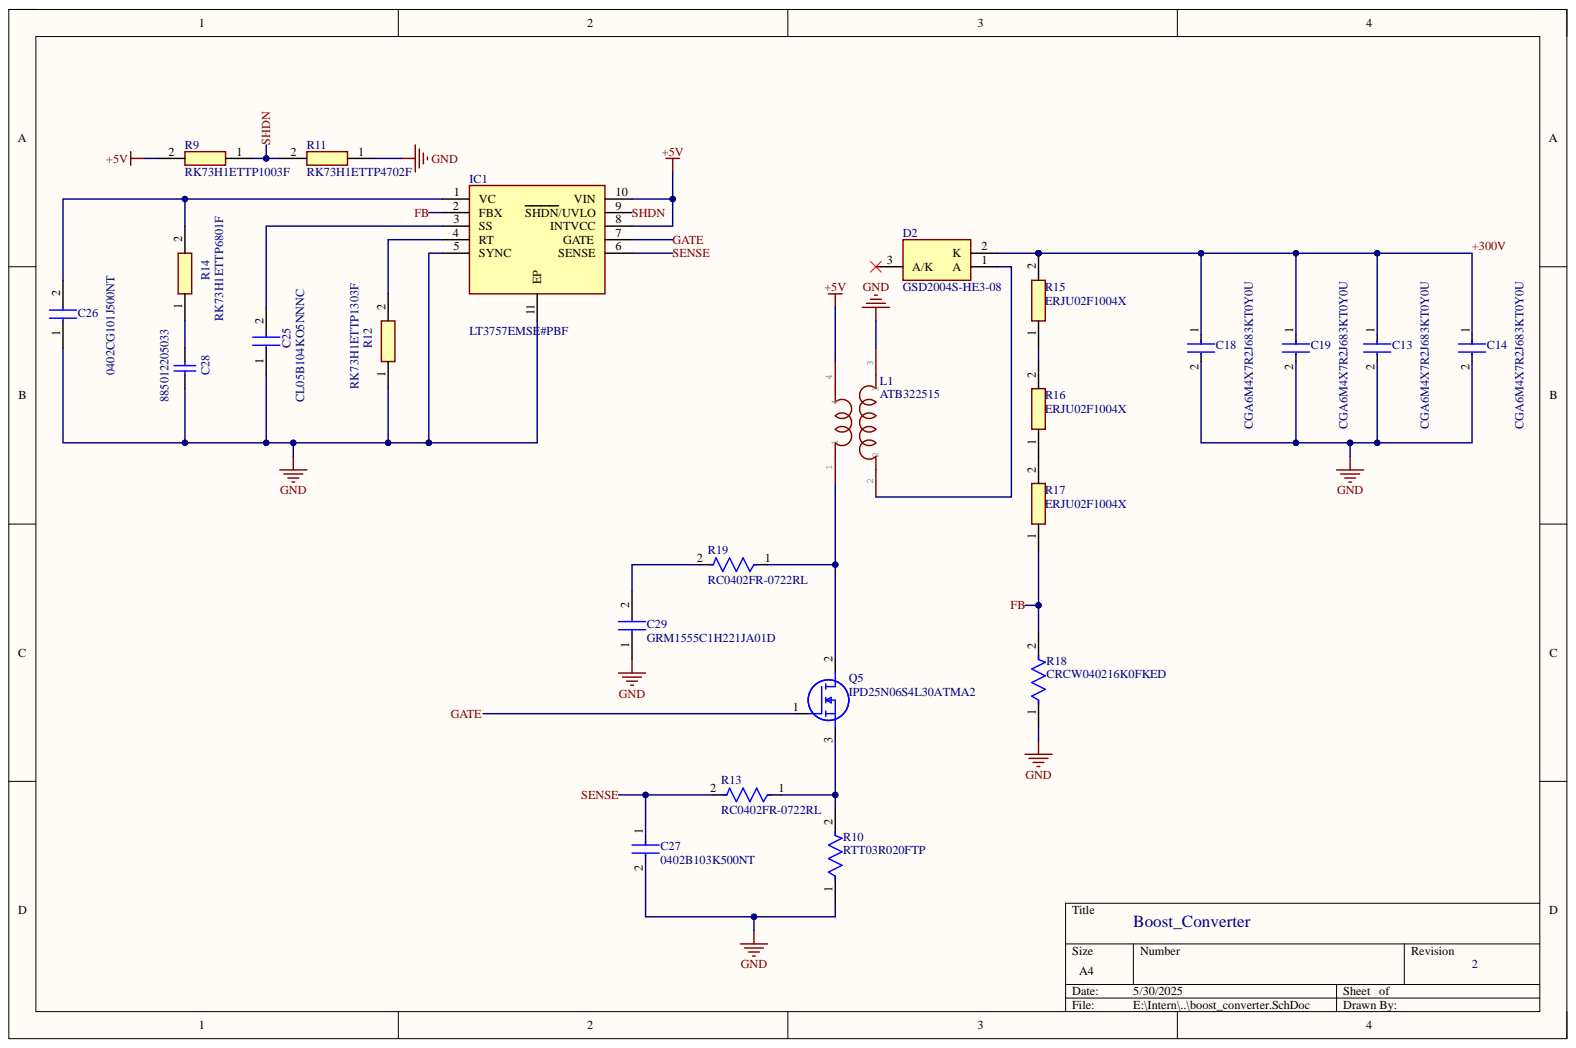
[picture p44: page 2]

FB | 2 | | 9 | SHDN

Size A 4 | Numbe r | Revision 2

Date: 5/30/2025 | Sheet of
File: E:\Intern\..\boost_converter . S chDoc | Drawn By:

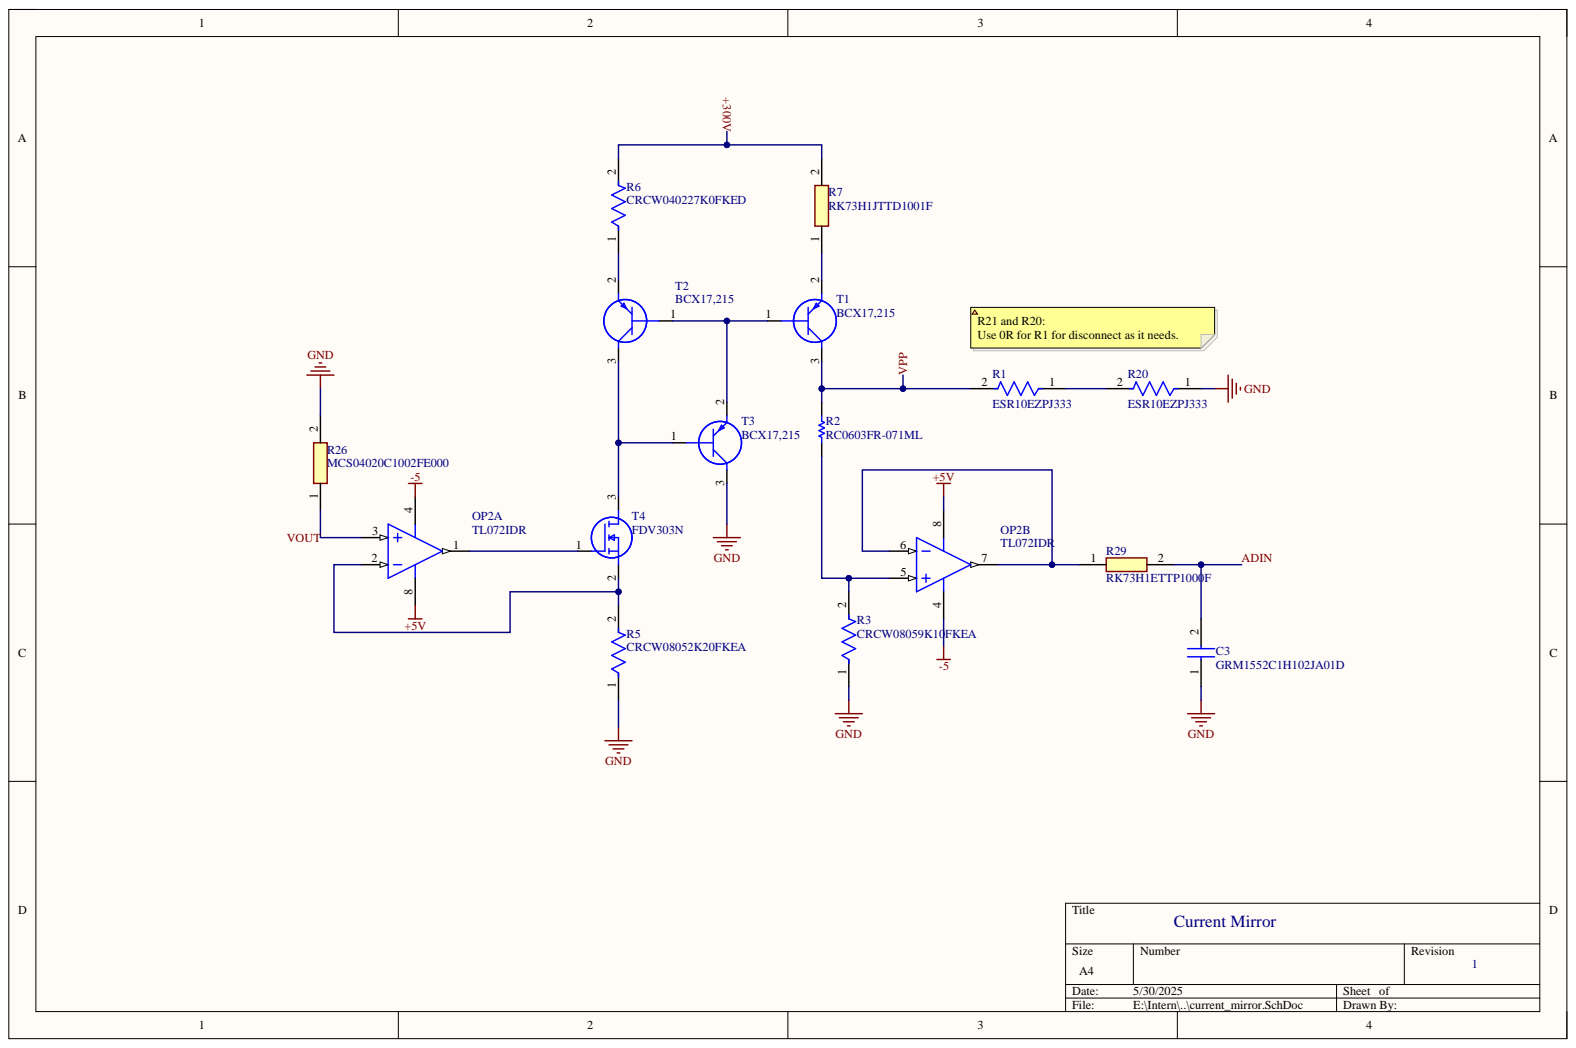
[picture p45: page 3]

R21 and R20:
Use 0R for R1 for disconnect as it needs.

Size A 4 | Numbe r | Revision 1

Date: 5/30/2025 | Sheet of
File: E:\Intern\..\current_mirror.S chDoc | Drawn By:

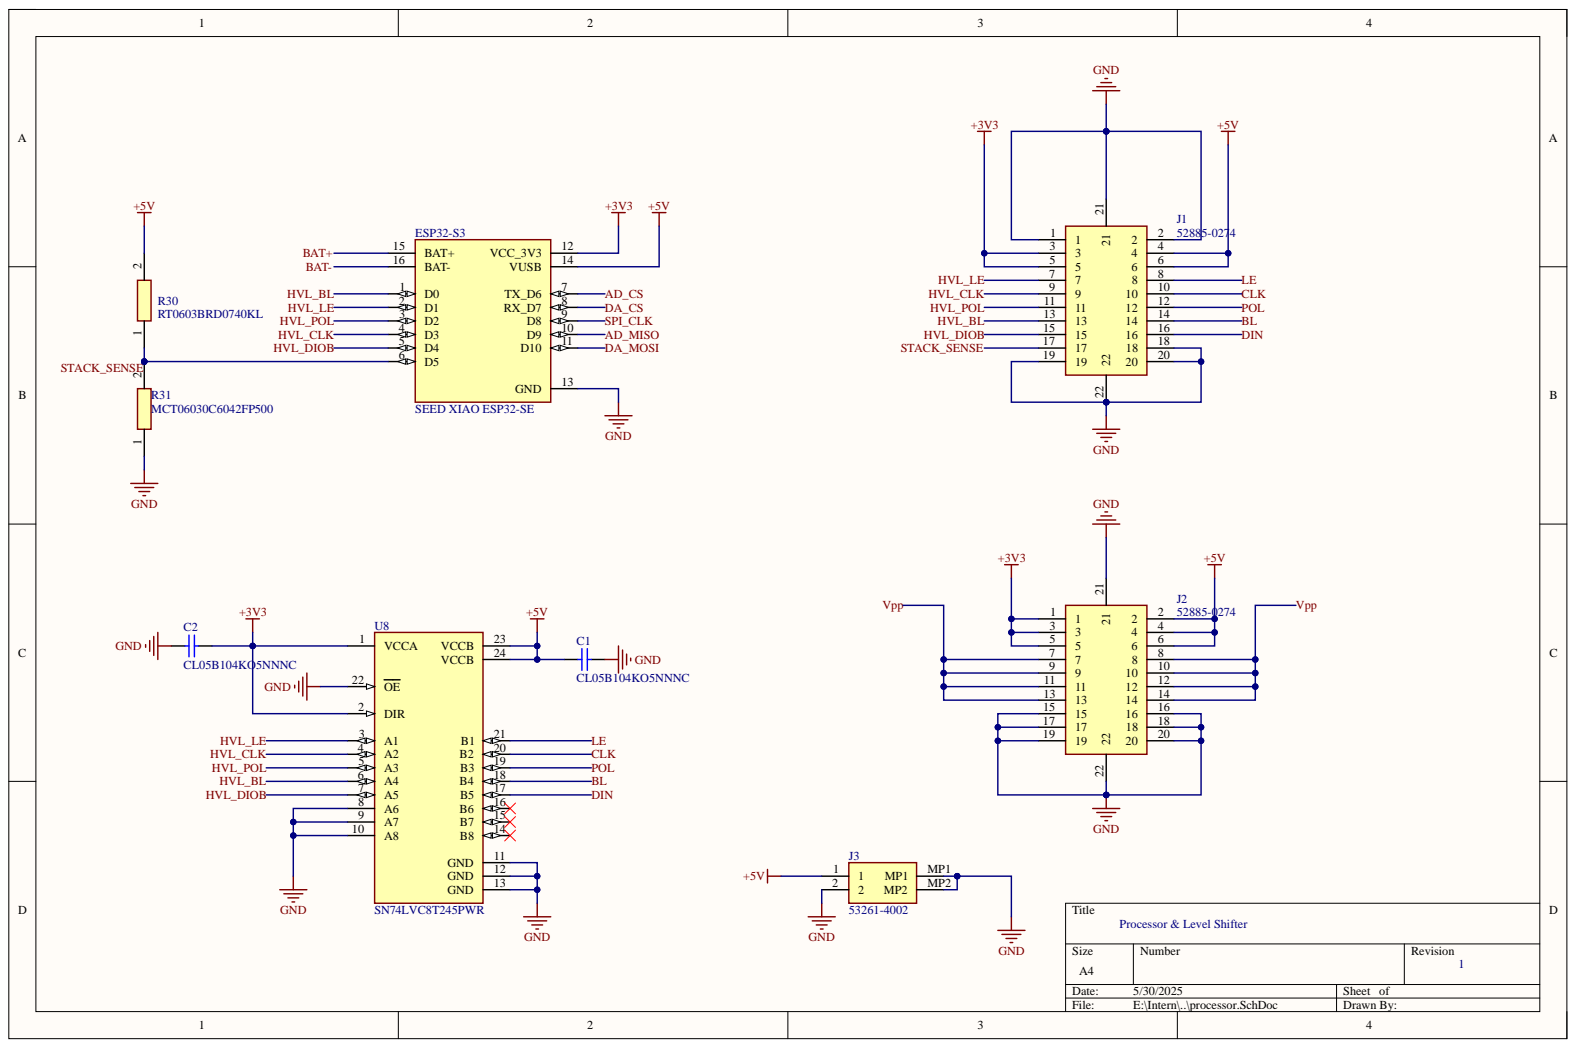
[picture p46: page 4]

Date: 5/30/2025 | Sheet of
File: E:\Intern\..\processor.SchDoc | Drawn By:

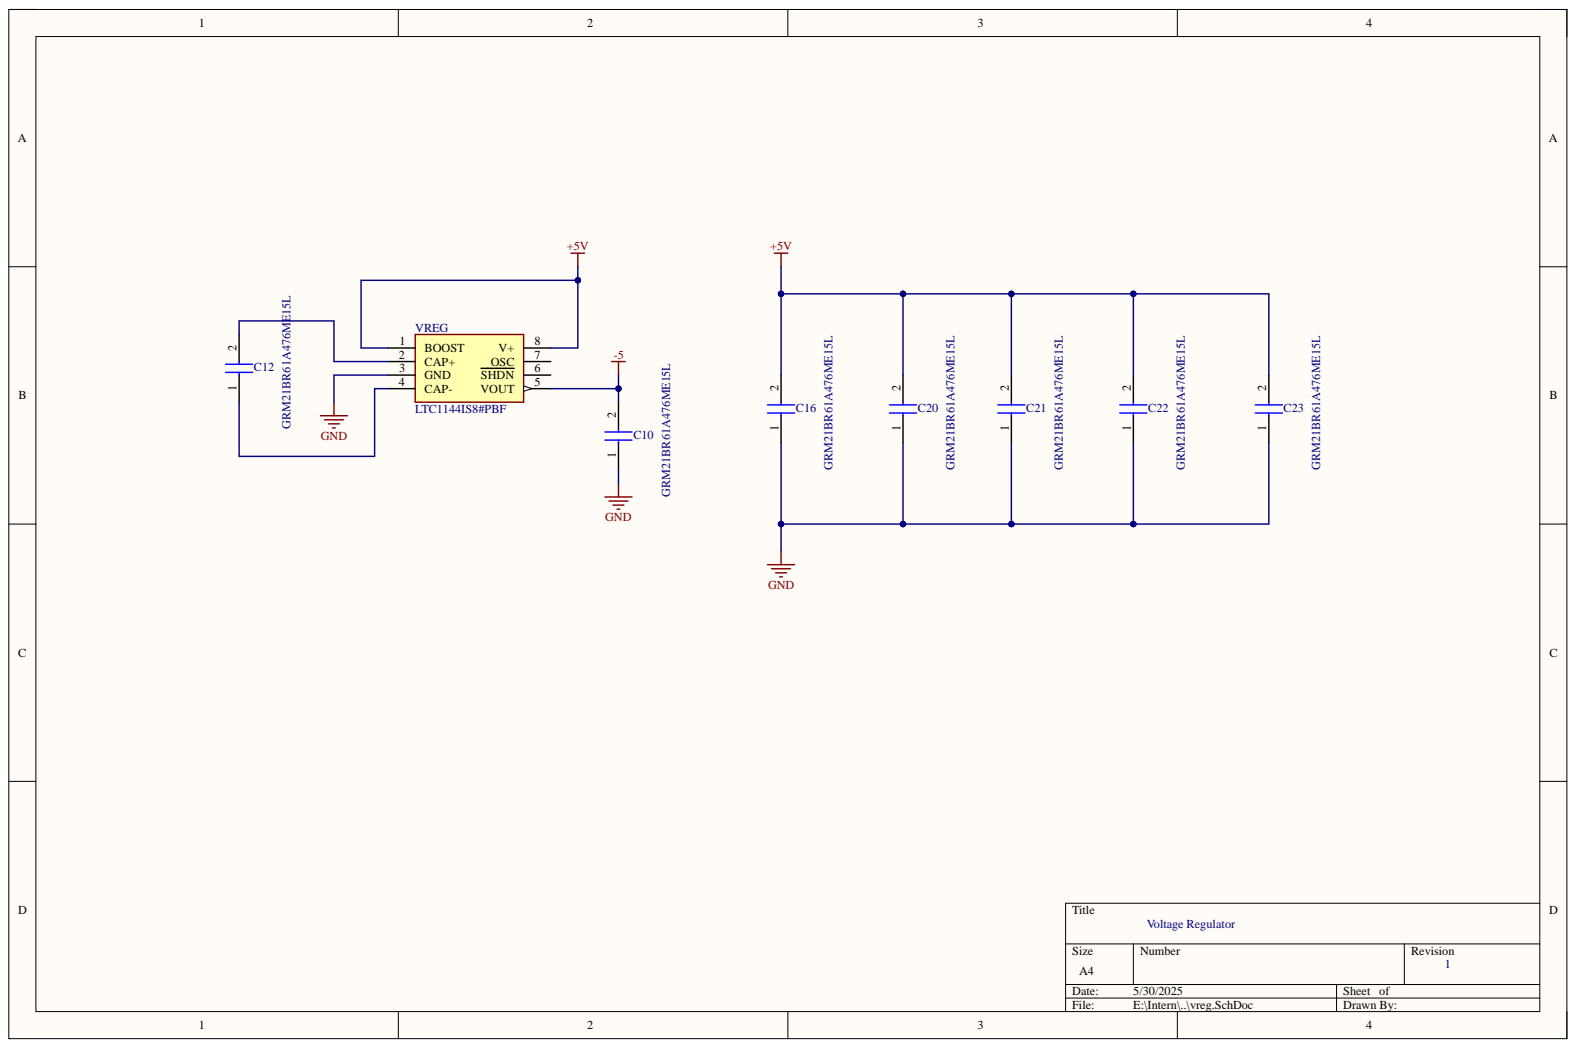
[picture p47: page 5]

Size A 4 | Numbe r | Revision 1

Date: 5/30/2025 | Sheet of
File: E:\Intern\..\vreg.SchDoc | Drawn By:

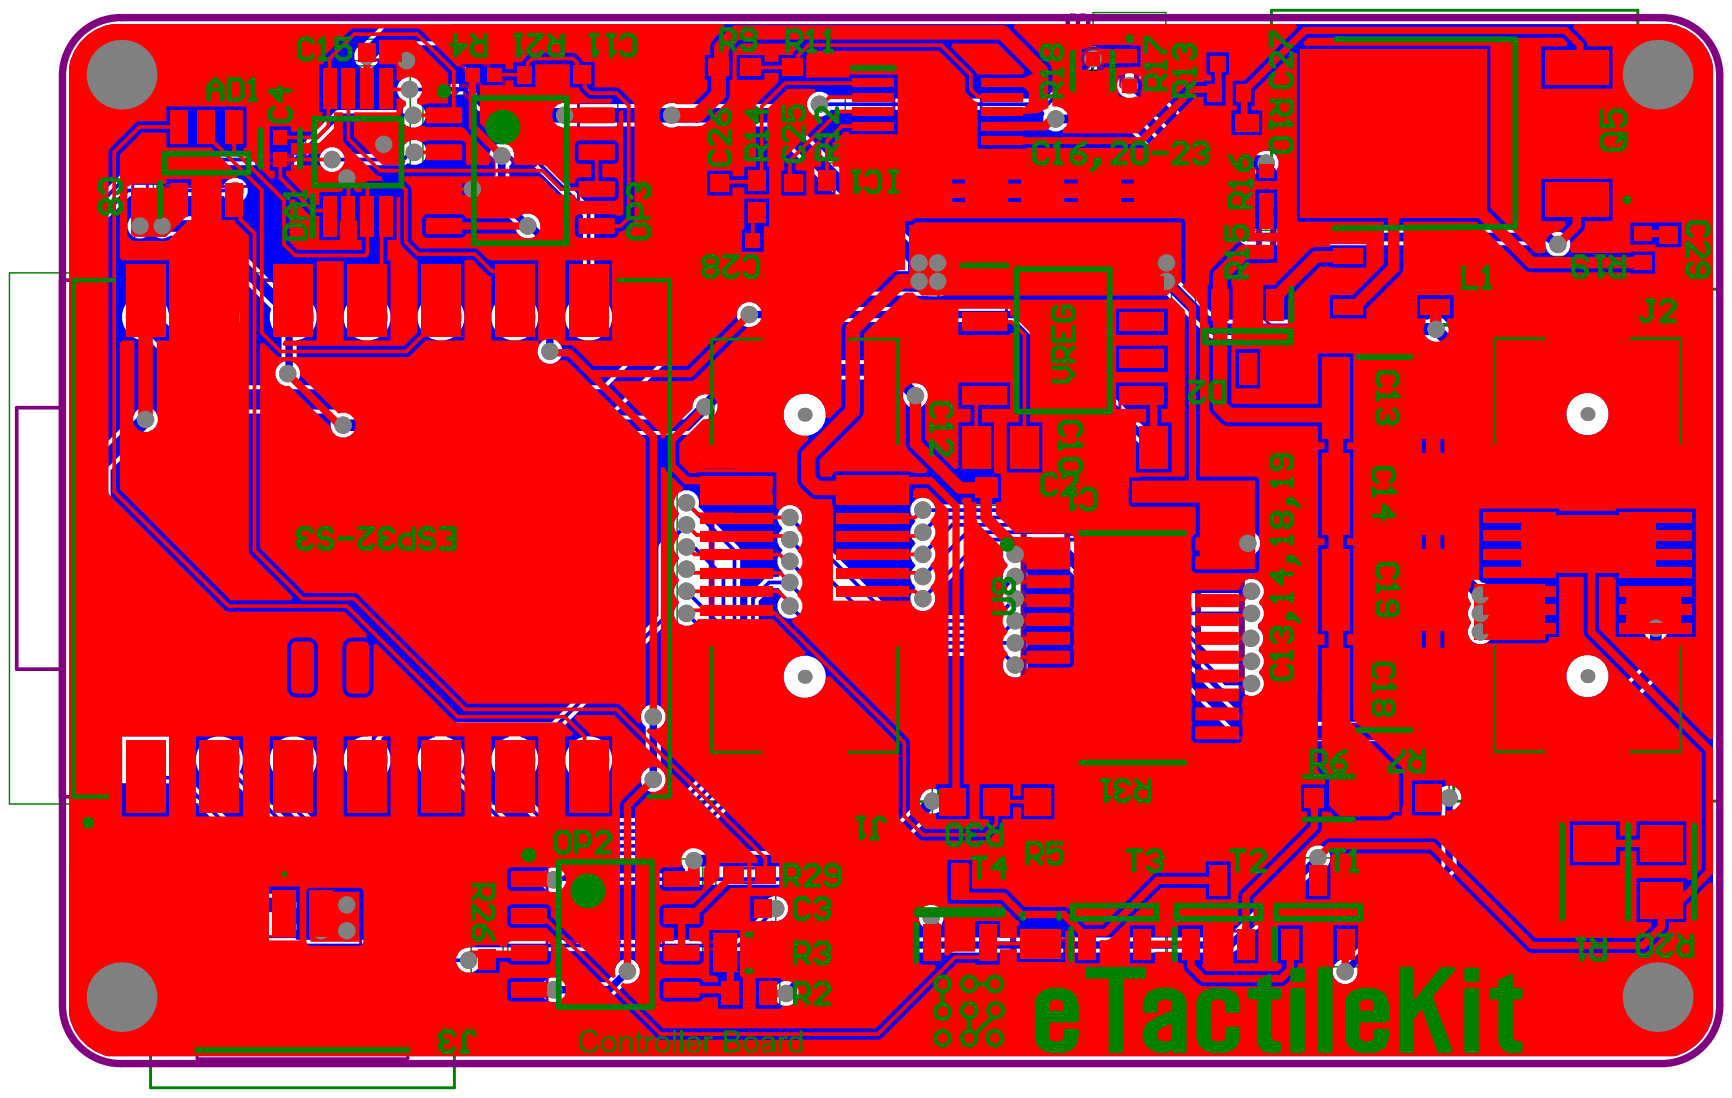
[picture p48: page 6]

Comment | Description | Designator | Footprint | LibRef | Quantity
AD7276AUJZ-REEL7 | Integrated Circuit | AD1 | SOT95P280X100-6N | AD7276AUJZ-REEL7 | 1
CL05B104KO5NNNC | Chip Capacitor, 100 nF, +/- 10%, 16V, -55 to 125degC, 0402 (1005Metric), RoHS, Tapeand Reel | C1, C2 | CAPC1050X55X23ML0 5T13 | CMP-2000-05439-1 | 2
GRM1552C1H102JA01 D | Capacitor | C3 | CAPC1005X70N | GRM1552C1H102JA01 D | 1
0402CG2R0C500NT | Multi-Layer Ceramic Capacitor 2pFC0G ±0.1pF0402Paper T/R | C4 | FP-GJM155-0_05-IPC_C | CMP-2008-03830-2 | 1
CL05B104KO5NNNC | Capacitor | C8, C11, C15, C25 | CAPC1005X55N | CL05B104KO5NNNC | 4
GRM21BR61A476ME15 L | Capacitor | C10, C12, C16, C20, C21, C22, C23 | CAPC2012X145N | GRM21BR61A476ME15 L | 7
CGA6M4X7R2J683KT0 Y0U | Multilayer Ceramic Capacitors 68nF ±10%630VX7RSMD 1210 | C13, C14, C18, C19 | FP-C3225-200-0_4-IPC_B | CMP-08246-003489-1 | 4
0402CG101J500NT | Capacitor | C26 | CAPC1005X55N | 0402CG101J500NT | 1
0402B103K500NT | CAPCER10000PF50V X7R0402 | C27 | FP-C0402-BB-MFG | CMP-2008-02109-2 | 1
885012205033 | 885012205033 Ceramic Capacitor 22nF, 16VDC, 0402, ±10% | C28 | WCAP-CSGP_0402_L1W0.5H0 .5 | CMP-03913-53703171-1 | 1
GRM1555C1H221JA01 D | Capacitor | C29 | CAPC1005X70N | GRM1555C1H221JA01 D | 1
GSD2004S-HE3-08 | Diode | D2 | SOT95P248X115-3N | GSD2004S-HE3-08 | 1
AD5452YRMZ-REEL7 | Integrated Circuit | DA1 | SOP65P490X110-8N | AD5452YRMZ-REEL7 | 1
SEEDXIAOESP32-SE | | ESP32-S3 | PCBComponent_1 | Component_1 | 1
LT3757EMSE#PBF | Integrated Circuit | IC1 | SOP50P490X110-11N | LT3757EMSE#PBF | 1
52885-0274 | Connector | J1, J2 | 528850274 | 52885-0274 | 2
53261-4002 | Connector | J3 | 532614002 | 53261-4002 | 1
ATB322515 | | L1 | ATB322515 | ATB322515 | 1
TL072IDR | Dual Low-NoiseJFET-Input General-PurposeOperational Amplifier, 7to 36V, -40to 85degC, 8-pin SOIC(D8), Green (RoHS&no Sb/Br) | OP2, OP3 | D0008A_L | CMP-0015-00084-2 | 2
IPD25N06S4L30ATMA 2 | MOSFET(N-Channel) | Q5 | IPD25N06S4L30ATMA 2 | IPD25N06S4L30ATMA 2 | 1
ESR10EZPJ333 | 33kΩ±5%0.4W0805 Anti-SurgeChip Resistor AEC-Q200 | R1, R20 | FP-ESR10-IPC_A | CMP-08839-028569-1 | 2
RC0603FR-071ML | Chip Resistor, 1 MOhm, +/- 1%, 100 mW, -55to 155degC, 0603(1608Metric), RoHS, Tapeand Reel | R2 | RESC1608X55X25LL10 T15 | CMP-1659-00056-1 | 1
CRCW08059K10FKEA | RESThick Film, 9.1kΩ, 1%, 0.125W, 100ppm/°C, 0805 | R3 | FP-CRCW0805-e3-IPC_C | CMP-2001-04176-2 | 1
RC0402FR-0712KL | RESSMD12KOHM1% 1/16W0402 | R4 | FP-RC0402-0_4-IPC_C | CMP-2002-07378-2 | 1
CRCW08052K20FKEA | RESThick Film, 2.2kΩ, 1%, 0.125W, 100ppm/°C, 0805 | R5 | FP-CRCW0805-e3-IPC_B | CMP-2001-03760-2 | 1
CRCW040227K0FKED | RESThick Film, 27kΩ, 1%, 0.063W, 100ppm/°C, 0402 | R6 | FP-CRCW0402-e3-IPC_A | CMP-2002-08431-2 | 1
RK73H1JTTD1001F | Resistor | R7 | RESC1608X55N | RK73H1JTTD1001F | 1
RK73H1ETTP1003F | Resistor | R9 | RESC1005X40N | RK73H1ETTP1003F | 1
RTT03R020FTP | METALCURRENT SENSOR04021%150 | R10 | FP-PA0402-MFG | CMP-03412-023933-1 | 1
RK73H1ETTP4702F | Resistor | R11 | RESC1005X40N | RK73H1ETTP4702F | 1
RK73H1ETTP1303F | Resistor | R12 | RESC1005X40N | RK73H1ETTP1303F | 1
RC0402FR-0722RL | | R13, R19 | FP-RC0402-0_4-MFG | CMP-2002-07520-2 | 2
RK73H1ETTP6801F | Resistor | R14 | RESC1005X40N | RK73H1ETTP6801F | 1
ERJU02F1004X | Resistor | R15, R16, R17 | ERJS02_U02_(0402) | ERJU02F1004X | 3
CRCW040216K0FKED | RESThick Film, 16kΩ, 1%, 0.063W, 100ppm/°C, 0402 | R18 | FP-CRCW0402-e3-IPC_C | CMP-1011-00644-3 | 1
HPCR0402F24K0K9 | RESSMD12KOHM1% 1/16W0402 | R21 | FP-RT0402-MFG | CMP-03412-008661-1 | 1
MCS04020C1002FE000 | Resistor | R26 | RESC1005X37N | MCS04020C1002FE000 | 1
RK73H1ETTP1000F | Resistor | R29 | RESC1005X40N | RK73H1ETTP1000F | 1
RT0603BRD0740KL | Resistor | R30 | RESC1608X55N | RT0603BRD0740KL | 1
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

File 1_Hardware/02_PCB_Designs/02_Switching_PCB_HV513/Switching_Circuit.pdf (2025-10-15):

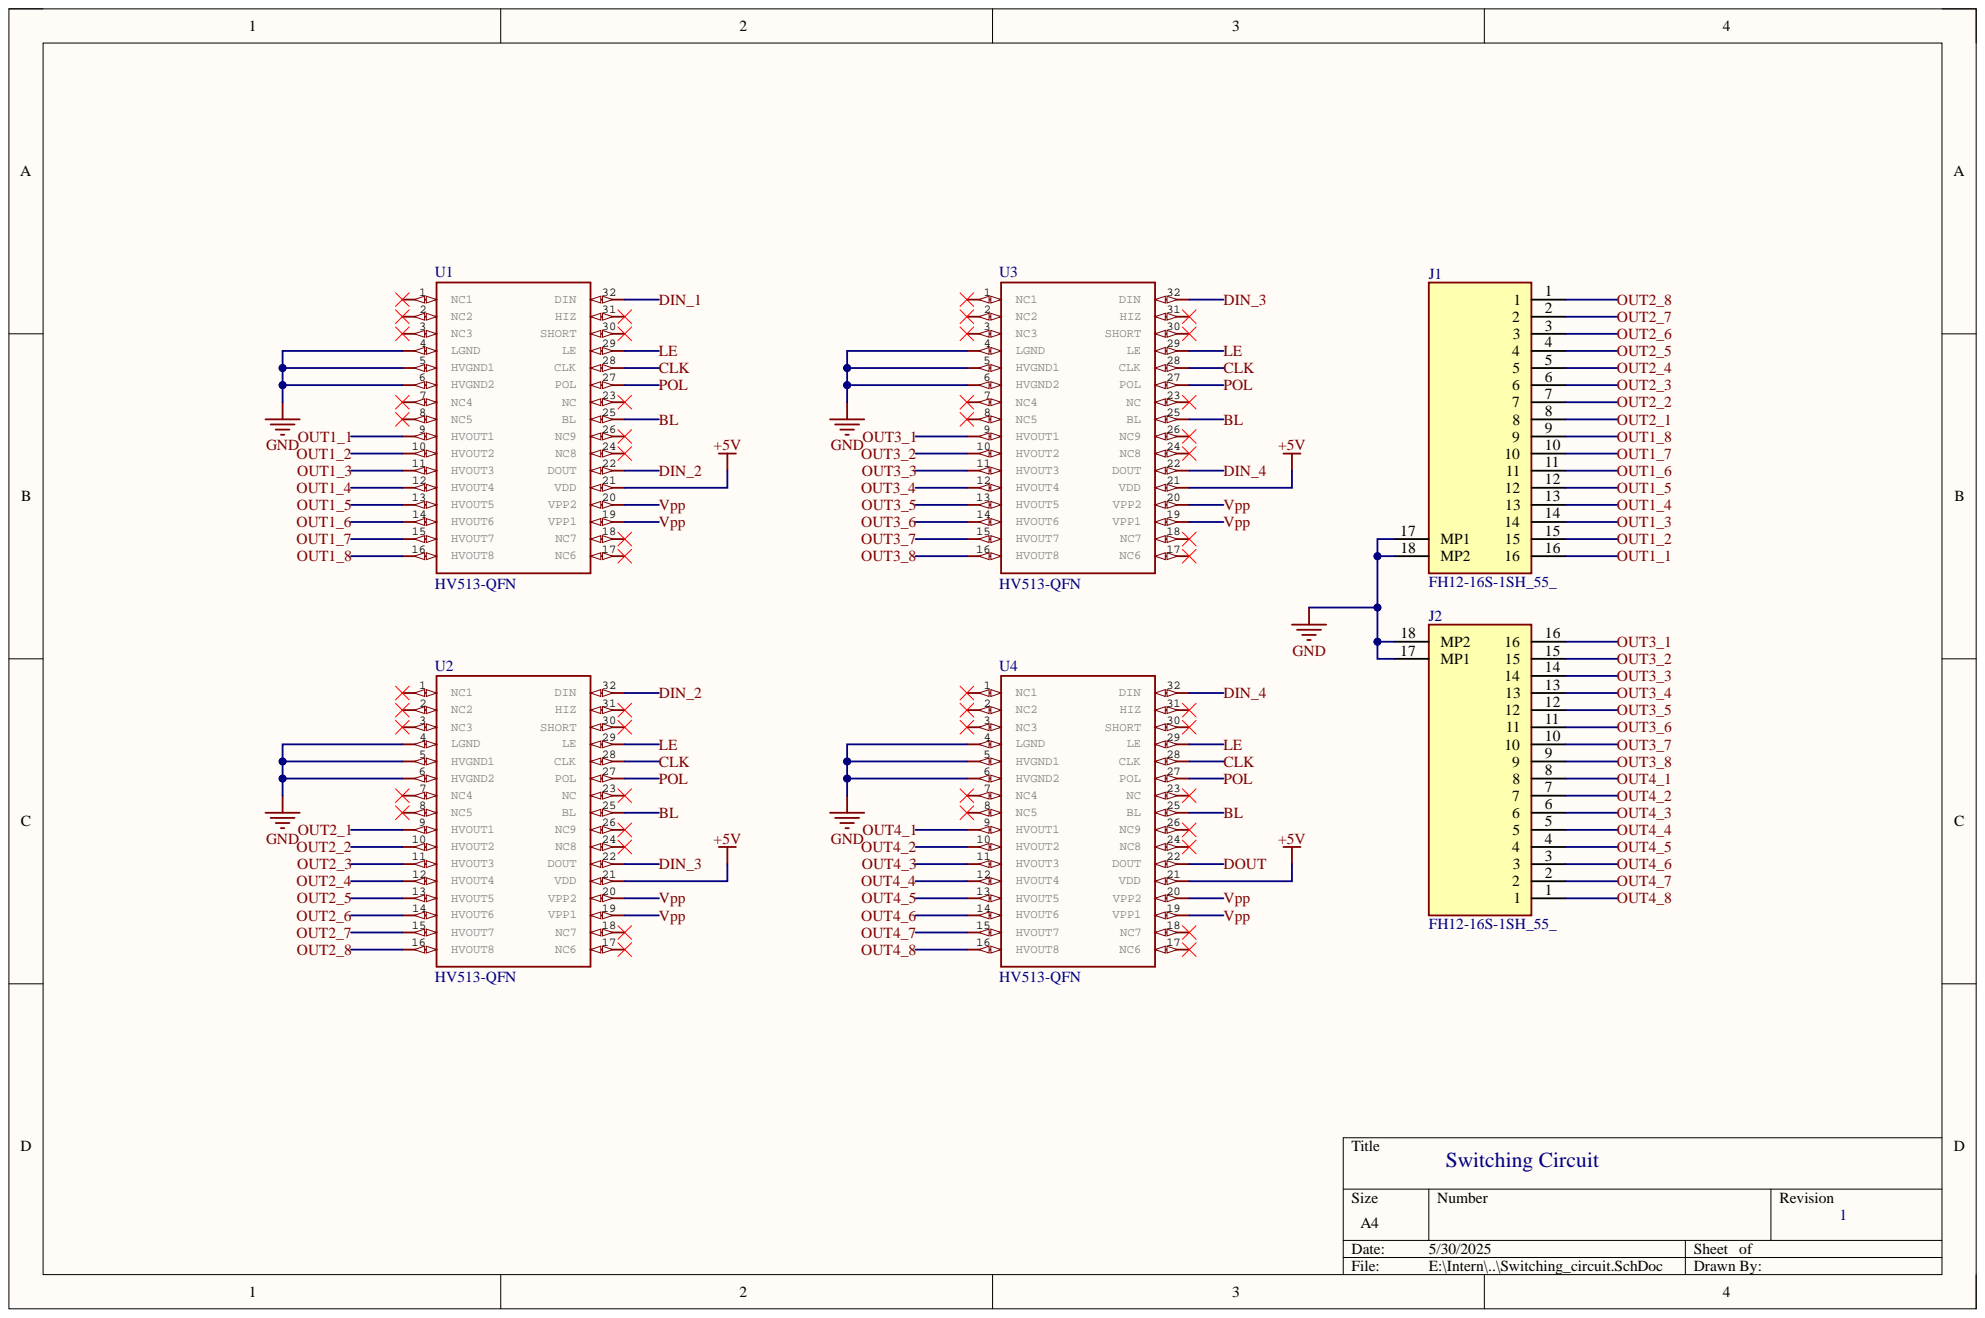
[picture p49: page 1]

Size A 4 | Numbe r | Revision 1

Date: 5/30/2025 | Sheet of
File: E:\Intern\..\Switching_circuit.SchDoc | Drawn By:

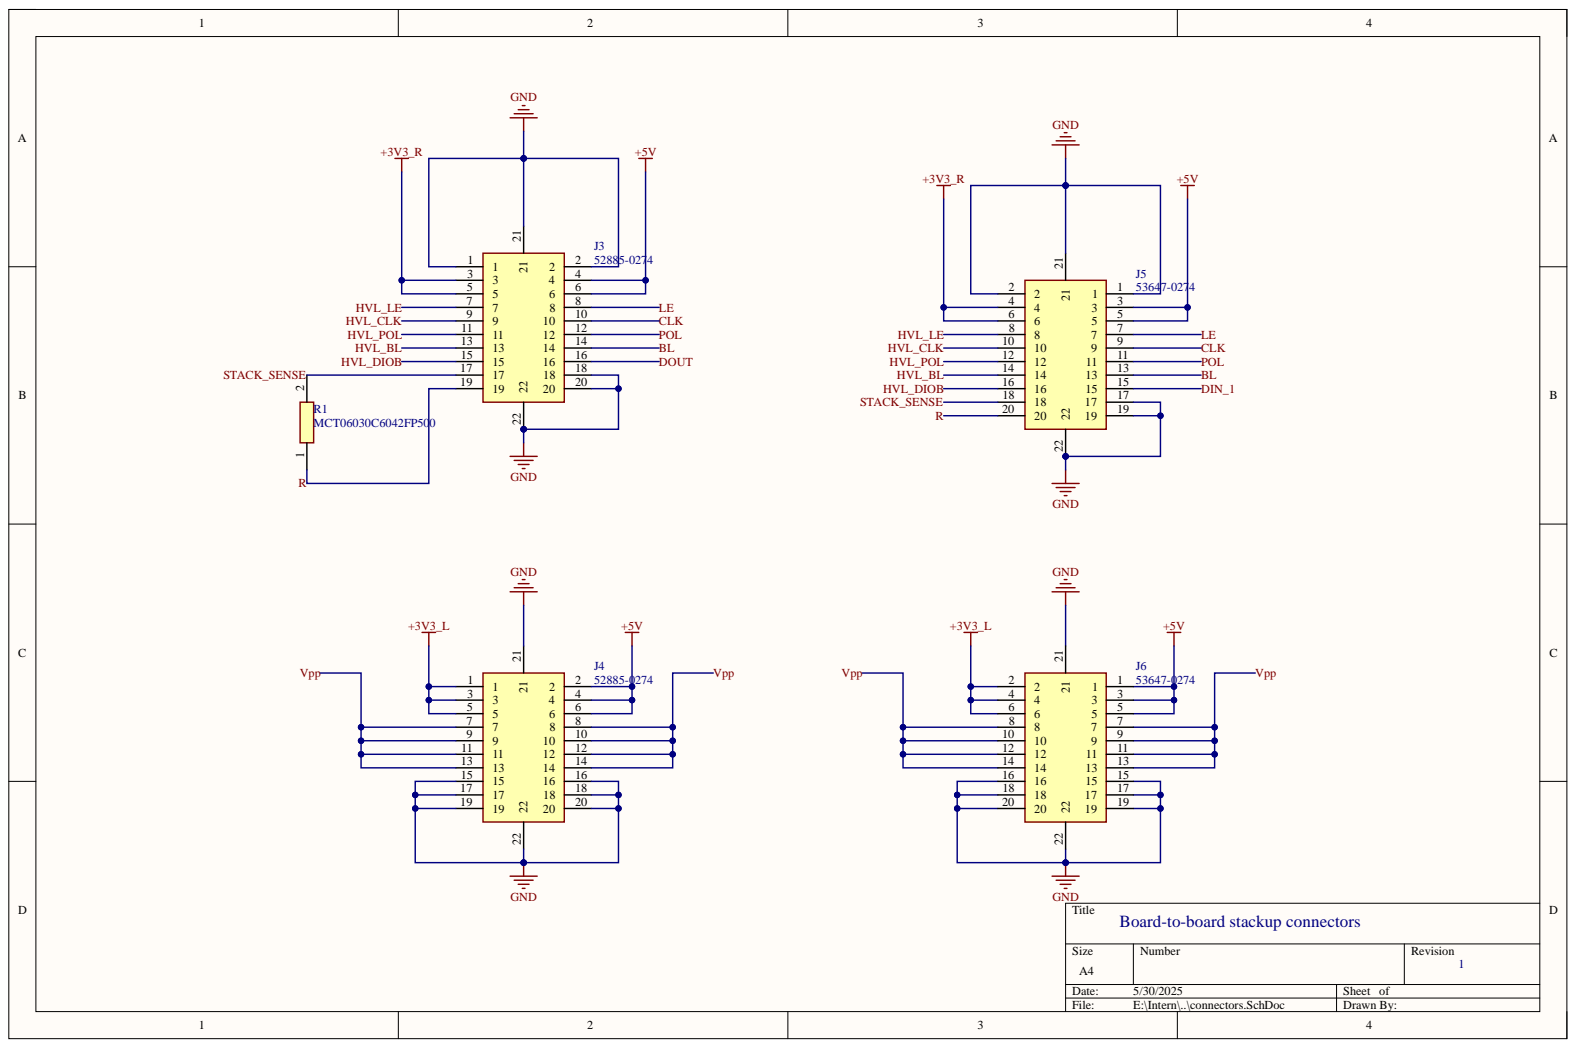
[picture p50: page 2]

Board-to-board stackup connectors

Size A 4 | Numbe r | Revision 1

Date: 5/30/2025 | Sheet of
File: E:\Intern\..\connectors.S chDoc | Drawn By:

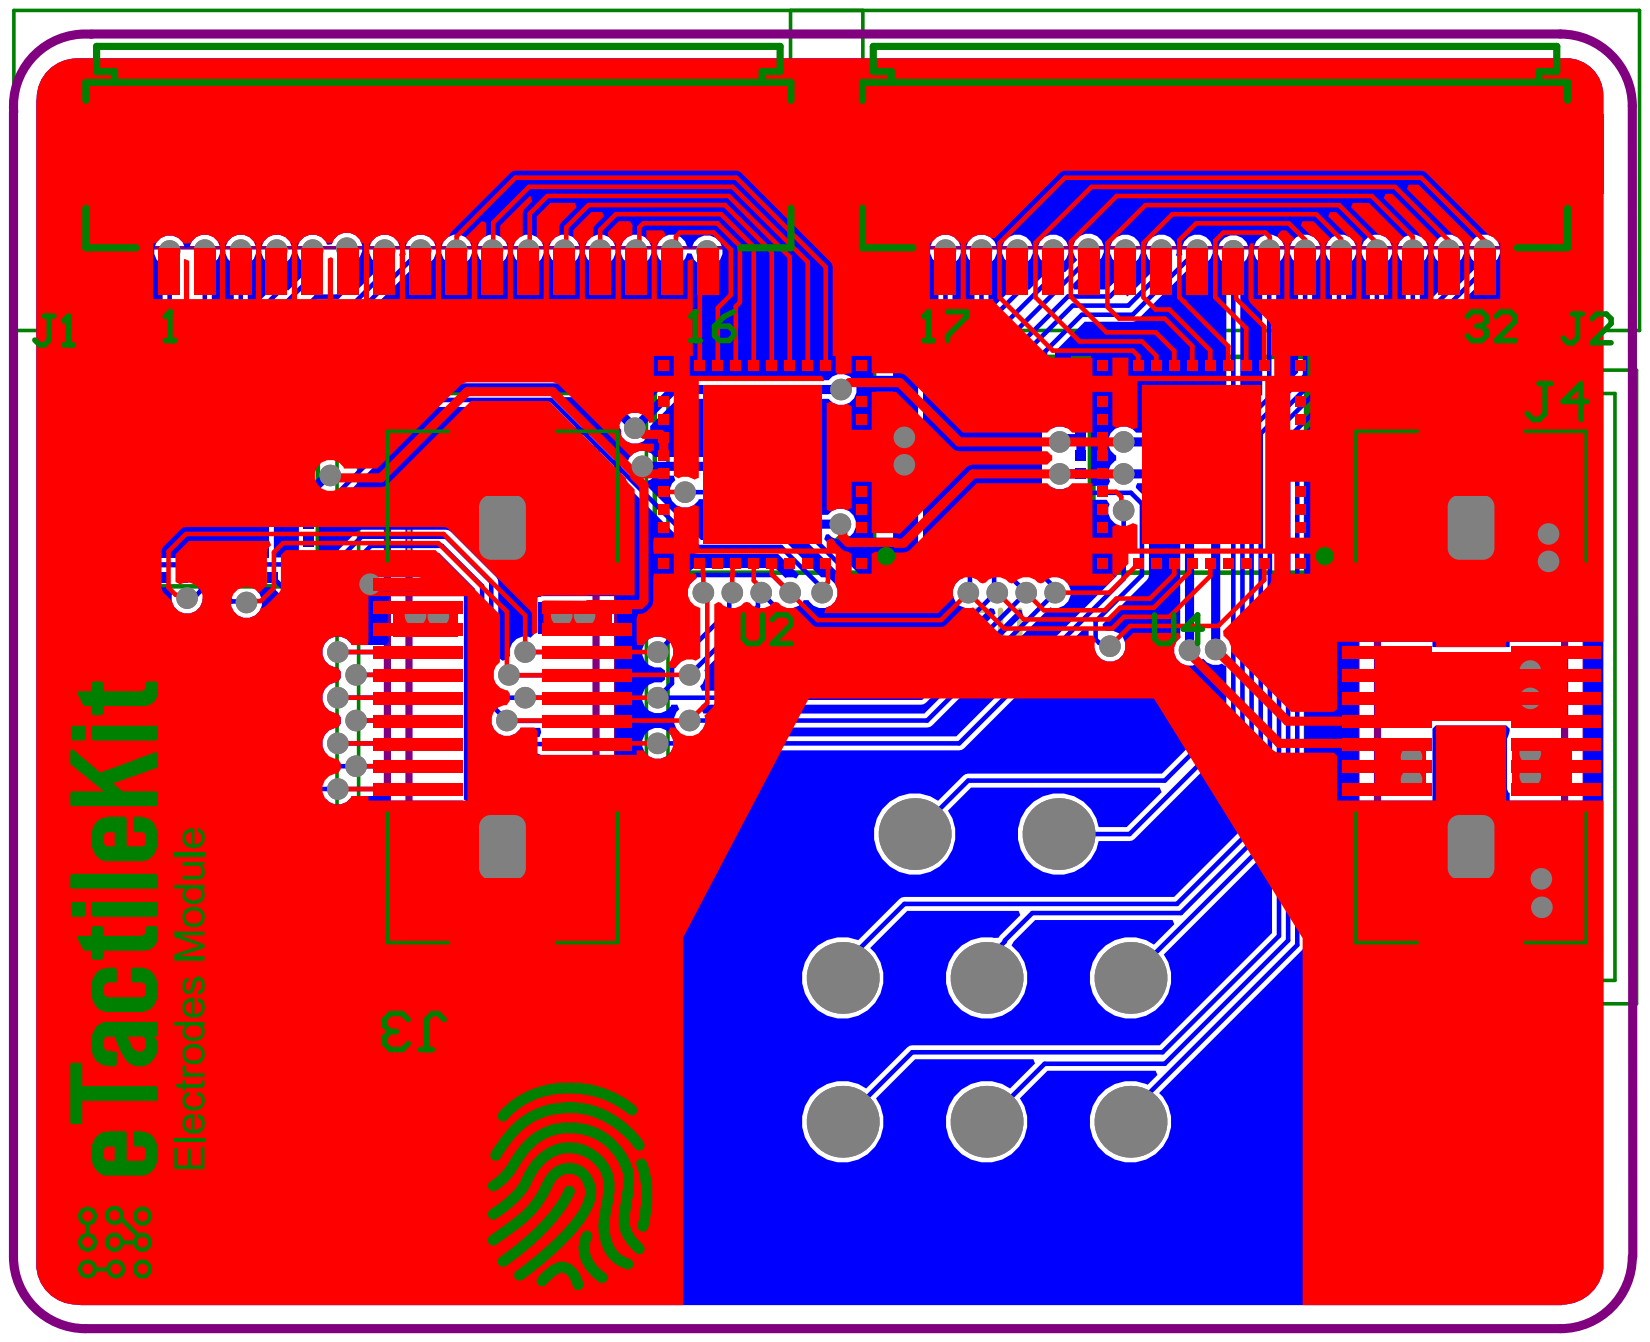
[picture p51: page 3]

Comment | Description | Designator | Footprint | LibRef | Quantity
FH12-16S-1SH_55_ | Connector | J1, J2 | FH1216S1SH55 | FH12-16S-1SH_55_ | 2
52885-0274 | Connector | J3, J4 | 528850274 | 52885-0274 | 2
53647-0274 | Connector | J5, J6 | 536470274 | 53647-0274 | 2
MCT06030C6042FP500 Resistor | | R1 | RESC1608X55N | MCT06030C6042FP500 | 1
HV513-QFN | | U1, U2, U3, U4 | PCBComponent_1 | Component_1 | 4

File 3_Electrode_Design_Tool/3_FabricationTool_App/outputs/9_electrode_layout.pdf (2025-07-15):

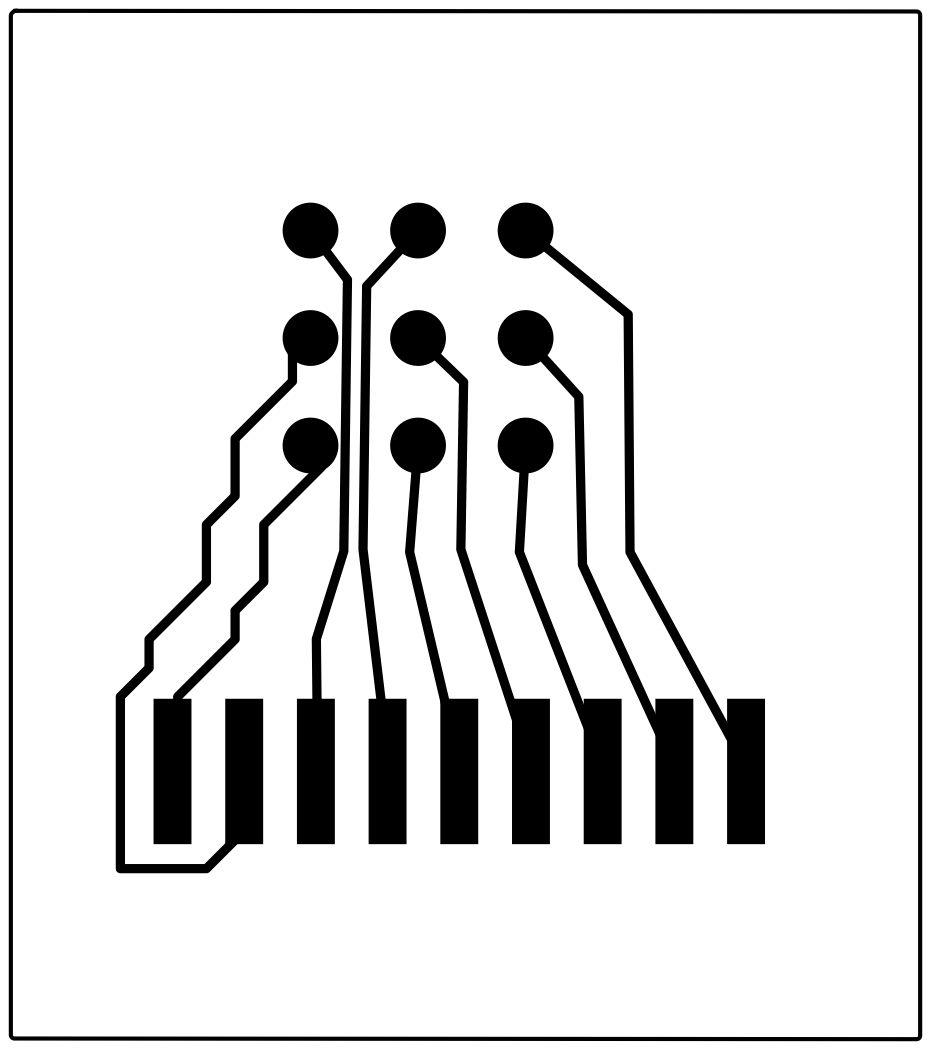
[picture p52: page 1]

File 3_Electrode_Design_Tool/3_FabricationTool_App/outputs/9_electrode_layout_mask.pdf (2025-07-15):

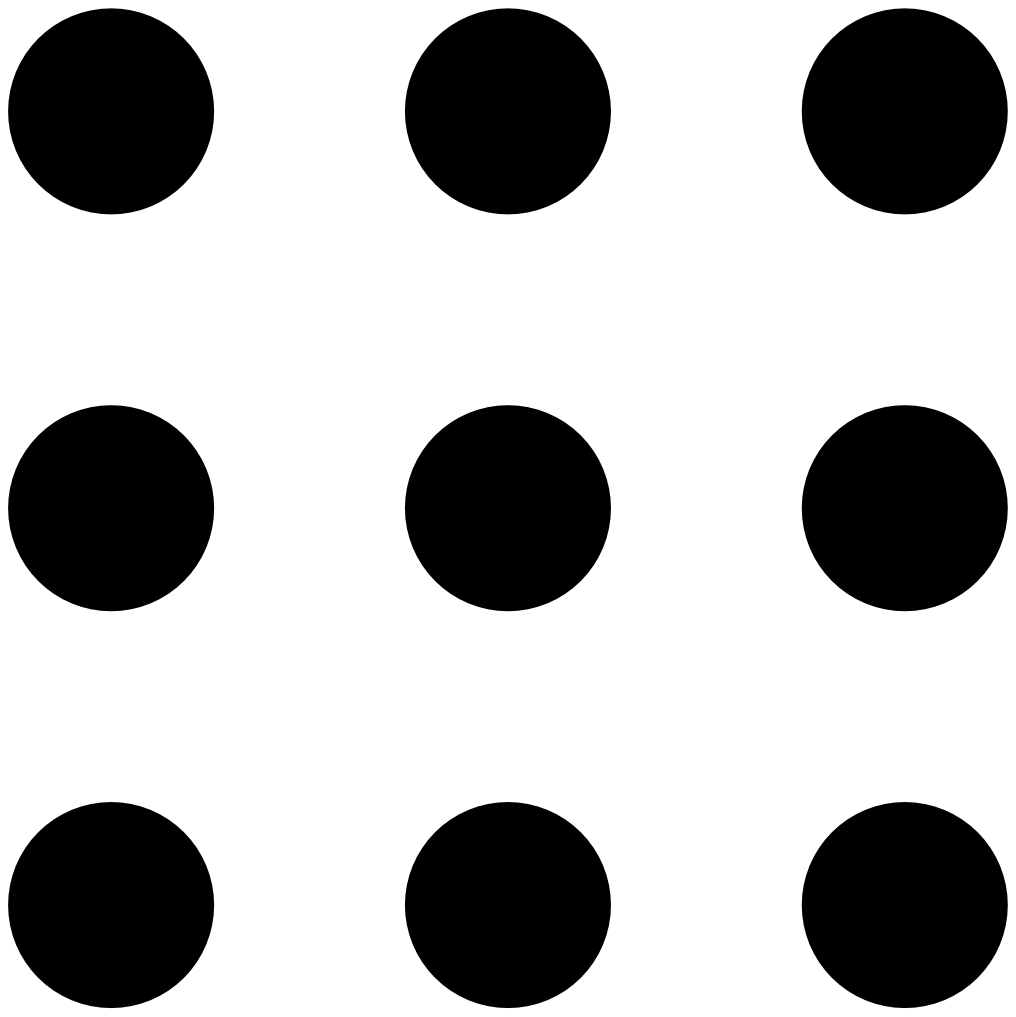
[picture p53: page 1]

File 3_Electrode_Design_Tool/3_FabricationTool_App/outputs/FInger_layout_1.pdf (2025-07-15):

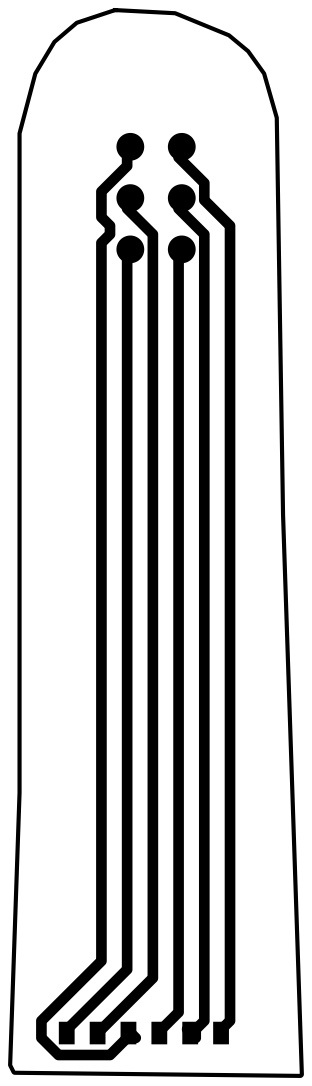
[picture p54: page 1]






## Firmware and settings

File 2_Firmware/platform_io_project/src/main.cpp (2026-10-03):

#include <Arduino.h>
#include "etactilekit.h"

void setup() {
  initEtactileKit();
}

void loop() {
  /*Host communication runs in its own task on core 0; stimulation runs in a timer interrupt on core 1*/
  /***********************************************/
  /*Add your code here*/
  /*loop() runs on core 1 between stimulation scans. The USB serial port carries the eTactileKit protocol, so do not use Serial, printf or std::cout (stdout is mirrored onto it)*/
  /***********************************************/
  delay(1);
}

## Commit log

2025-10-15 eTactileKit - Release v1.1
    [ATB322515.PcbLib, ATB322515.SchLib, DAC_ADC.SchDoc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]
2026-04-13 ADD - eTactilekit hardware version 2 with wireless communication support
    [01_wrist_band_sqr_pad.PrjPcb, 03_Controller_Board_BOM.xlsx, 04_Switching_PCB_BOM.xlsx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]
2026-07-10 ADD - added interaction GUI tool (WINDOWS-ONLY)
    [StanfordBunny.obj]
2026-07-11 ADD - unique SSID to work with Multiple boards
